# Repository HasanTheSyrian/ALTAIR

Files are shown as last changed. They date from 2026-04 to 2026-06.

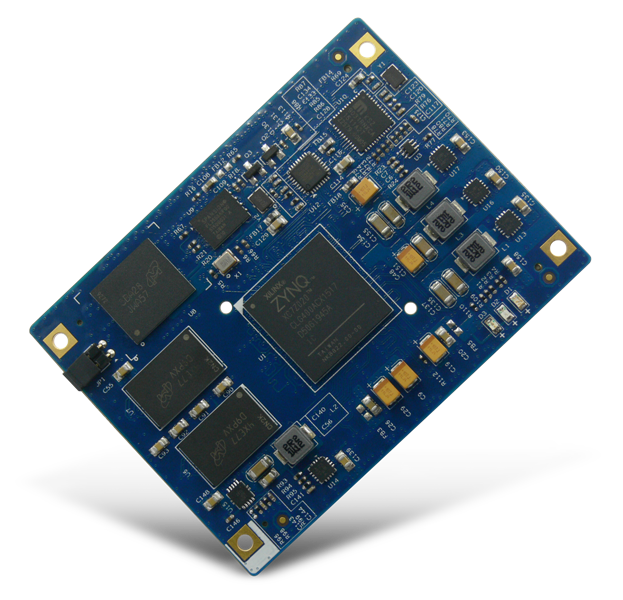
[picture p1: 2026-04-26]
Documentation/MYIR Hardware/Mechanical/images/MYC-C7Z010 20_7.png

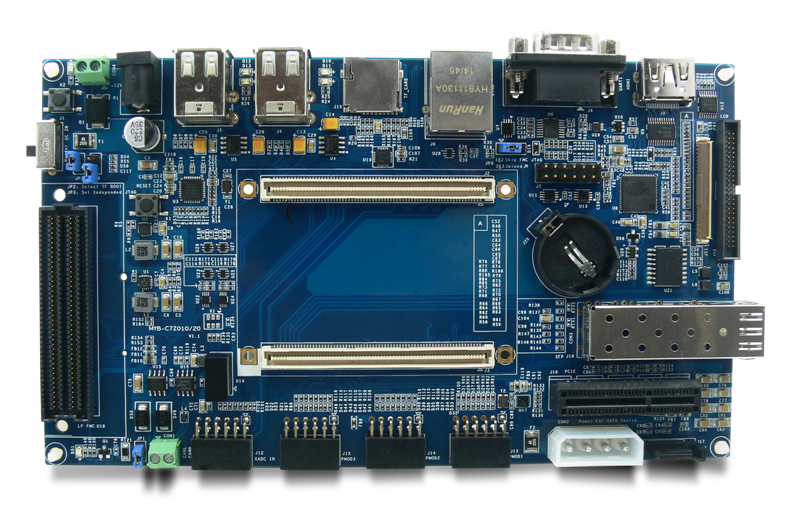
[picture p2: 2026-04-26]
Documentation/MYIR Hardware/Mechanical/images/MYD-C7Z010 20_6.png

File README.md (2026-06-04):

ALTAIR


17 light-years away lies Altair, a star in the Aquila constellation. Altair is the short-form transliteration of Al-Nisr Al-Ta'ir (النسر الطائر) or "The Flying Eagle"; a predator known for its excellent vision.

Altair is an FPGA development board focused on image processing, specifically, stereoscopic depth calculation enabled by two MIPI camera connectors and two HDMI outputs. The board implements XAPP894 since MIPI is not supported natively by Zynq 7000. The development board is built around the MYC-C7Z010_20 SOM. This board is also my graduation project/thesis for my Mechatronics Engineering degree.

---
NOTE: THIS BOARD IS NOT TESTED FULLY YET - SEE BRINGUP SECTION BELOW
### Docs
This board is built with the MYIR MYC-C7Z020-V2 SOM. MYIR documents can only be downloaded after providing the serial number of the MYC-C7Z020-V2 purchased, unfortunately, I can't share mine. Most MYIR hardware documents can be downlodaded from this repository. I haven't included software documents/code because the file size is too big however you can probably find them online elsewhere.

AltairNotes PDF contains my notes I have written over the ~2 years I have been working on this project. Some information is basic stuff about PCB routing and some information documents how I have configured and routed my board. I combined software and hardware PDFS into PDF files ending in "COMBINED" so you can easily search for what you want.

I have also created a YouTube series that talks about the design which can be seen [here](https://www.youtube.com/@hasanthesyrian_).

Not all references are included because I'm not sure if they can be shared directly, however, you should be able to just search for them and download them from their official source.

#### Most important/relevant
| Title | Notes |
| --- |---|
| HARDWARE DOCS COMBINED | MYIR Docs  |
| MYC-C7Z010-20-V2 Hardware Design Guide-V1.0 | MYIR Docs  |
| SOFTWARE DOCS COMBINED | MYIR Docs  |
| MYB-C7Z010_20-V2 Schematic | MYIR Docs  |
| MYD-C7Z01020-V2 PinOuts | MYIR Docs, SOM Pinout  |
| MYC-C7z010-V12-SOM-NET-LENGTH | MYIR Docs  |
| ADV7511_Hardware_Users_Guide | HDMI IC |
| [Zynq 7000 SoC Technical Reference Manual](https://docs.amd.com/r/en-US/ug585-zynq-7000-SoC-TRM) | UG585  |
| [Zynq-7000 SoC PCB Design Guide](https://docs.amd.com/v/u/en-US/ug933-Zynq-7000-PCB) | UG933  |
| [7 Series FPGAs SelectIO Resources User Guide](https://docs.amd.com/v/u/en-US/ug471_7Series_SelectIO) | UG471  |
| [Zynq-7000 SoC Packaging and Pinout Product Specification](https://docs.amd.com/v/u/en-US/ug865-Zynq-7000-Pkg-Pinout) | UG865  |
| xc7z020clg400pkg (.txt) | FPGA Package Pinout  |

#### Board schematics used as references in part
| Title | Notes |
| --- |---|
| MYB-C7Z010_20-V2 Schematic | MYIR Docs  |
| arty_z7_sch | |
| digilent-smt3-reversed-sch | Reverse engineered programmer published on IEEE  |
| eclypse_z7_sch | |
| minized_sch | |
| mizar_z7-sch | |
| pynq-z1_sch | |
| pynq-z2_sch | |
| rehsd_sch | rehsd on YouTube  |
| snickerdoodle_sch | |
| trenz_carrier_TE0701_sch | |
| zc702_sch | |
| zc706-sch | |
| trenz_carrier_TE0701_sch | |
| zc702_sch | |
| zedboard_sch | |
| zybo-z7_sch | |
| zynqberry2010_sch | |
| zynqberry-zero_sch | |
| camera-module-3-schematics | Raspberry Pi |
| cm4io-datasheet | Raspberry Pi |
| raspberry-pi-4-reduced-schematics | Raspberry Pi |

#### AMD Documentaion
| Title | Code |
| --- | --- |
| [Zynq 7000 SoC Technical Reference Manual](https://docs.amd.com/r/en-US/ug585-zynq-7000-SoC-TRM) | UG585  |
| [Zynq-7000 SoC PCB Design Guide](https://docs.amd.com/v/u/en-US/ug933-Zynq-7000-PCB) | UG933  |
| [Zynq-7000 SoC Data Sheet: Overview](https://docs.amd.com/v/u/en-US/ds190-Zynq-7000-Overview) | DS190  |
| [Zynq-7000 SoC Packaging and Pinout Product Specification](https://docs.amd.com/v/u/en-US/ug865-Zynq-7000-Pkg-Pinout) | UG865  |
| [Zynq 7000 SoC and 7 Series Devices Memory Interface Solutions User Guide](https://docs.amd.com/r/en-US/ug586_7Series_MIS/DDR3-and-DDR2-SDRAM-Memory-Interface-Solution) | UG586  |
| [DDR2/DDR3 Low-Cost PCB Design Guidelines for Artix-7/Spartan-7 FPGAs White Paper](https://docs.amd.com/v/u/en-US/wp484-a7-s7-ddr2-3-pcb) | WP484  |
| [7 Series FPGAs and Zynq-7000 SoC XADC Dual 12-Bit 1 MSPS Analog-to-Digital Converter User Guide](https://docs.amd.com/r/en-US/ug480_7Series_XADC) | UG480  |
| [Zynq-7000 SoC Product Selection Guide](https://docs.amd.com/v/u/en-US/zynq-7000-product-selection-guide) | XMP087 |
| [Artix 7 FPGAs Data Sheet: DC and AC Switching Characteristics](https://docs.amd.com/v/u/en-US/ds181_Artix_7_Data_Sheet) | DS181  |
| [Kintex-7 FPGAs Data Sheet: DC and AC Switching Characteristics](https://docs.amd.com/v/u/en-US/ds182_Kintex_7_Data_Sheet) | DS182  |
| [7 Series FPGAs GTP Transceivers User Guide](https://docs.amd.com/v/u/en-US/ug482_7Series_GTP_Transceivers) | UG482  |
| [7 Series FPGAs GTX/GTH Transceivers User Guide](https://docs.amd.com/v/u/en-US/ug476_7Series_Transceivers) | UG476  |
| [7 Series FPGAs PCB Design Guide](https://docs.amd.com/v/u/en-US/ug483_7Series_PCB) | UG483  |
| [Zynq 7000 SoC Software Developers Guide](https://docs.amd.com/r/en-US/ug821-zynq-7000-swdev) | UG821  |
| [Recommended Design Rules and Strategies for BGA Devices User Guide](https://docs.amd.com/r/en-US/ug1099-bga-device-design-rules) | UG1099 |
| [Zynq-7000 SoC DC and AC Switching Characteristics Data Sheet](https://docs.amd.com/v/u/en-US/ds187-XC7Z010-XC7Z020-Data-Sheet) | DS187  |
| [7 Series FPGAs Configuration](https://docs.amd.com/v/u/en-US/ug470_7Series_Config) | UG470  |
| [MIPI D-PHY LogiCORE IP Product Guide](https://docs.amd.com/r/en-US/pg202-mipi-dphy/Introduction) | PG202  |
| [MIPI CSI-2 Receiver Subsystem Product Guide](https://docs.amd.com/r/en-US/pg232-mipi-csi2-rx) | PG232  |
| [Xilinx FPGA Video Design Hub](https://docs.amd.com/v/u/en-US/dh0083-video-hub) | DH235  |
| [HDMI 1.4/2.0 Transmitter Subsystem Product Guide](https://docs.amd.com/r/en-US/pg235-v-hdmi-tx-ss/Introduction?tocId=XLSPfpAut4Tw1N_71V9XKQ) | PG235  |
| [Vivado Design Suite User Guide: I/O and Clock Planning](https://www.xilinx.com/support/documents/sw_manuals/xilinx2022_1/ug899-vivado-io-clock-planning.pdf) | UG899  |
| [7 Series FPGAs SelectIO Resources User Guide](https://docs.amd.com/v/u/en-US/ug471_7Series_SelectIO) | UG471  |

### Other helpful links

| Title | Notes | Code |
| --- | --- | --- |
| [Xilinx Power Estimator](https://www.xilinx.com/products/technology/power/xpe.html) | | |
| [Digilent Arty Z7 Schematics](https://digilent.com/reference/_media/reference/programmable-logic/arty-z7/arty_z7_sch.pdf) | | |
| [Digilent Zed Board Schematics](https://digilent.com/reference/_media/reference/programmable-logic/zedboard/zedboard-schematic-rev-e1-public.pdf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) | HDMI schematic on page 5 | |
| [Xilinx XTP185 – ZC702 Schematics](https://e2e.ti.com/cfs-file/__key/communityserver-discussions-components-files/196/zc702_5F00_Schematic_5F00_xtp185_5F00_rev1_5F00_0.pdf) | link instantly downloads pdf | |
| [TI Power Reference Design for Xilinx Zynq-7000](https://www.ti.com/lit/ug/slyu019a/slyu019a.pdf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) | | |
| [Terasic DE2-115 Schematic](https://wiki.bu.ost.ch/infoportal/_media/fpga/cyclone_iv/de2_115_schematic.pdf) | | |
| [Avnet Minized Board Schematics + General knowledge](http://www.ebvnews.ru/doc17/MiniZed-HW-UG-v1-0-V1_0.pdf) | check page 7 | |
| [How to understand Zynq Pins](https://www.avnet.com/wps/portal/us/products/avnet-boards/support/faq/zynq-pins-deep-dive/) | | |
| [Hardware and Layout Design Considerations for DDR3 SDRAM Memory Interfaces](https://hands.com/~lkcl/eoma/rockchip_rk3288/AN3940.pdf) | | |
| [Gigabit Ethernet 101: Basics to Implementation](https://resources.altium.com/p/gigabit-ethernet-101-basics-implementation) | | |
| [Gigabit Ethernet Design Guide](https://ww1.microchip.com/downloads/aemDocuments/documents/OTH/ApplicationNotes/ApplicationNotes/00002054A.pdf) | | |
| [Ethernet PHY PCB Design Layout Checklist](https://www.ti.com/lit/an/snla387/snla387.pdf?ts=1724186585377&ref_url=https%253A%252F%252Fwww.google.com%252F) | | |
| [TPD12S016 HDMI Companion Chip Datasheet](https://www.ti.com/lit/ds/symlink/tpd12s016.pdf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) | | |
| [MIPI D-PHY Standard](https://www.mipi.org/specifications/d-phy#related-resources-anchor) | | |
| [Zynp Pins - Deep Dive: How to understand Zynq Pins](https://www.avnet.com/wps/portal/us/products/avnet-boards/support/faq/zynq-pins-deep-dive/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)  | Useful | |
| [ADV7511 Hardware User's Guide](https://www.analog.com/media/en/technical-documentation/user-guides/ADV7511_Hardware_Users_Guide.pdf) | "actual" datasheet of ADV7511 | |
| [PCB Design Guidelines for QFN and DQFN Packages](https://ww1.microchip.com/downloads/aemDocuments/documents/UNG/ApplicationNotes/ApplicationNotes/AN18.15-PCB-Design-Guide-QFN-DQFN-Packages-00001843.pdf) | USB2415 USB HUB | AN18.15 |
| [USB Device Design Checklist](https://ww1.microchip.com/downloads/aemDocuments/documents/OTH/ApplicationNotes/ApplicationNotes/00001863B.pdf) | USB2415 USB HUB | AN26.21 |
| [PCB Layout Guide for USB Hubs](https://ww1.microchip.com/downloads/aemDocuments/documents/OTH/ApplicationNotes/ApplicationNotes/en562810.pdf) | USB2415 USB HUB | AN15.17 |
| [PMOD Standard](https://digilent.com/reference/_media/reference/pmod/pmod-interface-specification-1_3_1.pdf) | | |
| Texas Instruments HDMI Design Guide | HDMI | |
| [Texas Instruments The IBIS model, Part 3: Using IBIS models to investigate signal-integrity issues](https://www.ti.com/lit/an/slyt413/slyt413.pdf?ts=1754720541924) | | SLYT413 |

<details>
<summary>Processing System Pins Used</summary>
  *mostly accurate, one of the I2Cs highlighted was not used in the final design double check with the schematic
Pasted image 20250327221556
</details>

### Bringup
28/5/2026: I have soldered the power circuit and tested all rails without load and without an oscilloscope, the power circuit at least provides the correct voltages.



### Images







<details>

<summary>Archive</summary>




</details>

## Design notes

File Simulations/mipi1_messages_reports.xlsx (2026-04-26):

Name | Severity | Details
system
General Messages
IP_Flow 19-4965 | Critical Warning | [IP_Flow 19-4965] IP cdc_fifo was packaged with board value 'em.avnet.com:zed:part0:1.4'. Current project's board value is 'digilentinc.com:zybo-z7-20:part0:1.1'. Please update the project settings to match the packaged IP.
IP_Flow 19-4965 | Critical Warning | [IP_Flow 19-4965] IP ila_rxclk was packaged with board value 'em.avnet.com:zed:part0:1.4'. Current project's board value is 'digilentinc.com:zybo-z7-20:part0:1.1'. Please update the project settings to match the packaged IP.
IP_Flow 19-4965 | Critical Warning | [IP_Flow 19-4965] IP ila_rxclk_lane was packaged with board value 'em.avnet.com:zed:part0:1.4'. Current project's board value is 'digilentinc.com:zybo-z7-20:part0:1.1'. Please update the project settings to match the packaged IP.
IP_Flow 19-4965 | Critical Warning | [IP_Flow 19-4965] IP ila_vidclk was packaged with board value 'em.avnet.com:zed:part0:1.4'. Current project's board value is 'digilentinc.com:zybo-z7-20:part0:1.1'. Please update the project settings to match the packaged IP.
IP_Flow 19-4965 | Critical Warning | [IP_Flow 19-4965] IP line_buffer was packaged with board value 'em.avnet.com:zed:part0:1.4'. Current project's board value is 'digilentinc.com:zybo-z7-20:part0:1.1'. Please update the project settings to match the packaged IP.
Synthesis
Out-of-Context Module Runs
system
system_MIPI_CSI_2_RX_0_0_synth_1
Designutils 20-1280 | Critical Warning | [Designutils 20-1280] Could not find module 'ila_vidclk'. The XDC file c:/Users/hasan/Downloads/Zybo-Z7-20-Pcam-5C-hw.xpr/Zybo-Z7-HW/Zybo-Z7-HW.gen/sources_1/bd/system/ip/system_MIPI_CSI_2_RX_0_0/hdl/ila_vidclk/ila_v6_2/constraints/ila.xdc will not be read for any cell of this module.
Designutils 20-1280 | Critical Warning | [Designutils 20-1280] Could not find module 'ila_rxclk_lane'. The XDC file c:/Users/hasan/Downloads/Zybo-Z7-20-Pcam-5C-hw.xpr/Zybo-Z7-HW/Zybo-Z7-HW.gen/sources_1/bd/system/ip/system_MIPI_CSI_2_RX_0_0/hdl/ila_rxclk_lane/ila_v6_2/constraints/ila.xdc will not be read for any cell of this module.
Designutils 20-1280 | Critical Warning | [Designutils 20-1280] Could not find module 'ila_rxclk'. The XDC file c:/Users/hasan/Downloads/Zybo-Z7-20-Pcam-5C-hw.xpr/Zybo-Z7-HW/Zybo-Z7-HW.gen/sources_1/bd/system/ip/system_MIPI_CSI_2_RX_0_0/hdl/ila_rxclk/ila_v6_2/constraints/ila.xdc will not be read for any cell of this module.
Vivado 12-4739 | Critical Warning | [Vivado 12-4739] set_false_path:No valid object(s) found for '-from [get_pins -hierarchical -filter {NAME =~ *allx_typeA_match_detection.ltlib_v1_0_0_allx_typeA_inst/DUT/I_WHOLE_SLICE.G_SLICE_IDX[*].U_ALL_SRL_SLICE/u_srl*/S*/CLK}]'. ["c:/Users/hasan/Downloads/Zybo-Z7-20-Pcam-5C-hw.xpr/Zybo-Z7-HW/Zybo-Z7-HW.gen/sources_1/bd/system/ip/system_MIPI_CSI_2_RX_0_0/hdl/mipi_csi2_rx.xdc":45]
Vivado 12-4739 | Critical Warning | [Vivado 12-4739] set_false_path:No valid object(s) found for '-from [get_pins -hierarchical -filter { NAME =~ "*ila_core_inst/u_ila_cap_ctrl/u_cap_addrgen/u_cap_sample_counter/u_scnt_cmp/allx_typeA_match_detection.ltlib_v1_0_0_allx_typeA_inst/DUT/I_WHOLE_SLICE.G_SLICE_IDX[*].U_ALL_SRL_SLICE/u_srl*/S*/CLK*"}]'. ["c:/Users/hasan/Downloads/Zybo-Z7-20-Pcam-5C-hw.xpr/Zybo-Z7-HW/Zybo-Z7-HW.gen/sources_1/bd/system/ip/system_MIPI_CSI_2_RX_0_0/hdl/mipi_csi2_rx.xdc":50]
Vivado 12-4739 | Critical Warning | [Vivado 12-4739] set_false_path:No valid object(s) found for '-from [get_pins -hierarchical -filter { NAME =~ "*ila_core_inst/u_ila_cap_ctrl/u_cap_addrgen/u_cap_window_counter/u_wcnt_lcmp/allx_typeA_match_detection.ltlib_v1_0_0_allx_typeA_inst/DUT/I_WHOLE_SLICE.G_SLICE_IDX[*].U_ALL_SRL_SLICE/u_srl*/S*/CLK*"}]'. ["c:/Users/hasan/Downloads/Zybo-Z7-20-Pcam-5C-hw.xpr/Zybo-Z7-HW/Zybo-Z7-HW.gen/sources_1/bd/system/ip/system_MIPI_CSI_2_RX_0_0/hdl/mipi_csi2_rx.xdc":55]
Vivado 12-4739 | Critical Warning | [Vivado 12-4739] set_false_path:No valid object(s) found for '-from [get_pins -hierarchical -filter { NAME =~ "*ila_core_inst/u_ila_cap_ctrl/u_cap_addrgen/u_cap_window_counter/u_wcnt_hcmp/allx_typeA_match_detection.ltlib_v1_0_0_allx_typeA_inst/DUT/I_WHOLE_SLICE.G_SLICE_IDX[*].U_ALL_SRL_SLICE/u_srl*/S*/CLK*"}]'. ["c:/Users/hasan/Downloads/Zybo-Z7-20-Pcam-5C-hw.xpr/Zybo-Z7-HW/Zybo-Z7-HW.gen/sources_1/bd/system/ip/system_MIPI_CSI_2_RX_0_0/hdl/mipi_csi2_rx.xdc":56]
system_MIPI_D_PHY_RX_0_0_synth_1
Designutils 20-1280 | Critical Warning | [Designutils 20-1280] Could not find module 'ila_scnn_refclk'. The XDC file c:/Users/hasan/Downloads/Zybo-Z7-20-Pcam-5C-hw.xpr/Zybo-Z7-HW/Zybo-Z7-HW.gen/sources_1/bd/system/ip/system_MIPI_D_PHY_RX_0_0/hdl/ila_scnn_refclk/ila_v6_2/constraints/ila.xdc will not be read for any cell of this module.
Designutils 20-1280 | Critical Warning | [Designutils 20-1280] Could not find module 'ila_sfen_refclk'. The XDC file c:/Users/hasan/Downloads/Zybo-Z7-20-Pcam-5C-hw.xpr/Zybo-Z7-HW/Zybo-Z7-HW.gen/sources_1/bd/system/ip/system_MIPI_D_PHY_RX_0_0/hdl/ila_sfen_refclk/ila_v6_2/constraints/ila.xdc will not be read for any cell of this module.
Designutils 20-1280 | Critical Warning | [Designutils 20-1280] Could not find module 'ila_sfen_rxclk'. The XDC file c:/Users/hasan/Downloads/Zybo-Z7-20-Pcam-5C-hw.xpr/Zybo-Z7-HW/Zybo-Z7-HW.gen/sources_1/bd/system/ip/system_MIPI_D_PHY_RX_0_0/hdl/ila_sfen_rxclk/ila_v6_2/constraints/ila.xdc will not be read for any cell of this module.
Implementation
Design Initialization
Designutils 20-1280 | Critical Warning | [Designutils 20-1280] Could not find module 'ila_vidclk'. The XDC file c:/Users/hasan/Downloads/Zybo-Z7-20-Pcam-5C-hw.xpr/Zybo-Z7-HW/Zybo-Z7-HW.gen/sources_1/bd/system/ip/system_MIPI_CSI_2_RX_0_0/hdl/ila_vidclk/ila_v6_2/constraints/ila.xdc will not be read for any cell of this module.
Designutils 20-1280 | Critical Warning | [Designutils 20-1280] Could not find module 'ila_rxclk_lane'. The XDC file c:/Users/hasan/Downloads/Zybo-Z7-20-Pcam-5C-hw.xpr/Zybo-Z7-HW/Zybo-Z7-HW.gen/sources_1/bd/system/ip/system_MIPI_CSI_2_RX_0_0/hdl/ila_rxclk_lane/ila_v6_2/constraints/ila.xdc will not be read for any cell of this module.
Designutils 20-1280 | Critical Warning | [Designutils 20-1280] Could not find module 'ila_rxclk'. The XDC file c:/Users/hasan/Downloads/Zybo-Z7-20-Pcam-5C-hw.xpr/Zybo-Z7-HW/Zybo-Z7-HW.gen/sources_1/bd/system/ip/system_MIPI_CSI_2_RX_0_0/hdl/ila_rxclk/ila_v6_2/constraints/ila.xdc will not be read for any cell of this module.
Designutils 20-1280 | Critical Warning | [Designutils 20-1280] Could not find module 'ila_scnn_refclk'. The XDC file c:/Users/hasan/Downloads/Zybo-Z7-20-Pcam-5C-hw.xpr/Zybo-Z7-HW/Zybo-Z7-HW.gen/sources_1/bd/system/ip/system_MIPI_D_PHY_RX_0_0/hdl/ila_scnn_refclk/ila_v6_2/constraints/ila.xdc will not be read for any cell of this module.
Designutils 20-1280 | Critical Warning | [Designutils 20-1280] Could not find module 'ila_sfen_refclk'. The XDC file c:/Users/hasan/Downloads/Zybo-Z7-20-Pcam-5C-hw.xpr/Zybo-Z7-HW/Zybo-Z7-HW.gen/sources_1/bd/system/ip/system_MIPI_D_PHY_RX_0_0/hdl/ila_sfen_refclk/ila_v6_2/constraints/ila.xdc will not be read for any cell of this module.
Designutils 20-1280 | Critical Warning | [Designutils 20-1280] Could not find module 'ila_sfen_rxclk'. The XDC file c:/Users/hasan/Downloads/Zybo-Z7-20-Pcam-5C-hw.xpr/Zybo-Z7-HW/Zybo-Z7-HW.gen/sources_1/bd/system/ip/system_MIPI_D_PHY_RX_0_0/hdl/ila_sfen_rxclk/ila_v6_2/constraints/ila.xdc will not be read for any cell of this module.
Common 17-55 | Critical Warning | [Common 17-55] 'set_property' expects at least one object. ["C:/Users/hasan/Downloads/Zybo-Z7-20-Pcam-5C-hw.xpr/Zybo-Z7-HW/Zybo-Z7-HW.srcs/constrs_1/imports/constraints/auto.xdc":9]
Common 17-55 | Critical Warning | [Common 17-55] 'set_property' expects at least one object. ["C:/Users/hasan/Downloads/Zybo-Z7-20-Pcam-5C-hw.xpr/Zybo-Z7-HW/Zybo-Z7-HW.srcs/constrs_1/imports/constraints/auto.xdc":10]
Common 17-55 | Critical Warning | [Common 17-55] 'set_property' expects at least one object. ["C:/Users/hasan/Downloads/Zybo-Z7-20-Pcam-5C-hw.xpr/Zybo-Z7-HW/Zybo-Z7-HW.srcs/constrs_1/imports/constraints/auto.xdc":11]
Vivado 12-1419 | Critical Warning | [Vivado 12-1419] Debug core 'dbg_hub' was not found. ["C:/Users/hasan/Downloads/Zybo-Z7-20-Pcam-5C-hw.xpr/Zybo-Z7-HW/Zybo-Z7-HW.srcs/constrs_1/imports/constraints/auto.xdc":12]
Route Design
Timing 38-282 | Critical Warning | [Timing 38-282] The design failed to meet the timing requirements. Please see the timing summary report for details on the timing violations.
impl_1
General Messages
Timing 38-282 | Critical Warning | [Timing 38-282] The design failed to meet the timing requirements. Please see the timing summary report for details on the timing violations.

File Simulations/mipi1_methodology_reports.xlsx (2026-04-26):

Name | Severity | Details
All Violations (26)
Timing (21)
Bad Practice (21)
TIMING-1
TIMING #1 | Critical Warning | Invalid clock waveform for clock pixel_dynclk specified at a BUFR output system_i/DVIClocking_0/U0/PixelClkBuffer/O that does not match the CMB settings. The waveform of the clock is 6.734 {0 3.367}. The expected waveform is 8.335 {0 3.334}
TIMING #2 | Critical Warning | Invalid clock waveform for clock video_dynclk specified at a MMCME2_ADV output system_i/video_dynclk/inst/CLK_CORE_DRP_I/clk_inst/mmcm_adv_inst/CLKOUT0 that does not match the CMB settings. The waveform of the clock is 1.667 {0 0.8335}. The expected waveform is 1.347 {0 0.6734}
TIMING-3
TIMING #1 | Critical Warning | A primary clock pixel_dynclk is created on the output pin or net system_i/DVIClocking_0/U0/PixelClkBuffer/O of a Clock Modifying Block
TIMING #2 | Critical Warning | A primary clock video_dynclk is created on the output pin or net system_i/video_dynclk/inst/CLK_CORE_DRP_I/clk_inst/mmcm_adv_inst/CLKOUT0 of a Clock Modifying Block
TIMING-9
TIMING #1 | Warning | One or more asynchronous Clock Domain Crossing has been detected between 2 clock domains through a set_false_path or a set_clock_groups or set_max_delay -datapath_only constraint but no double-registers logic synchronizer has been found on the side of the capture clock. It is recommended to run report_cdc for a complete and detailed CDC coverage. Please consider using XPM_CDC to avoid Critical severities
TIMING-15
TIMING #1 | Warning | There is a large clock skew of 1.008 ns between dphy_data_hs_p[0] (clocked by dphy_hs_clock_p) and system_i/MIPI_D_PHY_RX_0/U0/DataLaneGen[0].DPHY_LaneSFEN_X/HSDeserializerX/Deserializer/DDLY (clocked by dphy_hs_clock_p) that results in large hold timing violation(s) of -1.008 ns. Fixing large hold violations during routing might impact setup slack and result in more difficult timing closure
TIMING #2 | Warning | There is a large clock skew of 1.008 ns between dphy_data_hs_p[1] (clocked by dphy_hs_clock_p) and system_i/MIPI_D_PHY_RX_0/U0/DataLaneGen[1].DPHY_LaneSFEN_X/HSDeserializerX/Deserializer/DDLY (clocked by dphy_hs_clock_p) that results in large hold timing violation(s) of -1.101 ns. Fixing large hold violations during routing might impact setup slack and result in more difficult timing closure
TIMING-16
TIMING #1 | Warning | There is a large setup violation of -2.346 ns between dphy_data_hs_n[1] (clocked by dphy_hs_clock_p) and system_i/MIPI_D_PHY_RX_0/U0/DataLaneGen[1].DPHY_LaneSFEN_X/HSDeserializerX/Deserializer/DDLY (clocked by dphy_hs_clock_p). Large setup violations at the end of those stages might be difficult to fix during the post-placement implementation flow and could be the result of non-optimal XDC constraints or non-optimal design architecture
TIMING #2 | Warning | There is a large setup violation of -2.439 ns between dphy_data_hs_n[0] (clocked by dphy_hs_clock_p) and system_i/MIPI_D_PHY_RX_0/U0/DataLaneGen[0].DPHY_LaneSFEN_X/HSDeserializerX/Deserializer/DDLY (clocked by dphy_hs_clock_p). Large setup violations at the end of those stages might be difficult to fix during the post-placement implementation flow and could be the result of non-optimal XDC constraints or non-optimal design architecture
TIMING-18
TIMING #1 | Warning | An input delay is missing on dphy_data_lp_n[0] relative to the rising and/or falling clock edge(s) of dphy_hs_clock_p.
TIMING #2 | Warning | An input delay is missing on dphy_data_lp_n[1] relative to the rising and/or falling clock edge(s) of dphy_hs_clock_p.
TIMING #3 | Warning | An input delay is missing on dphy_data_lp_p[0] relative to the rising and/or falling clock edge(s) of dphy_hs_clock_p.
TIMING #4 | Warning | An input delay is missing on dphy_data_lp_p[1] relative to the rising and/or falling clock edge(s) of dphy_hs_clock_p.
TIMING #5 | Warning | An output delay is missing on hdmi_tx_clk_n relative to the rising and/or falling clock edge(s) of video_dynclk.
TIMING #6 | Warning | An output delay is missing on hdmi_tx_clk_p relative to the rising and/or falling clock edge(s) of video_dynclk.
TIMING #7 | Warning | An output delay is missing on hdmi_tx_data_n[0] relative to the rising and/or falling clock edge(s) of video_dynclk.
TIMING #8 | Warning | An output delay is missing on hdmi_tx_data_n[1] relative to the rising and/or falling clock edge(s) of video_dynclk.
TIMING #9 | Warning | An output delay is missing on hdmi_tx_data_n[2] relative to the rising and/or falling clock edge(s) of video_dynclk.
TIMING #10 | Warning | An output delay is missing on hdmi_tx_data_p[0] relative to the rising and/or falling clock edge(s) of video_dynclk.
TIMING #11 | Warning | An output delay is missing on hdmi_tx_data_p[1] relative to the rising and/or falling clock edge(s) of video_dynclk.
TIMING #12 | Warning | An output delay is missing on hdmi_tx_data_p[2] relative to the rising and/or falling clock edge(s) of video_dynclk.
Netlist (4)
Design Level (4)
LUT loads (4)
LUTAR-1
LUTAR #1 | Warning | LUT cell system_i/MIPI_D_PHY_RX_0/U0/ClockLane/SyncAsyncEnable/GenNoMMCM.cBUFR_Rst_i_1, with 2 or more inputs, drives asynchronous preset/clear pin(s) system_i/MIPI_D_PHY_RX_0/U0/ClockLane/SyncAsyncLocked/oSyncStages_reg[0]/CLR system_i/MIPI_D_PHY_RX_0/U0/ClockLane/SyncAsyncLocked/oSyncStages_reg[1]/CLR. The LUT may glitch and trigger an unexpected reset, even if it is a properly timed path.
LUTAR #2 | Warning | LUT cell system_i/axi_mem_intercon/s00_couplers/auto_pc/inst/gen_axi4_axi3.axi3_conv_inst/USE_READ.USE_SPLIT_R.read_addr_inst/USE_R_CHANNEL.cmd_queue/inst/fifo_gen_inst/inst_fifo_gen/gconvfifo.rf/grf.rf/rstblk/gpregsm1.curr_fwft_state[1]_i_2, with 2 or more inputs, drives asynchronous preset/clear pin(s) system_i/axi_mem_intercon/s00_couplers/auto_pc/inst/gen_axi4_axi3.axi3_conv_inst/USE_READ.USE_SPLIT_R.read_addr_inst/USE_R_CHANNEL.cmd_queue/inst/fifo_gen_inst/inst_fifo_gen/gconvfifo.rf/grf.rf/gntv_or_sync_fifo.gl0.rd/rpntr/gc0.count_reg[2]/CLR, system_i/axi_mem_intercon/s00_couplers/auto_pc/inst/gen_axi4_axi3.axi3_conv_inst/USE_READ.USE_SPLIT_R.read_addr_inst/USE_R_CHANNEL.cmd_queue/inst/fifo_gen_inst/inst_fifo_gen/gconvfifo.rf/grf.rf/gntv_or_sync_fifo.gl0.rd/rpntr/gc0.count_reg[3]/CLR, system_i/axi_mem_intercon/s00_couplers/auto_pc/inst/gen_axi4_axi3.axi3_conv_inst/USE_READ.USE_SPLIT_R.read_addr_inst/USE_R_CHANNEL.cmd_queue/inst/fifo_gen_inst/inst_fifo_gen/gconvfifo.rf/grf.rf/gntv_or_sync_fifo.gl0.rd/rpntr/gc0.count_reg[4]/CLR, system_i/axi_mem_intercon/s00_couplers/auto_pc/inst/gen_axi4_axi3.axi3_conv_inst/USE_READ.USE_SPLIT_R.read_addr_inst/USE_R_CHANNEL.cmd_queue/inst/fifo_gen_inst/inst_fifo_gen/gconvfifo.rf/grf.rf/gntv_or_sync_fifo.gl0.wr/gwss.wsts/ram_full_fb_i_reg/CLR, system_i/axi_mem_intercon/s00_couplers/auto_pc/inst/gen_axi4_axi3.axi3_conv_inst/USE_READ.USE_SPLIT_R.read_addr_inst/USE_R_CHANNEL.cmd_queue/inst/fifo_gen_inst/inst_fifo_gen/gconvfifo.rf/grf.rf/gntv_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
LUTAR #3 | Warning | LUT cell system_i/axi_mem_intercon_1/s00_couplers/auto_pc/inst/gen_axi4_axi3.axi3_conv_inst/USE_WRITE.write_addr_inst/USE_BURSTS.cmd_queue/inst/fifo_gen_inst/inst_fifo_gen/gconvfifo.rf/grf.rf/rstblk/gpregsm1.curr_fwft_state[1]_i_2, with 2 or more inputs, drives asynchronous preset/clear pin(s) system_i/axi_mem_intercon_1/s00_couplers/auto_pc/inst/gen_axi4_axi3.axi3_conv_inst/USE_WRITE.write_addr_inst/USE_BURSTS.cmd_queue/inst/fifo_gen_inst/inst_fifo_gen/gconvfifo.rf/grf.rf/gntv_or_sync_fifo.gl0.rd/rpntr/gc0.count_reg[2]/CLR, system_i/axi_mem_intercon_1/s00_couplers/auto_pc/inst/gen_axi4_axi3.axi3_conv_inst/USE_WRITE.write_addr_inst/USE_BURSTS.cmd_queue/inst/fifo_gen_inst/inst_fifo_gen/gconvfifo.rf/grf.rf/gntv_or_sync_fifo.gl0.rd/rpntr/gc0.count_reg[3]/CLR, system_i/axi_mem_intercon_1/s00_couplers/auto_pc/inst/gen_axi4_axi3.axi3_conv_inst/USE_WRITE.write_addr_inst/USE_BURSTS.cmd_queue/inst/fifo_gen_inst/inst_fifo_gen/gconvfifo.rf/grf.rf/gntv_or_sync_fifo.gl0.rd/rpntr/gc0.count_reg[4]/CLR, system_i/axi_mem_intercon_1/s00_couplers/auto_pc/inst/gen_axi4_axi3.axi3_conv_inst/USE_WRITE.write_addr_inst/USE_BURSTS.cmd_queue/inst/fifo_gen_inst/inst_fifo_gen/gconvfifo.rf/grf.rf/gntv_or_sync_fifo.gl0.wr/gwss.wsts/ram_full_fb_i_reg/CLR, system_i/axi_mem_intercon_1/s00_couplers/auto_pc/inst/gen_axi4_axi3.axi3_conv_inst/USE_WRITE.write_addr_inst/USE_BURSTS.cmd_queue/inst/fifo_gen_inst/inst_fifo_gen/gconvfifo.rf/grf.rf/gntv_or_sync_fifo.gl0.wr/gwss.wsts/ram_full_i_reg/CLR, system_i/axi_mem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
LUTAR #4 | Warning | LUT cell system_i/axi_mem_intercon_1/s00_couplers/auto_pc/inst/gen_axi4_axi3.axi3_conv_inst/USE_WRITE.write_addr_inst/USE_B_CHANNEL.cmd_b_queue/inst/fifo_gen_inst/inst_fifo_gen/gconvfifo.rf/grf.rf/rstblk/gpregsm1.curr_fwft_state[1]_i_2, with 2 or more inputs, drives asynchronous preset/clear pin(s) system_i/axi_mem_intercon_1/s00_couplers/auto_pc/inst/gen_axi4_axi3.axi3_conv_inst/USE_WRITE.write_addr_inst/USE_B_CHANNEL.cmd_b_queue/inst/fifo_gen_inst/inst_fifo_gen/gconvfifo.rf/grf.rf/gntv_or_sync_fifo.gl0.rd/rpntr/gc0.count_reg[2]/CLR, system_i/axi_mem_intercon_1/s00_couplers/auto_pc/inst/gen_axi4_axi3.axi3_conv_inst/USE_WRITE.write_addr_inst/USE_B_CHANNEL.cmd_b_queue/inst/fifo_gen_inst/inst_fifo_gen/gconvfifo.rf/grf.rf/gntv_or_sync_fifo.gl0.rd/rpntr/gc0.count_reg[3]/CLR, system_i/axi_mem_intercon_1/s00_couplers/auto_pc/inst/gen_axi4_axi3.axi3_conv_inst/USE_WRITE.write_addr_inst/USE_B_CHANNEL.cmd_b_queue/inst/fifo_gen_inst/inst_fifo_gen/gconvfifo.rf/grf.rf/gntv_or_sync_fifo.gl0.rd/rpntr/gc0.count_reg[4]/CLR, system_i/axi_mem_intercon_1/s00_couplers/auto_pc/inst/gen_axi4_axi3.axi3_conv_inst/USE_WRITE.write_addr_inst/USE_B_CHANNEL.cmd_b_queue/inst/fifo_gen_inst/inst_fifo_gen/gconvfifo.rf/grf.rf/gntv_or_sync_fifo.gl0.wr/gwss.wsts/ram_full_fb_i_reg/CLR, system_i/axi_mem_intercon_1/s00_couplers/auto_pc/inst/gen_axi4_axi3.axi3_conv_inst/USE_WRITE.write_addr_inst/USE_B_CHANNEL.cmd_b_queue/inst/fifo_gen_inst/inst_fifo_gen/gconvfifo.rf/grf.rf/gntv_or_sync_fifo.gl0.wr/gwss.wsts/ram_fu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
XDC (1)
Bad Practice (1)
XDCB-5
XDCB #1 | Warning | The option '-through : [get_pins -filter {NAME =~ *SyncAsync*/oSyncStages_reg[0]/D} -hier]' of constraint 'set_false_path' uses inefficient query to find pin objects (see constraint position '7' in the Timing Constraint window in Vivado IDE). To reduce runtime, it is recommended to get the pins through the cell objects. Please refer to Using Constraints Guide (Constraints Efficiency). An example of optimal query is: get_pins -filter {REF_PIN_NAME=~yy*} -of_objects [get_cells -hierarchical xx*]. Current XDC: c:/Users/hasan/Downloads/Zybo-Z7-20-Pcam-5C-hw.xpr/Zybo-Z7-HW/Zybo-Z7-HW.gen/sources_1/bd/system/ip/system_rgb2dvi_0_0/src/rgb2dvi.xdc (Line: 5)

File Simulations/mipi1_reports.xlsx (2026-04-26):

Name | Severity | Details
All Violations (25)
Physical Configuration (8)
Chip Level (4)
PDCN-1569
PDCN #1 | Warning | Used physical LUT pin 'A1' of cell system_i/axi_mem_intercon_1/s00_couplers/auto_pc/inst/gen_axi4_axi3.axi3_conv_inst/USE_WRITE.write_addr_inst/USE_BURSTS.cmd_queue/inst/fifo_gen_inst/inst_fifo_gen/gconvfifo.rf/grf.rf/gntv_or_sync_fifo.gl0.rd/gr1.gr1_int.rfwft/gpregsm1.user_valid_i_1 (pin system_i/axi_mem_intercon_1/s00_couplers/auto_pc/inst/gen_axi4_axi3.axi3_conv_inst/USE_WRITE.write_addr_inst/USE_BURSTS.cmd_queue/inst/fifo_gen_inst/inst_fifo_gen/gconvfifo.rf/grf.rf/gntv_or_sync_fifo.gl0.rd/gr1.gr1_int.rfwft/gpregsm1.user_valid_i_1/I1) is not included in the LUT equation: 'O6=(A2)+((~A2)*(~A6)*A3)'. If this cell is a user instantiated LUT in the design, please remove connectivity to the pin or change the equation and/or INIT string of the LUT to prevent this issue. If the cell is inferred or IP created LUT, please regenerate the IP and/or resynthesize the design to attempt to correct the issue.
PDCN #2 | Warning | Used physical LUT pin 'A2' of cell system_i/axi_mem_intercon/s00_couplers/auto_pc/inst/gen_axi4_axi3.axi3_conv_inst/USE_READ.USE_SPLIT_R.read_addr_inst/USE_R_CHANNEL.cmd_queue/inst/fifo_gen_inst/inst_fifo_gen/gconvfifo.rf/grf.rf/gntv_or_sync_fifo.gl0.rd/gr1.gr1_int.rfwft/gpregsm1.user_valid_i_1 (pin system_i/axi_mem_intercon/s00_couplers/auto_pc/inst/gen_axi4_axi3.axi3_conv_inst/USE_READ.USE_SPLIT_R.read_addr_inst/USE_R_CHANNEL.cmd_queue/inst/fifo_gen_inst/inst_fifo_gen/gconvfifo.rf/grf.rf/gntv_or_sync_fifo.gl0.rd/gr1.gr1_int.rfwft/gpregsm1.user_valid_i_1/I1) is not included in the LUT equation: 'O6=(A3)+((~A3)*(~A6)*A1)'. If this cell is a user instantiated LUT in the design, please remove connectivity to the pin or change the equation and/or INIT string of the LUT to prevent this issue. If the cell is inferred or IP created LUT, please regenerate the IP and/or resynthesize the design to attempt to correct the issue.
PDCN #3 | Warning | Used physical LUT pin 'A3' of cell system_i/axi_mem_intercon_1/s00_couplers/auto_pc/inst/gen_axi4_axi3.axi3_conv_inst/USE_WRITE.write_addr_inst/USE_B_CHANNEL.cmd_b_queue/inst/fifo_gen_inst/inst_fifo_gen/gconvfifo.rf/grf.rf/gntv_or_sync_fifo.gl0.rd/gr1.gr1_int.rfwft/gpregsm1.user_valid_i_1 (pin system_i/axi_mem_intercon_1/s00_couplers/auto_pc/inst/gen_axi4_axi3.axi3_conv_inst/USE_WRITE.write_addr_inst/USE_B_CHANNEL.cmd_b_queue/inst/fifo_gen_inst/inst_fifo_gen/gconvfifo.rf/grf.rf/gntv_or_sync_fifo.gl0.rd/gr1.gr1_int.rfwft/gpregsm1.user_valid_i_1/I1) is not included in the LUT equation: 'O6=(A2)+((~A2)*(~A6)*A5)'. If this cell is a user instantiated LUT in the design, please remove connectivity to the pin or change the equation and/or INIT string of the LUT to prevent this issue. If the cell is inferred or IP created LUT, please regenerate the IP and/or resynthesize the design to attempt to correct the issue.
PDCN #4 | Warning | Used physical LUT pin 'A4' of cell system_i/MIPI_CSI_2_RX_0/U0/MIPI_CSI2_Rx_inst/LLP_inst/DataFIFO/U0/inst_fifo_gen/gaxis_fifo.gaxisf.axisf/grf.rf/gntv_or_sync_fifo.gl0.rd/gr1.gr1_int.rfwft/gpregsm1.user_valid_i_1 (pin system_i/MIPI_CSI_2_RX_0/U0/MIPI_CSI2_Rx_inst/LLP_inst/DataFIFO/U0/inst_fifo_gen/gaxis_fifo.gaxisf.axisf/grf.rf/gntv_or_sync_fifo.gl0.rd/gr1.gr1_int.rfwft/gpregsm1.user_valid_i_1/I1) is not included in the LUT equation: 'O6=(A2)+((~A2)*(~A6)*A3)'. If this cell is a user instantiated LUT in the design, please remove connectivity to the pin or change the equation and/or INIT string of the LUT to prevent this issue. If the cell is inferred or IP created LUT, please regenerate the IP and/or resynthesize the design to attempt to correct the issue.
Physical design rule (4)
SLICEL (2)
PDRC-136
PDRC #1 | Warning | Luts C6LUT and C5LUT in use in site SLICE_X48Y101 with different equations without A6 pin connected to Global Logic High.
PDRC-138
PDRC #1 | Warning | Luts D6LUT and D5LUT in use in site SLICE_X48Y101 with different equations without A6 pin connected to Global Logic High.
SLICEM (2)
PDRC-144
PDRC #1 | Warning | Luts C6LUT and C5LUT in use in site SLICE_X50Y94 with different equations without A6 pin connected to Global Logic High.
PDRC-146
PDRC #1 | Warning | Luts D6LUT and D5LUT in use in site SLICE_X50Y94 with different equations without A6 pin connected to Global Logic High.
Netlist (16)
Instance (16)
Required Pin (16)
RAMB36E1 (10)
REQP-1839
REQP #1 | Warning | The RAMB36E1 system_i/axi_vdma_0/U0/I_PRMRY_DATAMOVER/GEN_MM2S_FULL.I_MM2S_FULL_WRAPPER/GEN_INCLUDE_MM2S_SF.I_RD_SF/I_DATA_FIFO/BLK_MEM.I_SYNC_FIFOGEN_FIFO/xpm_fifo_instance.xpm_fifo_sync_inst/xpm_fifo_base_inst/gen_sdpram.xpm_memory_base_inst/gen_wr_a.gen_word_narrow.mem_reg_0 has an input control pin system_i/axi_vdma_0/U0/I_PRMRY_DATAMOVER/GEN_MM2S_FULL.I_MM2S_FULL_WRAPPER/GEN_INCLUDE_MM2S_SF.I_RD_SF/I_DATA_FIFO/BLK_MEM.I_SYNC_FIFOGEN_FIFO/xpm_fifo_instance.xpm_fifo_sync_inst/xpm_fifo_base_inst/gen_sdpram.xpm_memory_base_inst/gen_wr_a.gen_word_narrow.mem_reg_0/WEBWE[0] (net: system_i/axi_vdma_0/U0/I_PRMRY_DATAMOVER/GEN_MM2S_FULL.I_MM2S_FULL_WRAPPER/GEN_INCLUDE_MM2S_SF.I_RD_SF/I_DATA_FIFO/BLK_MEM.I_SYNC_FIFOGEN_FIFO/xpm_fifo_instance.xpm_fifo_sync_inst/xpm_fifo_base_inst/gen_sdpram.xpm_memory_base_inst/wea[0]) which is driven by a register (system_i/axi_mem_intercon/s00_couplers/auto_pc/inst/gen_axi4_axi3.axi3_conv_inst/USE_READ.USE_SPLIT_R.read_addr_inst/USE_R_CHANNEL.cmd_queue/inst/fifo_gen_inst/inst_fifo_gen/gconvfifo.rf/grf.rf/gntv_or_sync_fifo.gl0.rd/gr1.gr1_int.rfwft/empty_fwft_i_reg) that has an active asychronous set or reset. This may cause corruption of the memory contents and/or read values when the set/reset is asserted and is not analyzed by the default static timing analysis. It is suggested to eliminate the use of a set/reset to registers driving this RAMB pin or else use a synchronous reset in which the assertion of the reset is timed by default.
REQP #2 | Warning | The RAMB36E1 system_i/axi_vdma_0/U0/I_PRMRY_DATAMOVER/GEN_MM2S_FULL.I_MM2S_FULL_WRAPPER/GEN_INCLUDE_MM2S_SF.I_RD_SF/I_DATA_FIFO/BLK_MEM.I_SYNC_FIFOGEN_FIFO/xpm_fifo_instance.xpm_fifo_sync_inst/xpm_fifo_base_inst/gen_sdpram.xpm_memory_base_inst/gen_wr_a.gen_word_narrow.mem_reg_0 has an input control pin system_i/axi_vdma_0/U0/I_PRMRY_DATAMOVER/GEN_MM2S_FULL.I_MM2S_FULL_WRAPPER/GEN_INCLUDE_MM2S_SF.I_RD_SF/I_DATA_FIFO/BLK_MEM.I_SYNC_FIFOGEN_FIFO/xpm_fifo_instance.xpm_fifo_sync_inst/xpm_fifo_base_inst/gen_sdpram.xpm_memory_base_inst/gen_wr_a.gen_word_narrow.mem_reg_0/WEBWE[1] (net: system_i/axi_vdma_0/U0/I_PRMRY_DATAMOVER/GEN_MM2S_FULL.I_MM2S_FULL_WRAPPER/GEN_INCLUDE_MM2S_SF.I_RD_SF/I_DATA_FIFO/BLK_MEM.I_SYNC_FIFOGEN_FIFO/xpm_fifo_instance.xpm_fifo_sync_inst/xpm_fifo_base_inst/gen_sdpram.xpm_memory_base_inst/wea[0]) which is driven by a register (system_i/axi_mem_intercon/s00_couplers/auto_pc/inst/gen_axi4_axi3.axi3_conv_inst/USE_READ.USE_SPLIT_R.read_addr_inst/USE_R_CHANNEL.cmd_queue/inst/fifo_gen_inst/inst_fifo_gen/gconvfifo.rf/grf.rf/gntv_or_sync_fifo.gl0.rd/gr1.gr1_int.rfwft/empty_fwft_i_reg) that has an active asychronous set or reset. This may cause corruption of the memory contents and/or read values when the set/reset is asserted and is not analyzed by the default static timing analysis. It is suggested to eliminate the use of a set/reset to registers driving this RAMB pin or else use a synchronous reset in which the assertion of the reset is timed by default.
REQP #3 | Warning | The RAMB36E1 system_i/axi_vdma_0/U0/I_PRMRY_DATAMOVER/GEN_MM2S_FULL.I_MM2S_FULL_WRAPPER/GEN_INCLUDE_MM2S_SF.I_RD_SF/I_DATA_FIFO/BLK_MEM.I_SYNC_FIFOGEN_FIFO/xpm_fifo_instance.xpm_fifo_sync_inst/xpm_fifo_base_inst/gen_sdpram.xpm_memory_base_inst/gen_wr_a.gen_word_narrow.mem_reg_0 has an input control pin system_i/axi_vdma_0/U0/I_PRMRY_DATAMOVER/GEN_MM2S_FULL.I_MM2S_FULL_WRAPPER/GEN_INCLUDE_MM2S_SF.I_RD_SF/I_DATA_FIFO/BLK_MEM.I_SYNC_FIFOGEN_FIFO/xpm_fifo_instance.xpm_fifo_sync_inst/xpm_fifo_base_inst/gen_sdpram.xpm_memory_base_inst/gen_wr_a.gen_word_narrow.mem_reg_0/WEBWE[2] (net: system_i/axi_vdma_0/U0/I_PRMRY_DATAMOVER/GEN_MM2S_FULL.I_MM2S_FULL_WRAPPER/GEN_INCLUDE_MM2S_SF.I_RD_SF/I_DATA_FIFO/BLK_MEM.I_SYNC_FIFOGEN_FIFO/xpm_fifo_instance.xpm_fifo_sync_inst/xpm_fifo_base_inst/gen_sdpram.xpm_memory_base_inst/wea[0]) which is driven by a register (system_i/axi_mem_intercon/s00_couplers/auto_pc/inst/gen_axi4_axi3.axi3_conv_inst/USE_READ.USE_SPLIT_R.read_addr_inst/USE_R_CHANNEL.cmd_queue/inst/fifo_gen_inst/inst_fifo_gen/gconvfifo.rf/grf.rf/gntv_or_sync_fifo.gl0.rd/gr1.gr1_int.rfwft/empty_fwft_i_reg) that has an active asychronous set or reset. This may cause corruption of the memory contents and/or read values when the set/reset is asserted and is not analyzed by the default static timing analysis. It is suggested to eliminate the use of a set/reset to registers driving this RAMB pin or else use a synchronous reset in which the assertion of the reset is timed by default.
REQP #4 | Warning | The RAMB36E1 system_i/axi_vdma_0/U0/I_PRMRY_DATAMOVER/GEN_MM2S_FULL.I_MM2S_FULL_WRAPPER/GEN_INCLUDE_MM2S_SF.I_RD_SF/I_DATA_FIFO/BLK_MEM.I_SYNC_FIFOGEN_FIFO/xpm_fifo_instance.xpm_fifo_sync_inst/xpm_fifo_base_inst/gen_sdpram.xpm_memory_base_inst/gen_wr_a.gen_word_narrow.mem_reg_0 has an input control pin system_i/axi_vdma_0/U0/I_PRMRY_DATAMOVER/GEN_MM2S_FULL.I_MM2S_FULL_WRAPPER/GEN_INCLUDE_MM2S_SF.I_RD_SF/I_DATA_FIFO/BLK_MEM.I_SYNC_FIFOGEN_FIFO/xpm_fifo_instance.xpm_fifo_sync_inst/xpm_fifo_base_inst/gen_sdpram.xpm_memory_base_inst/gen_wr_a.gen_word_narrow.mem_reg_0/WEBWE[3] (net: system_i/axi_vdma_0/U0/I_PRMRY_DATAMOVER/GEN_MM2S_FULL.I_MM2S_FULL_WRAPPER/GEN_INCLUDE_MM2S_SF.I_RD_SF/I_DATA_FIFO/BLK_MEM.I_SYNC_FIFOGEN_FIFO/xpm_fifo_instance.xpm_fifo_sync_inst/xpm_fifo_base_inst/gen_sdpram.xpm_memory_base_inst/wea[0]) which is driven by a register (system_i/axi_mem_intercon/s00_couplers/auto_pc/inst/gen_axi4_axi3.axi3_conv_inst/USE_READ.USE_SPLIT_R.read_addr_inst/USE_R_CHANNEL.cmd_queue/inst/fifo_gen_inst/inst_fifo_gen/gconvfifo.rf/grf.rf/gntv_or_sync_fifo.gl0.rd/gr1.gr1_int.rfwft/empty_fwft_i_reg) that has an active asychronous set or reset. This may cause corruption of the memory contents and/or read values when the set/reset is asserted and is not analyzed by the default static timing analysis. It is suggested to eliminate the use of a set/reset to registers driving this RAMB pin or else use a synchronous reset in which the assertion of the reset is timed by default.
REQP #5 | Warning | The RAMB36E1 system_i/axi_vdma_0/U0/I_PRMRY_DATAMOVER/GEN_MM2S_FULL.I_MM2S_FULL_WRAPPER/GEN_INCLUDE_MM2S_SF.I_RD_SF/I_DATA_FIFO/BLK_MEM.I_SYNC_FIFOGEN_FIFO/xpm_fifo_instance.xpm_fifo_sync_inst/xpm_fifo_base_inst/gen_sdpram.xpm_memory_base_inst/gen_wr_a.gen_word_narrow.mem_reg_0 has an input control pin system_i/axi_vdma_0/U0/I_PRMRY_DATAMOVER/GEN_MM2S_FULL.I_MM2S_FULL_WRAPPER/GEN_INCLUDE_MM2S_SF.I_RD_SF/I_DATA_FIFO/BLK_MEM.I_SYNC_FIFOGEN_FIFO/xpm_fifo_instance.xpm_fifo_sync_inst/xpm_fifo_base_inst/gen_sdpram.xpm_memory_base_inst/gen_wr_a.gen_word_narrow.mem_reg_0/WEBWE[4] (net: system_i/axi_vdma_0/U0/I_PRMRY_DATAMOVER/GEN_MM2S_FULL.I_MM2S_FULL_WRAPPER/GEN_INCLUDE_MM2S_SF.I_RD_SF/I_DATA_FIFO/BLK_MEM.I_SYNC_FIFOGEN_FIFO/xpm_fifo_instance.xpm_fifo_sync_inst/xpm_fifo_base_inst/gen_sdpram.xpm_memory_base_inst/wea[0]) which is driven by a register (system_i/axi_mem_intercon/s00_couplers/auto_pc/inst/gen_axi4_axi3.axi3_conv_inst/USE_READ.USE_SPLIT_R.read_addr_inst/USE_R_CHANNEL.cmd_queue/inst/fifo_gen_inst/inst_fifo_gen/gconvfifo.rf/grf.rf/gntv_or_sync_fifo.gl0.rd/gr1.gr1_int.rfwft/empty_fwft_i_reg) that has an active asychronous set or reset. This may cause corruption of the memory contents and/or read values when the set/reset is asserted and is not analyzed by the default static timing analysis. It is suggested to eliminate the use of a set/reset to registers driving this RAMB pin or else use a synchronous reset in which the assertion of the reset is timed by default.
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

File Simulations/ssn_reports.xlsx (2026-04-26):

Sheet: ssn_2hdmitx_3v3
Column1 | Column2 | Column3 | Column4 | Column5 | Column6 | Column7 | Column8 | Column9 | Column10 | Column11
# Simultaneously Switching Noise (SSN) Report
# Version: 1.0
# Created on: Wed Aug 20 13:09:49 2025
# Result Name: ssn_2hdmitx_3v3
# Project Name: ALTAIR_PINPLANNING
# Project Family: Zynq-7000
# Part: xc7z020clg400
# Temperature Grade: commercial
# SSN Data Version: Production
# Package Version: FINAL 2012-06-26
# Package Pin Delay Version: VERS. 2.0 2012-06-26
IO Bank | VCCO | Signal Name | Pin Number | IO Standard | Drive (mA) | Slew Rate | OFFCHIP_TERM | Remaining Margin (%) | Result | Notes
35 | 3.3 | hdmi_clk | M18 | LVCMOS33 | 12 | SLOW | FP_VTT_50 | 14.2 | PASS
35 | 3.3 | hdmi_clk1 | H16 | LVCMOS33 | 12 | SLOW | FP_VTT_50 | 60.1 | PASS
35 | 3.3 | hdmi_data1[0] | E17 | LVCMOS33 | 12 | SLOW | FP_VTT_50 | 59.7 | PASS
35 | 3.3 | hdmi_data1[1] | E19 | LVCMOS33 | 12 | SLOW | FP_VTT_50 | 46.1 | PASS
35 | 3.3 | hdmi_data1[2] | E18 | LVCMOS33 | 12 | SLOW | FP_VTT_50 | 28.1 | PASS
35 | 3.3 | hdmi_data1[3] | K18 | LVCMOS33 | 12 | SLOW | FP_VTT_50 | 10.3 | PASS
35 | 3.3 | hdmi_data1[4] | K17 | LVCMOS33 | 12 | SLOW | FP_VTT_50 | 23.2 | PASS
35 | 3.3 | hdmi_data1[5] | F20 | LVCMOS33 | 12 | SLOW | FP_VTT_50 | 12.6 | PASS
35 | 3.3 | hdmi_data1[6] | F19 | LVCMOS33 | 12 | SLOW | FP_VTT_50 | 15.2 | PASS
35 | 3.3 | hdmi_data1[7] | B20 | LVCMOS33 | 12 | SLOW | FP_VTT_50 | 62.8 | PASS
35 | 3.3 | hdmi_data1[8] | C20 | LVCMOS33 | 12 | SLOW | FP_VTT_50 | 63.4 | PASS
35 | 3.3 | hdmi_data1[9] | H20 | LVCMOS33 | 12 | SLOW | FP_VTT_50 | 0.4 | PASS
35 | 3.3 | hdmi_data1[10] | J20 | LVCMOS33 | 12 | SLOW | FP_VTT_50 | 22.5 | PASS
35 | 3.3 | hdmi_data1[11] | N16 | LVCMOS33 | 12 | SLOW | FP_VTT_50 | 46.5 | PASS
35 | 3.3 | hdmi_data1[12] | N15 | LVCMOS33 | 12 | SLOW | FP_VTT_50 | 29.1 | PASS
35 | 3.3 | hdmi_data1[13] | M20 | LVCMOS33 | 12 | SLOW | FP_VTT_50 | 32.9 | PASS
35 | 3.3 | hdmi_data1[14] | M19 | LVCMOS33 | 12 | SLOW | FP_VTT_50 | 35.3 | PASS
35 | 3.3 | hdmi_data1[15] | G14 | LVCMOS33 | 12 | SLOW | FP_VTT_50 | 78.7 | PASS
35 | 3.3 | hdmi_data[0] | G19 | LVCMOS33 | 12 | SLOW | FP_VTT_50 | 20.5 | PASS
35 | 3.3 | hdmi_data[1] | G20 | LVCMOS33 | 12 | SLOW | FP_VTT_50 | -1.9 | FAIL
35 | 3.3 | hdmi_data[2] | L19 | LVCMOS33 | 12 | SLOW | FP_VTT_50 | 14.1 | PASS
35 | 3.3 | hdmi_data[3] | L20 | LVCMOS33 | 12 | SLOW | FP_VTT_50 | 15.3 | PASS
35 | 3.3 | hdmi_data[4] | L16 | LVCMOS33 | 12 | SLOW | FP_VTT_50 | 23.3 | PASS
35 | 3.3 | hdmi_data[5] | L17 | LVCMOS33 | 12 | SLOW | FP_VTT_50 | 34.3 | PASS
35 | 3.3 | hdmi_data[6] | G17 | LVCMOS33 | 12 | SLOW | FP_VTT_50 | 23.7 | PASS
35 | 3.3 | hdmi_data[7] | D20 | LVCMOS33 | 12 | SLOW | FP_VTT_50 | 37.4 | PASS
35 | 3.3 | hdmi_data[8] | M17 | LVCMOS33 | 12 | SLOW | FP_VTT_50 | 30.1 | PASS
35 | 3.3 | hdmi_data[9] | D19 | LVCMOS33 | 12 | SLOW | FP_VTT_50 | 41.7 | PASS
35 | 3.3 | hdmi_data[10] | K19 | LVCMOS33 | 12 | SLOW | FP_VTT_50 | 12.6 | PASS
35 | 3.3 | hdmi_data[11] | J19 | LVCMOS33 | 12 | SLOW | FP_VTT_50 | 17 | PASS
35 | 3.3 | hdmi_data[12] | J18 | LVCMOS33 | 12 | SLOW | FP_VTT_50 | 8.2 | PASS
35 | 3.3 | hdmi_data[13] | H18 | LVCMOS33 | 12 | SLOW | FP_VTT_50 | -2.3 | FAIL
35 | 3.3 | hdmi_data[14] | F16 | LVCMOS33 | 12 | SLOW | FP_VTT_50 | 43.7 | PASS
35 | 3.3 | hdmi_data[15] | F17 | LVCMOS33 | 12 | SLOW | FP_VTT_50 | 59.9 | PASS
35 | 3.3 | hdmi_de | G18 | LVCMOS33 | 12 | SLOW | FP_VTT_50 | -8.2 | FAIL
35 | 3.3 | hdmi_de1 | H17 | LVCMOS33 | 12 | SLOW | FP_VTT_50 | 17.8 | PASS
35 | 3.3 | hdmi_hsync | J14 | LVCMOS33 | 12 | SLOW | FP_VTT_50 | 26.1 | PASS
35 | 3.3 | hdmi_hsync1 | M15 | LVCMOS33 | 12 | SLOW | FP_VTT_50 | 29.6 | PASS
35 | 3.3 | hdmi_iic1_scl_io | B19 | LVCMOS33 | 12 | SLOW | FP_VTT_50 | 67.9 | PASS
35 | 3.3 | hdmi_iic1_sda_io | D18 | LVCMOS33 | 12 | SLOW | FP_VTT_50 | 51.3 | PASS
35 | 3.3 | hdmi_iic_scl_io | L15 | LVCMOS33 | 12 | SLOW | FP_VTT_50 | 32.3 | PASS
35 | 3.3 | hdmi_iic_sda_io | L14 | LVCMOS33 | 12 | SLOW | FP_VTT_50 | 34.2 | PASS
35 | 3.3 | hdmi_vsync | K14 | LVCMOS33 | 12 | SLOW | FP_VTT_50 | 19.5 | PASS
35 | 3.3 | hdmi_vsync1 | M14 | LVCMOS33 | 12 | SLOW | FP_VTT_50 | 48.9 | PASS
# Reference Links
# Safe to Ignore SSN Failure on MIG Designs - https://support.xilinx.com/s/article/36141
# SSN Mitigation Strategy - http://www.xilinx.com/support/documentation/user_guides/ug471_7Series_SelectIO.pdf
# Off-chip Terminations - http://www.xilinx.com/support/documentation/user_guides/ug471_7Series_SelectIO.pdf

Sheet: ssn_2hdmitx_1v8
Column1 | Column2 | Column3 | Column4 | Column5 | Column6 | Column7 | Column8 | Column9 | Column10 | Column11
# Simultaneously Switching Noise (SSN) Report
# Version: 1.0
# Created on: Wed Aug 20 13:20:31 2025
# Result Name: ssn_2hdmitx_1v8
# Project Name: ALTAIR_PINPLANNING
# Project Family: Zynq-7000
# Part: xc7z020clg400
# Temperature Grade: commercial
# SSN Data Version: Production
# Package Version: FINAL 2012-06-26
# Package Pin Delay Version: VERS. 2.0 2012-06-26
IO Bank | VCCO | Signal Name | Pin Number | IO Standard | Drive (mA) | Slew Rate | OFFCHIP_TERM | Remaining Margin (%) | Result | Notes
35 | 1.8 | hdmi_clk | M18 | LVCMOS18 | 12 | SLOW | FP_VTT_50 | -57.9 | FAIL
35 | 1.8 | hdmi_clk1 | H16 | LVCMOS18 | 12 | SLOW | FP_VTT_50 | 24 | PASS
35 | 1.8 | hdmi_data1[0] | E17 | LVCMOS18 | 12 | SLOW | FP_VTT_50 | 23.2 | PASS
35 | 1.8 | hdmi_data1[1] | E19 | LVCMOS18 | 12 | SLOW | FP_VTT_50 | -1 | FAIL
35 | 1.8 | hdmi_data1[2] | E18 | LVCMOS18 | 12 | SLOW | FP_VTT_50 | -33.1 | FAIL
35 | 1.8 | hdmi_data1[3] | K18 | LVCMOS18 | 12 | SLOW | FP_VTT_50 | -64.8 | FAIL
35 | 1.8 | hdmi_data1[4] | K17 | LVCMOS18 | 12 | SLOW | FP_VTT_50 | -41.9 | FAIL
35 | 1.8 | hdmi_data1[5] | F20 | LVCMOS18 | 12 | SLOW | FP_VTT_50 | -60.7 | FAIL
35 | 1.8 | hdmi_data1[6] | F19 | LVCMOS18 | 12 | SLOW | FP_VTT_50 | -56 | FAIL
35 | 1.8 | hdmi_data1[7] | B20 | LVCMOS18 | 12 | SLOW | FP_VTT_50 | 28.8 | PASS
35 | 1.8 | hdmi_data1[8] | C20 | LVCMOS18 | 12 | SLOW | FP_VTT_50 | 29.9 | PASS
35 | 1.8 | hdmi_data1[9] | H20 | LVCMOS18 | 12 | SLOW | FP_VTT_50 | -82.5 | FAIL
35 | 1.8 | hdmi_data1[10] | J20 | LVCMOS18 | 12 | SLOW | FP_VTT_50 | -43.1 | FAIL
35 | 1.8 | hdmi_data1[11] | N16 | LVCMOS18 | 12 | SLOW | FP_VTT_50 | -0.3 | FAIL
35 | 1.8 | hdmi_data1[12] | N15 | LVCMOS18 | 12 | SLOW | FP_VTT_50 | -31.3 | FAIL
35 | 1.8 | hdmi_data1[13] | M20 | LVCMOS18 | 12 | SLOW | FP_VTT_50 | -24.5 | FAIL
35 | 1.8 | hdmi_data1[14] | M19 | LVCMOS18 | 12 | SLOW | FP_VTT_50 | -20.3 | FAIL
35 | 1.8 | hdmi_data1[15] | G14 | LVCMOS18 | 12 | SLOW | FP_VTT_50 | 57.1 | PASS
35 | 1.8 | hdmi_data[0] | G19 | LVCMOS18 | 12 | SLOW | FP_VTT_50 | -46.7 | FAIL
35 | 1.8 | hdmi_data[1] | G20 | LVCMOS18 | 12 | SLOW | FP_VTT_50 | -86.6 | FAIL
35 | 1.8 | hdmi_data[2] | L19 | LVCMOS18 | 12 | SLOW | FP_VTT_50 | -58.1 | FAIL
35 | 1.8 | hdmi_data[3] | L20 | LVCMOS18 | 12 | SLOW | FP_VTT_50 | -55.9 | FAIL
35 | 1.8 | hdmi_data[4] | L16 | LVCMOS18 | 12 | SLOW | FP_VTT_50 | -41.7 | FAIL
35 | 1.8 | hdmi_data[5] | L17 | LVCMOS18 | 12 | SLOW | FP_VTT_50 | -22.1 | FAIL
35 | 1.8 | hdmi_data[6] | G17 | LVCMOS18 | 12 | SLOW | FP_VTT_50 | -40.9 | FAIL
35 | 1.8 | hdmi_data[7] | D20 | LVCMOS18 | 12 | SLOW | FP_VTT_50 | -16.5 | FAIL
35 | 1.8 | hdmi_data[8] | M17 | LVCMOS18 | 12 | SLOW | FP_VTT_50 | -29.5 | FAIL
35 | 1.8 | hdmi_data[9] | D19 | LVCMOS18 | 12 | SLOW | FP_VTT_50 | -8.8 | FAIL
35 | 1.8 | hdmi_data[10] | K19 | LVCMOS18 | 12 | SLOW | FP_VTT_50 | -60.8 | FAIL
35 | 1.8 | hdmi_data[11] | J19 | LVCMOS18 | 12 | SLOW | FP_VTT_50 | -53 | FAIL
35 | 1.8 | hdmi_data[12] | J18 | LVCMOS18 | 12 | SLOW | FP_VTT_50 | -68.6 | FAIL
35 | 1.8 | hdmi_data[13] | H18 | LVCMOS18 | 12 | SLOW | FP_VTT_50 | -87.4 | FAIL
35 | 1.8 | hdmi_data[14] | F16 | LVCMOS18 | 12 | SLOW | FP_VTT_50 | -5.3 | FAIL
35 | 1.8 | hdmi_data[15] | F17 | LVCMOS18 | 12 | SLOW | FP_VTT_50 | 23.5 | PASS
35 | 1.8 | hdmi_de | G18 | LVCMOS18 | 12 | SLOW | FP_VTT_50 | -97.8 | FAIL
35 | 1.8 | hdmi_de1 | H17 | LVCMOS18 | 12 | SLOW | FP_VTT_50 | -51.4 | FAIL
35 | 1.8 | hdmi_hsync | J14 | LVCMOS18 | 12 | SLOW | FP_VTT_50 | -36.7 | FAIL
35 | 1.8 | hdmi_hsync1 | M15 | LVCMOS18 | 12 | SLOW | FP_VTT_50 | -30.4 | FAIL
35 | 1.8 | hdmi_iic1_scl_io | B19 | LVCMOS18 | 12 | SLOW | FP_VTT_50 | 38 | PASS
35 | 1.8 | hdmi_iic1_sda_io | D18 | LVCMOS18 | 12 | SLOW | FP_VTT_50 | 8.2 | PASS
35 | 1.8 | hdmi_iic_scl_io | L15 | LVCMOS18 | 12 | SLOW | FP_VTT_50 | -25.6 | FAIL
35 | 1.8 | hdmi_iic_sda_io | L14 | LVCMOS18 | 12 | SLOW | FP_VTT_50 | -22.2 | FAIL
35 | 1.8 | hdmi_vsync | K14 | LVCMOS18 | 12 | SLOW | FP_VTT_50 | -48.5 | FAIL
35 | 1.8 | hdmi_vsync1 | M14 | LVCMOS18 | 12 | SLOW | FP_VTT_50 | 3.9 | PASS
# Reference Links
# Safe to Ignore SSN Failure on MIG Designs - https://support.xilinx.com/s/article/36141
# SSN Mitigation Strategy - http://www.xilinx.com/support/documentation/user_guides/ug471_7Series_SelectIO.pdf
# Off-chip Terminations - http://www.xilinx.com/support/documentation/user_guides/ug471_7Series_SelectIO.pdf

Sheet: ssn_2hdmitx_3v3_8ma
Column1 | Column2 | Column3 | Column4 | Column5 | Column6 | Column7 | Column8 | Column9 | Column10 | Column11 | Column12
# Simultaneously Switching Noise (SSN) Report
# Version: 1.0
# Created on: Fri Aug 29 15:52:31 2025
# Result Name: ssn_2hdmitx_3v3_8ma
# Project Name: ALTAIR_PINPLANNING
# Project Family: Zynq-7000
# Part: xc7z020clg400
# Temperature Grade: commercial
# SSN Data Version: Production
# Package Version: FINAL 2012-06-26
# Package Pin Delay Version: VERS. 2.0 2012-06-26
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

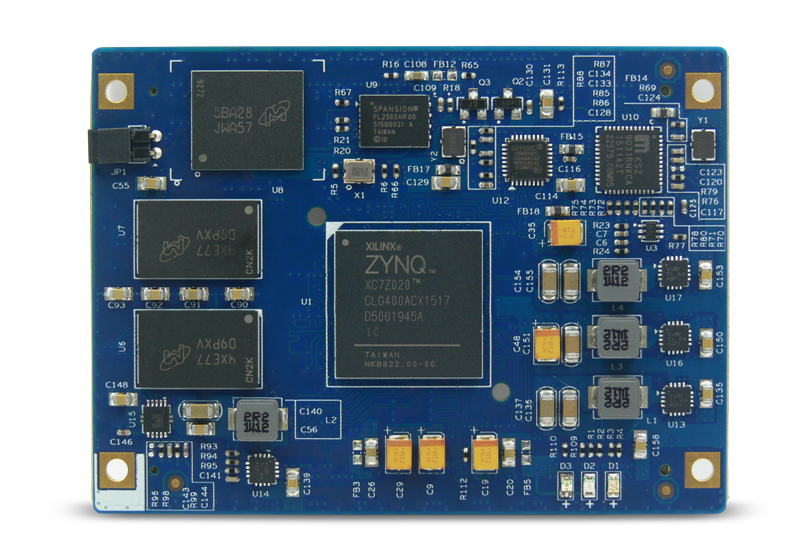
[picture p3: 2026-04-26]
Documentation/MYIR Hardware/Mechanical/images/MYC-C7Z010 20_1.png

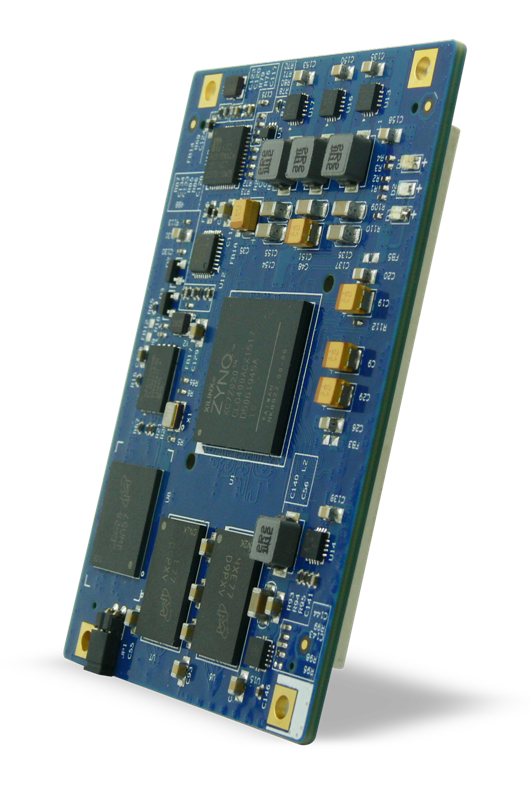
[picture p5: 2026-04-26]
Documentation/MYIR Hardware/Mechanical/images/MYC-C7Z010 20_6.png

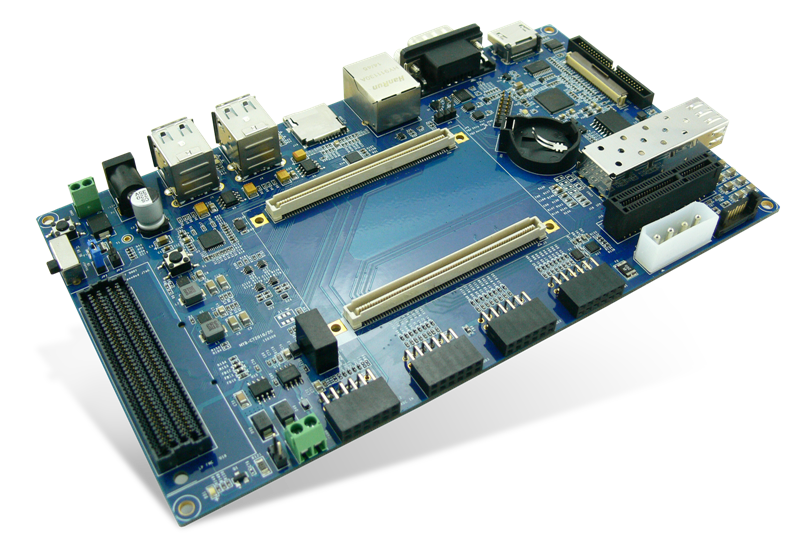
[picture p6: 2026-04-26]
Documentation/MYIR Hardware/Mechanical/images/MYD-C7Z010 20_4.png

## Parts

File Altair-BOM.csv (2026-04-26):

Comment | Designator | Description | Quantity | Note/Misc | JLCPCB Part # | Footprint JLCPCB | Part No
0.1u | C1 | Capacitor SMD 0402 | 1 | 16V, 0402 | C338112 | 0402 | CL05B104KO5NNNC
10u | C2 | Capacitor SMD 1206 | 1 | 25V, 1206 | C9807 | 1206 | CL31A106KAHNNNE
22u | C3 | Capacitor SMD 1206 | 1 | 25V, 1206 | C12891 | 1206 | CL31A226KAHNNNE
10u | C4 | Capacitor SMD 1206 | 1 | 25V, 1206 | C9807 | 1206 | CL31A106KAHNNNE
22u | C5 | Capacitor SMD 1206 | 1 | 25V, 1206 | C12891 | 1206 | CL31A226KAHNNNE
1u | C6 | Capacitor SMD 0402 | 1 | 10V | C14445 | 0402 | CL05A105KP5NNNC
3.3n | C7 | Capacitor SMD 0402 | 1 |  | C527004 | 0402 | CC0402JRX7R8BB332
10u | C8 | Capacitor SMD 1206 | 1 | 25V, 1206 | C9807 | 1206 | CL31A106KAHNNNE
22u | C9 | Capacitor SMD 1206 | 1 | 25V, 1206 | C12891 | 1206 | CL31A226KAHNNNE
3.3n | C10 | Capacitor SMD 0402 | 1 |  | C527004 | 0402 | CC0402JRX7R8BB332
1u | C11 | Capacitor SMD 0402 | 1 | 10V | C14445 | 0402 | CL05A105KP5NNNC
1u | C12 | Capacitor SMD 0402 | 1 | 10V | C14445 | 0402 | CL05A105KP5NNNC
0.1u | C13 | Capacitor SMD 0402 | 1 | 16V, 0402 | C338112 | 0402 | CL05B104KO5NNNC
0.1u | C14 | Capacitor SMD 0402 | 1 | 16V, 0402 | C338112 | 0402 | CL05B104KO5NNNC
0.1u | C15 | Capacitor SMD 0402 | 1 | 16V, 0402 | C338112 | 0402 | CL05B104KO5NNNC
0.1u | C16 | Capacitor SMD 0402 | 1 | 16V, 0402 | C338112 | 0402 | CL05B104KO5NNNC
0.1u | C17 | Capacitor SMD 0402 | 1 | 16V, 0402 | C338112 | 0402 | CL05B104KO5NNNC
0.1u | C18 | Capacitor SMD 0402 | 1 | 16V, 0402 | C338112 | 0402 | CL05B104KO5NNNC
0.1u | C19 | Capacitor SMD 0402 | 1 | 16V, 0402 | C338112 | 0402 | CL05B104KO5NNNC
0.1u | C20 | Capacitor SMD 0402 | 1 | 16V, 0402 | C338112 | 0402 | CL05B104KO5NNNC
0.1u | C21 | Capacitor SMD 0402 | 1 | 16V, 0402 | C338112 | 0402 | CL05B104KO5NNNC
0.1u | C22 | Capacitor SMD 0402 | 1 | 16V, 0402 | C338112 | 0402 | CL05B104KO5NNNC
0.1u | C23 | Capacitor SMD 0402 | 1 | 16V, 0402 | C338112 | 0402 | CL05B104KO5NNNC
4.7u | C24 | Capacitor SMD 0402 | 1 |  | C22367824 | 0402 | HGC0402R5475M250NTEJ
0.1u | C25 | Capacitor SMD 0402 | 1 | 16V, 0402 | C338112 | 0402 | CL05B104KO5NNNC
0.1u | C26 | Capacitor SMD 0402 | 1 | 16V, 0402 | C338112 | 0402 | CL05B104KO5NNNC
0.1u | C27 | Capacitor SMD 0402 | 1 | 16V, 0402 | C338112 | 0402 | CL05B104KO5NNNC
0.1u | C28 | Capacitor SMD 0402 | 1 | 16V, 0402 | C338112 | 0402 | CL05B104KO5NNNC
4.7u | C29 | Capacitor SMD 0402 | 1 |  | C22367824 | 0402 | HGC0402R5475M250NTEJ
0.1u | C30 | Capacitor SMD 0402 | 1 | 16V, 0402 | C338112 | 0402 | CL05B104KO5NNNC
0.1u | C31 | Capacitor SMD 0402 | 1 | 16V, 0402 | C338112 | 0402 | CL05B104KO5NNNC
0.1u | C32 | Capacitor SMD 0402 | 1 | 16V, 0402 | C338112 | 0402 | CL05B104KO5NNNC
0.1u | C33 | Capacitor SMD 0402 | 1 | 16V, 0402 | C338112 | 0402 | CL05B104KO5NNNC
0.1u | C34 | Capacitor SMD 0402 | 1 | 16V, 0402 | C338112 | 0402 | CL05B104KO5NNNC
0.1u | C35 | Capacitor SMD 0402 | 1 | 16V, 0402 | C338112 | 0402 | CL05B104KO5NNNC
0.1u | C36 | Capacitor SMD 0402 | 1 | 16V, 0402 | C338112 | 0402 | CL05B104KO5NNNC
4.7u | C37 | Capacitor SMD 0402 | 1 |  | C22367824 | 0402 | HGC0402R5475M250NTEJ
1u | C38 | Capacitor SMD 0402 | 1 | 10V | C14445 | 0402 | CL05A105KP5NNNC
0.1u | C39 | Capacitor SMD 0402 | 1 | 16V, 0402 | C338112 | 0402 | CL05B104KO5NNNC
0.1u | C40 | Capacitor SMD 0402 | 1 | 16V, 0402 | C338112 | 0402 | CL05B104KO5NNNC
0.1u | C41 | Capacitor SMD 0402 | 1 | 16V, 0402 | C338112 | 0402 | CL05B104KO5NNNC
0.1u | C42 | Capacitor SMD 0402 | 1 | 16V, 0402 | C338112 | 0402 | CL05B104KO5NNNC
1u | C43 | Capacitor SMD 0402 | 1 | 10V | C14445 | 0402 | CL05A105KP5NNNC
1u | C44 | Capacitor SMD 0402 | 1 | 10V | C14445 | 0402 | CL05A105KP5NNNC
0.1u | C45 | Capacitor SMD 0402 | 1 | 16V, 0402 | C338112 | 0402 | CL05B104KO5NNNC
1u | C46 | Capacitor SMD 0402 | 1 | 10V | C14445 | 0402 | CL05A105KP5NNNC
0.1u | C47 | Capacitor SMD 0402 | 1 | 16V, 0402 | C338112 | 0402 | CL05B104KO5NNNC
10u | C48 | Capacitor SMD 0402 | 1 |  | C315248 | 0402 | CL05A106MP5NUNC
0.1u | C49 | Capacitor SMD 0402 | 1 | 16V, 0402 | C338112 | 0402 | CL05B104KO5NNNC
10u | C50 | Capacitor SMD 0402 | 1 |  | C315248 | 0402 | CL05A106MP5NUNC
0.1u | C51 | Capacitor SMD 0402 | 1 | 16V, 0402 | C338112 | 0402 | CL05B104KO5NNNC
10u | C52 | Capacitor SMD 0402 | 1 |  | C315248 | 0402 | CL05A106MP5NUNC
0.1u | C53 | Capacitor SMD 0402 | 1 | 16V, 0402 | C338112 | 0402 | CL05B104KO5NNNC
10u | C54 | Capacitor SMD 0402 | 1 |  | C315248 | 0402 | CL05A106MP5NUNC
0.1u | C55 | Capacitor SMD 0402 | 1 | 16V, 0402 | C338112 | 0402 | CL05B104KO5NNNC
10u | C56 | Capacitor SMD 0402 | 1 |  | C315248 | 0402 | CL05A106MP5NUNC
0.1u | C57 | Capacitor SMD 0402 | 1 | 16V, 0402 | C338112 | 0402 | CL05B104KO5NNNC
10u | C58 | Capacitor SMD 0402 | 1 |  | C315248 | 0402 | CL05A106MP5NUNC
0.1u | C59 | Capacitor SMD 0402 | 1 | 16V, 0402 | C338112 | 0402 | CL05B104KO5NNNC
10u | C60 | Capacitor SMD 0402 | 1 |  | C315248 | 0402 | CL05A106MP5NUNC
0.1u | C61 | Capacitor SMD 0402 | 1 | 16V, 0402 | C338112 | 0402 | CL05B104KO5NNNC
10u | C62 | Capacitor SMD 0402 | 1 |  | C315248 | 0402 | CL05A106MP5NUNC
0.1u | C63 | Capacitor SMD 0402 | 1 | 16V, 0402 | C338112 | 0402 | CL05B104KO5NNNC
10u | C64 | Capacitor SMD 0402 | 1 |  | C315248 | 0402 | CL05A106MP5NUNC
0.1u | C65 | Capacitor SMD 0402 | 1 | 16V, 0402 | C338112 | 0402 | CL05B104KO5NNNC
10u | C66 | Capacitor SMD 0402 | 1 |  | C315248 | 0402 | CL05A106MP5NUNC
0.1u | C67 | Capacitor SMD 0402 | 1 | 16V, 0402 | C338112 | 0402 | CL05B104KO5NNNC
10u | C68 | Capacitor SMD 0402 | 1 |  | C315248 | 0402 | CL05A106MP5NUNC
0.1u | C69 | Capacitor SMD 0402 | 1 | 16V, 0402 | C338112 | 0402 | CL05B104KO5NNNC
10u | C70 | Capacitor SMD 0402 | 1 |  | C315248 | 0402 | CL05A106MP5NUNC
0.1u | C71 | Capacitor SMD 0402 | 1 | 16V, 0402 | C338112 | 0402 | CL05B104KO5NNNC
10u | C72 | Capacitor SMD 0402 | 1 |  | C315248 | 0402 | CL05A106MP5NUNC
1u | C73 | Capacitor SMD 0402 | 1 | 10V | C14445 | 0402 | CL05A105KP5NNNC
1u | C74 | Capacitor SMD 0402 | 1 | 10V | C14445 | 0402 | CL05A105KP5NNNC
1u | C75 | Capacitor SMD 0402 | 1 | 10V | C14445 | 0402 | CL05A105KP5NNNC
1u | C76 | Capacitor SMD 0402 | 1 | 10V | C14445 | 0402 | CL05A105KP5NNNC
0.1u | C77 | Capacitor SMD 0402 | 1 | 16V, 0402 | C338112 | 0402 | CL05B104KO5NNNC
1u | C78 | Capacitor SMD 0402 | 1 | 10V | C14445 | 0402 | CL05A105KP5NNNC
0.1u | C79 | Capacitor SMD 0402 | 1 | 16V, 0402 | C338112 | 0402 | CL05B104KO5NNNC
10u | C80 | Capacitor SMD 0402 | 1 |  | C315248 | 0402 | CL05A106MP5NUNC
0.1u | C81 | Capacitor SMD 0402 | 1 | 16V, 0402 | C338112 | 0402 | CL05B104KO5NNNC
10u | C82 | Capacitor SMD 0402 | 1 |  | C315248 | 0402 | CL05A106MP5NUNC
0.1u | C83 | Capacitor SMD 0402 | 1 | 16V, 0402 | C338112 | 0402 | CL05B104KO5NNNC
10u | C84 | Capacitor SMD 0402 | 1 |  | C315248 | 0402 | CL05A106MP5NUNC
0.1u | C85 | Capacitor SMD 0402 | 1 | 16V, 0402 | C338112 | 0402 | CL05B104KO5NNNC
10u | C86 | Capacitor SMD 0402 | 1 |  | C315248 | 0402 | CL05A106MP5NUNC
0.1u | C87 | Capacitor SMD 0402 | 1 | 16V, 0402 | C338112 | 0402 | CL05B104KO5NNNC
10u | C88 | Capacitor SMD 0402 | 1 |  | C315248 | 0402 | CL05A106MP5NUNC
0.1u | C89 | Capacitor SMD 0402 | 1 | 16V, 0402 | C338112 | 0402 | CL05B104KO5NNNC
10u | C90 | Capacitor SMD 0402 | 1 |  | C315248 | 0402 | CL05A106MP5NUNC
0.1u | C91 | Capacitor SMD 0402 | 1 | 16V, 0402 | C338112 | 0402 | CL05B104KO5NNNC
10u | C92 | Capacitor SMD 0402 | 1 |  | C315248 | 0402 | CL05A106MP5NUNC
0.1u | C93 | Capacitor SMD 0402 | 1 | 16V, 0402 | C338112 | 0402 | CL05B104KO5NNNC
10u | C94 | Capacitor SMD 0402 | 1 |  | C315248 | 0402 | CL05A106MP5NUNC
0.1u | C95 | Capacitor SMD 0402 | 1 | 16V, 0402 | C338112 | 0402 | CL05B104KO5NNNC
10u | C96 | Capacitor SMD 0402 | 1 |  | C315248 | 0402 | CL05A106MP5NUNC
0.1u | C97 | Capacitor SMD 0402 | 1 | 16V, 0402 | C338112 | 0402 | CL05B104KO5NNNC
10u | C98 | Capacitor SMD 0402 | 1 |  | C315248 | 0402 | CL05A106MP5NUNC
0.1u | C99 | Capacitor SMD 0402 | 1 | 16V, 0402 | C338112 | 0402 | CL05B104KO5NNNC
10u | C100 | Capacitor SMD 0402 | 1 |  | C315248 | 0402 | CL05A106MP5NUNC
0.1u | C101 | Capacitor SMD 0402 | 1 | 16V, 0402 | C338112 | 0402 | CL05B104KO5NNNC
10u | C102 | Capacitor SMD 0402 | 1 |  | C315248 | 0402 | CL05A106MP5NUNC
0.1u | C103 | Capacitor SMD 0402 | 1 | 16V, 0402 | C338112 | 0402 | CL05B104KO5NNNC
10u | C104 | Capacitor SMD 0402 | 1 |  | C315248 | 0402 | CL05A106MP5NUNC
4.7u | C105 | Capacitor SMD 0402 | 1 |  | C22367824 | 0402 | HGC0402R5475M250NTEJ
1u | C106 | Capacitor SMD 0402 | 1 | 10V | C14445 | 0402 | CL05A105KP5NNNC
0.1u | C107 | Capacitor SMD 0402 | 1 | 16V, 0402 | C338112 | 0402 | CL05B104KO5NNNC
0.1u | C108 | Capacitor SMD 0402 | 1 | 16V, 0402 | C338112 | 0402 | CL05B104KO5NNNC
0.1u | C109 | Capacitor SMD 0402 | 1 | 16V, 0402 | C338112 | 0402 | CL05B104KO5NNNC
0.1u | C110 | Capacitor SMD 0402 | 1 | 16V, 0402 | C338112 | 0402 | CL05B104KO5NNNC
0.1u | C111 | Capacitor SMD 0402 | 1 | 16V, 0402 | C338112 | 0402 | CL05B104KO5NNNC
0.1u | C112 | Capacitor SMD 0402 | 1 | 16V, 0402 | C338112 | 0402 | CL05B104KO5NNNC
0.1u | C113 | Capacitor SMD 0402 | 1 | 16V, 0402 | C338112 | 0402 | CL05B104KO5NNNC
0.1u | C114 | Capacitor SMD 0402 | 1 | 16V, 0402 | C338112 | 0402 | CL05B104KO5NNNC
22p | C115 | Capacitor SMD 0402 | 1 |  | C541361 | 0402 | CC0402JRNPO8BN220
22p | C116 | Capacitor SMD 0402 | 1 |  | C541361 | 0402 | CC0402JRNPO8BN220
0.1u | C117 | Capacitor SMD 0402 | 1 | 16V, 0402 | C338112 | 0402 | CL05B104KO5NNNC
0.1u | C118 | Capacitor SMD 0402 | 1 | 16V, 0402 | C338112 | 0402 | CL05B104KO5NNNC
0.1u | C119 | Capacitor SMD 0402 | 1 | 16V, 0402 | C338112 | 0402 | CL05B104KO5NNNC
0.1u | C120 | Capacitor SMD 0402 | 1 | 16V, 0402 | C338112 | 0402 | CL05B104KO5NNNC
0.1u | C121 | Capacitor SMD 0402 | 1 | 16V, 0402 | C338112 | 0402 | CL05B104KO5NNNC
0.1u | C122 | Capacitor SMD 0201 | 1 |  | C49062 | 0201 | CL03A104KP3NNNC
0.1u | C123 | Capacitor SMD 0201 | 1 |  | C49062 | 0201 | CL03A104KP3NNNC
0.1u | C124 | Capacitor SMD 0201 | 1 |  | C49062 | 0201 | CL03A104KP3NNNC
0.1u | C125 | Capacitor SMD 0201 | 1 |  | C49062 | 0201 | CL03A104KP3NNNC
0.1u | C126 | Capacitor SMD 0201 | 1 |  | C49062 | 0201 | CL03A104KP3NNNC
0.1u | C127 | Capacitor SMD 0201 | 1 |  | C49062 | 0201 | CL03A104KP3NNNC
0.1u | C128 | Capacitor SMD 0201 | 1 |  | C49062 | 0201 | CL03A104KP3NNNC
0.1u | C129 | Capacitor SMD 0201 | 1 |  | C49062 | 0201 | CL03A104KP3NNNC
0.1u | C130 | Capacitor SMD 0201 | 1 |  | C49062 | 0201 | CL03A104KP3NNNC
0.1u | C131 | Capacitor SMD 0201 | 1 |  | C49062 | 0201 | CL03A104KP3NNNC
0.1u | C132 | Capacitor SMD 0201 | 1 |  | C49062 | 0201 | CL03A104KP3NNNC
0.1u | C133 | Capacitor SMD 0201 | 1 |  | C49062 | 0201 | CL03A104KP3NNNC
0.1u | C134 | Capacitor SMD 0201 | 1 |  | C49062 | 0201 | CL03A104KP3NNNC
0.1u | C135 | Capacitor SMD 0201 | 1 |  | C49062 | 0201 | CL03A104KP3NNNC
0.1u | C136 | Capacitor SMD 0201 | 1 |  | C49062 | 0201 | CL03A104KP3NNNC
0.1u | C137 | Capacitor SMD 0201 | 1 |  | C49062 | 0201 | CL03A104KP3NNNC
0.1u | C138 | Capacitor SMD 0201 | 1 |  | C49062 | 0201 | CL03A104KP3NNNC
0.1u | C139 | Capacitor SMD 0201 | 1 |  | C49062 | 0201 | CL03A104KP3NNNC
0.1u | C140 | Capacitor SMD 0201 | 1 |  | C49062 | 0201 | CL03A104KP3NNNC
0.1u | C141 | Capacitor SMD 0201 | 1 |  | C49062 | 0201 | CL03A104KP3NNNC
0.1u | C142 | Capacitor SMD 0201 | 1 |  | C49062 | 0201 | CL03A104KP3NNNC
0.1u | C143 | Capacitor SMD 0201 | 1 |  | C49062 | 0201 | CL03A104KP3NNNC
0.1u | C144 | Capacitor SMD 0201 | 1 |  | C49062 | 0201 | CL03A104KP3NNNC
0.1u | C145 | Capacitor SMD 0201 | 1 |  | C49062 | 0201 | CL03A104KP3NNNC
0.1u | C146 | Capacitor SMD 0201 | 1 |  | C49062 | 0201 | CL03A104KP3NNNC
0.1u | C147 | Capacitor SMD 0201 | 1 |  | C49062 | 0201 | CL03A104KP3NNNC
0.1u | C148 | Capacitor SMD 0201 | 1 |  | C49062 | 0201 | CL03A104KP3NNNC
0.1u | C149 | Capacitor SMD 0201 | 1 |  | C49062 | 0201 | CL03A104KP3NNNC
0.1u | C150 | Capacitor SMD 0201 | 1 |  | C49062 | 0201 | CL03A104KP3NNNC
0.1u | C151 | Capacitor SMD 0201 | 1 |  | C49062 | 0201 | CL03A104KP3NNNC
0.1u | C152 | Capacitor SMD 0201 | 1 |  | C49062 | 0201 | CL03A104KP3NNNC
0.1u | C153 | Capacitor SMD 0201 | 1 |  | C49062 | 0201 | CL03A104KP3NNNC
0.1u | C154 | Capacitor SMD 0201 | 1 |  | C49062 | 0201 | CL03A104KP3NNNC
0.1u | C155 | Capacitor SMD 0201 | 1 |  | C49062 | 0201 | CL03A104KP3NNNC
0.1u | C156 | Capacitor SMD 0201 | 1 |  | C49062 | 0201 | CL03A104KP3NNNC
0.1u | C157 | Capacitor SMD 0201 | 1 |  | C49062 | 0201 | CL03A104KP3NNNC
0.1u | C158 | Capacitor SMD 0201 | 1 |  | C49062 | 0201 | CL03A104KP3NNNC
0.1u | C159 | Capacitor SMD 0201 | 1 |  | C49062 | 0201 | CL03A104KP3NNNC
0.1u | C160 | Capacitor SMD 0201 | 1 |  | C49062 | 0201 | CL03A104KP3NNNC
0.1u | C161 | Capacitor SMD 0201 | 1 |  | C49062 | 0201 | CL03A104KP3NNNC
SMCJ12A | D1 | Transient Voltage Suppression Diode, 12 V, -65 to 150 degC, 2-Pin DO-214AB (SMCJ), RoHS, Tape and Reel | 1 |  | C224038 | DO-214AB(SMCJ) | SMCJ12A
RED | D2 | LED 0805 RED SMD | 1 | 2.4V, RED | C497952 | 0805 | HL-PSC-2012S9AC
SP3031-01ETG | D3 | TVS Diode (Uni-directional) | 1 |  | C207283 | SOD-882 | SP3031-01ETG
SP3031-01ETG | D4 | TVS Diode (Uni-directional) | 1 |  | C207283 | SOD-882 | SP3031-01ETG
SP3031-01ETG | D5 | TVS Diode (Uni-directional) | 1 |  | C207283 | SOD-882 | SP3031-01ETG
SP3031-01ETG | D6 | TVS Diode (Uni-directional) | 1 |  | C207283 | SOD-882 | SP3031-01ETG
SP3031-01ETG | D7 | TVS Diode (Uni-directional) | 1 |  | C207283 | SOD-882 | SP3031-01ETG
SP3031-01ETG | D8 | TVS Diode (Uni-directional) | 1 |  | C207283 | SOD-882 | SP3031-01ETG
SP3031-01ETG | D9 | TVS Diode (Uni-directional) | 1 |  | C207283 | SOD-882 | SP3031-01ETG
SP3031-01ETG | D10 | TVS Diode (Uni-directional) | 1 |  | C207283 | SOD-882 | SP3031-01ETG
SP3031-01ETG | D11 | TVS Diode (Uni-directional) | 1 |  | C207283 | SOD-882 | SP3031-01ETG
SP3031-01ETG | D12 | TVS Diode (Uni-directional) | 1 |  | C207283 | SOD-882 | SP3031-01ETG
SP3031-01ETG | D13 | TVS Diode (Uni-directional) | 1 |  | C207283 | SOD-882 | SP3031-01ETG
RB751V40,115 | D14 | Schottky Diode | 1 |  | C553814 | SOD-323 | RB751V40,115
SP3031-01ETG | D15 | TVS Diode (Uni-directional) | 1 |  | C207283 | SOD-882 | SP3031-01ETG
SP3031-01ETG | D16 | TVS Diode (Uni-directional) | 1 |  | C207283 | SOD-882 | SP3031-01ETG
SP3031-01ETG | D17 | TVS Diode (Uni-directional) | 1 |  | C207283 | SOD-882 | SP3031-01ETG
SP3031-01ETG | D18 | TVS Diode (Uni-directional) | 1 |  | C207283 | SOD-882 | SP3031-01ETG
SP3031-01ETG | D19 | TVS Diode (Uni-directional) | 1 |  | C207283 | SOD-882 | SP3031-01ETG
SP3031-01ETG | D20 | TVS Diode (Uni-directional) | 1 |  | C207283 | SOD-882 | SP3031-01ETG
SP3031-01ETG | D21 | TVS Diode (Uni-directional) | 1 |  | C207283 | SOD-882 | SP3031-01ETG
SP3031-01ETG | D22 | TVS Diode (Uni-directional) | 1 |  | C207283 | SOD-882 | SP3031-01ETG
SP3031-01ETG | D23 | TVS Diode (Uni-directional) | 1 |  | C207283 | SOD-882 | SP3031-01ETG
GREEN | D24 | LED 0805 GREEN SMD | 1 | 2.4V, GREEN | C2986046 | 0805 | 17-21SYGC/S530-E2/TR8
GREEN | D25 | LED 0805 GREEN SMD | 1 | 2.4V, GREEN | C2986046 | 0805 | 17-21SYGC/S530-E2/TR8
RCLAMP0524PATCT | D26 | TVS Diode (Uni-directional) | 1 |  | C40960 | DFN-10(1x2.5) | RCLAMP0524PATCT
BAS16XV2T1G | D27 | Diode (Switching) | 1 |  | C152479 | SOD-523 | BAS16XV2T1G
RCLAMP0524PATCT | D28 | TVS Diode (Uni-directional) | 1 |  | C40960 | DFN-10(1x2.5) | RCLAMP0524PATCT
RCLAMP0524PATCT | D29 | TVS Diode (Uni-directional) | 1 |  | C40960 | DFN-10(1x2.5) | RCLAMP0524PATCT
SP3031-01ETG | D30 | TVS Diode (Uni-directional) | 1 |  | C207283 | SOD-882 | SP3031-01ETG
RCLAMP0524PATCT | D31 | TVS Diode (Uni-directional) | 1 |  | C40960 | DFN-10(1x2.5) | RCLAMP0524PATCT
BAS16XV2T1G | D32 | Diode (Switching) | 1 |  | C152479 | SOD-523 | BAS16XV2T1G
RCLAMP0524PATCT | D33 | TVS Diode (Uni-directional) | 1 |  | C40960 | DFN-10(1x2.5) | RCLAMP0524PATCT
RCLAMP0524PATCT | D34 | TVS Diode (Uni-directional) | 1 |  | C40960 | DFN-10(1x2.5) | RCLAMP0524PATCT
SP3031-01ETG | D35 | TVS Diode (Uni-directional) | 1 |  | C207283 | SOD-882 | SP3031-01ETG
SP3031-01ETG | D36 | TVS Diode (Uni-directional) | 1 |  | C207283 | SOD-882 | SP3031-01ETG
SP3031-01ETG | D37 | TVS Diode (Uni-directional) | 1 |  | C207283 | SOD-882 | SP3031-01ETG
SP3031-01ETG | D38 | TVS Diode (Uni-directional) | 1 |  | C207283 | SOD-882 | SP3031-01ETG
SP3031-01ETG | D39 | TVS Diode (Uni-directional) | 1 |  | C207283 | SOD-882 | SP3031-01ETG
SP3031-01ETG | D40 | TVS Diode (Uni-directional) | 1 |  | C207283 | SOD-882 | SP3031-01ETG
SP3031-01ETG | D41 | TVS Diode (Uni-directional) | 1 |  | C207283 | SOD-882 | SP3031-01ETG
RED | D42 | LED 0805 RED SMD | 1 | 2.4V, RED | C497952 | 0805 | HL-PSC-2012S9AC
RED | D43 | LED 0805 RED SMD | 1 | 2.4V, RED | C497952 | 0805 | HL-PSC-2012S9AC
RED | D44 | LED 0805 RED SMD | 1 | 2.4V, RED | C497952 | 0805 | HL-PSC-2012S9AC
RED | D45 | LED 0805 RED SMD | 1 | 2.4V, RED | C497952 | 0805 | HL-PSC-2012S9AC
SP3022-01ETG | D46 | TVS Diode (Bi-directional) | 1 |  | C126840 | SOD-882 | SP3022-01ETG
SP3022-01ETG | D47 | TVS Diode (Bi-directional) | 1 |  | C126840 | SOD-882 | SP3022-01ETG
SP3022-01ETG | D48 | TVS Diode (Bi-directional) | 1 |  | C126840 | SOD-882 | SP3022-01ETG
SP3022-01ETG | D49 | TVS Diode (Bi-directional) | 1 |  | C126840 | SOD-882 | SP3022-01ETG
SP3022-01ETG | D50 | TVS Diode (Bi-directional) | 1 |  | C126840 | SOD-882 | SP3022-01ETG
SP3022-01ETG | D51 | TVS Diode (Bi-directional) | 1 |  | C126840 | SOD-882 | SP3022-01ETG
SP3022-01ETG | D52 | TVS Diode (Bi-directional) | 1 |  | C126840 | SOD-882 | SP3022-01ETG
SP3022-01ETG | D53 | TVS Diode (Bi-directional) | 1 |  | C126840 | SOD-882 | SP3022-01ETG
SP3022-01ETG | D54 | TVS Diode (Bi-directional) | 1 |  | C126840 | SOD-882 | SP3022-01ETG
SP3022-01ETG | D55 | TVS Diode (Bi-directional) | 1 |  | C126840 | SOD-882 | SP3022-01ETG
SP3022-01ETG | D56 | TVS Diode (Bi-directional) | 1 |  | C126840 | SOD-882 | SP3022-01ETG
SP3022-01ETG | D57 | TVS Diode (Bi-directional) | 1 |  | C126840 | SOD-882 | SP3022-01ETG
SP3022-01ETG | D58 | TVS Diode (Bi-directional) | 1 |  | C126840 | SOD-882 | SP3022-01ETG
SP3022-01ETG | D59 | TVS Diode (Bi-directional) | 1 |  | C126840 | SOD-882 | SP3022-01ETG
SP3022-01ETG | D60 | TVS Diode (Bi-directional) | 1 |  | C126840 | SOD-882 | SP3022-01ETG
SP3022-01ETG | D61 | TVS Diode (Bi-directional) | 1 |  | C126840 | SOD-882 | SP3022-01ETG
SP3022-01ETG | D62 | TVS Diode (Bi-directional) | 1 |  | C126840 | SOD-882 | SP3022-01ETG
SP3022-01ETG | D63 | TVS Diode (Bi-directional) | 1 |  | C126840 | SOD-882 | SP3022-01ETG
SP3022-01ETG | D64 | TVS Diode (Bi-directional) | 1 |  | C126840 | SOD-882 | SP3022-01ETG
SP3022-01ETG | D65 | TVS Diode (Bi-directional) | 1 |  | C126840 | SOD-882 | SP3022-01ETG
SP3022-01ETG | D66 | TVS Diode (Bi-directional) | 1 |  | C126840 | SOD-882 | SP3022-01ETG
SP3022-01ETG | D67 | TVS Diode (Bi-directional) | 1 |  | C126840 | SOD-882 | SP3022-01ETG
SP3022-01ETG | D68 | TVS Diode (Bi-directional) | 1 |  | C126840 | SOD-882 | SP3022-01ETG
SP3022-01ETG | D69 | TVS Diode (Bi-directional) | 1 |  | C126840 | SOD-882 | SP3022-01ETG
SP3022-01ETG | D70 | TVS Diode (Bi-directional) | 1 |  | C126840 | SOD-882 | SP3022-01ETG
SP3022-01ETG | D71 | TVS Diode (Bi-directional) | 1 |  | C126840 | SOD-882 | SP3022-01ETG
SP3022-01ETG | D72 | TVS Diode (Bi-directional) | 1 |  | C126840 | SOD-882 | SP3022-01ETG
SP3022-01ETG | D73 | TVS Diode (Bi-directional) | 1 |  | C126840 | SOD-882 | SP3022-01ETG
SP3031-01ETG | D74 | TVS Diode (Uni-directional) | 1 |  | C207283 | SOD-882 | SP3031-01ETG
SP3031-01ETG | D75 | TVS Diode (Uni-directional) | 1 |  | C207283 | SOD-882 | SP3031-01ETG
SP3022-01ETG | D76 | TVS Diode (Bi-directional) | 1 |  | C126840 | SOD-882 | SP3022-01ETG
SP3022-01ETG | D77 | TVS Diode (Bi-directional) | 1 |  | C126840 | SOD-882 | SP3022-01ETG
SP3022-01ETG | D78 | TVS Diode (Bi-directional) | 1 |  | C126840 | SOD-882 | SP3022-01ETG
SP3022-01ETG | D79 | TVS Diode (Bi-directional) | 1 |  | C126840 | SOD-882 | SP3022-01ETG
SP3022-01ETG | D80 | TVS Diode (Bi-directional) | 1 |  | C126840 | SOD-882 | SP3022-01ETG
SP3022-01ETG | D81 | TVS Diode (Bi-directional) | 1 |  | C126840 | SOD-882 | SP3022-01ETG
SP3022-01ETG | D82 | TVS Diode (Bi-directional) | 1 |  | C126840 | SOD-882 | SP3022-01ETG
SP3022-01ETG | D83 | TVS Diode (Bi-directional) | 1 |  | C126840 | SOD-882 | SP3022-01ETG
0466003.NR | F1 | FUSE MNT 3A 32VAC/VDC 1206 | 1 | 32V, 3A | C14165 | 1206 | 0466003.NR
220 | FB1 | Ferrite Bead | 1 |  | C76815 | 0603 | MPZ1608S221ATA00
220 | FB2 | Ferrite Bead | 1 |  | C76815 | 0603 | MPZ1608S221ATA00
220 | FB3 | Ferrite Bead | 1 |  | C76815 | 0603 | MPZ1608S221ATA00
120m | FB4 | Ferrite Bead SMD 0201 | 1 |  | C695597 | 0201 | MPZ0603S121HT000
120m | FB5 | Ferrite Bead SMD 0201 | 1 |  | C695597 | 0201 | MPZ0603S121HT000
220 | FB6 | Ferrite Bead | 1 |  | C76815 | 0603 | MPZ1608S221ATA00
220 | FB7 | Ferrite Bead | 1 |  | C76815 | 0603 | MPZ1608S221ATA00
220 | FB8 | Ferrite Bead | 1 |  | C76815 | 0603 | MPZ1608S221ATA00
220 | FB9 | Ferrite Bead | 1 |  | C76815 | 0603 | MPZ1608S221ATA00
220 | FB10 | Ferrite Bead | 1 |  | C76815 | 0603 | MPZ1608S221ATA00
220 | FB11 | Ferrite Bead | 1 |  | C76815 | 0603 | MPZ1608S221ATA00
220 | FB12 | Ferrite Bead | 1 |  | C76815 | 0603 | MPZ1608S221ATA00
220 | FB13 | Ferrite Bead | 1 |  | C76815 | 0603 | MPZ1608S221ATA00
220 | FB14 | Ferrite Bead | 1 |  | C76815 | 0603 | MPZ1608S221ATA00
220 | FB15 | Ferrite Bead | 1 |  | C76815 | 0603 | MPZ1608S221ATA00
DC-005 | J1 | DC Jack | 1 |  | C720557 | Plugin | DC-005
61083-141402LF | J2 | Connector | 1 |  | C5338666 | SMD,P=0.8mm | 61083-141402LF
61083-141402LF | J3 | Connector | 1 |  | C5338666 | SMD,P=0.8mm | 61083-141402LF
TF-01A | J4 | SD CARD Connector Slot | 1 |  | C91145 | SMD | TF-01A
4xHeader | J5 | Standard 4 pin 2.54mm pitch connector | 1 |  | C706876 | Plugin,P=2.54mm | X6511WV-04H-C60D30
2x7Header | J6 | Standard 2x7 pin 2.54mm pitch connector | 1 |  | C706897 | Plugin,P=2.54mm | X6521WV-2x07H-C60D30
4xHeader | J7 | Standard 4 pin 2.54mm pitch connector | 1 |  | C706876 | Plugin,P=2.54mm | X6511WV-04H-C60D30
TYPE-C-31-M-12 | J8 | USB2.0, Type C, Top mount, CH 1.68mm, Dual Row SMT | 1 |  | C165948 | SMD | TYPE-C-31-M-12
1-1734248-5 | J9 | FPC CONNECTOR VERT 15 PINS 1.00MM SMD | 1 |  | C2922285 | SMD,P=1mm | 1-1734248-5
1-1734248-5 | J10 | FPC CONNECTOR VERT 15 PINS 1.00MM SMD | 1 |  | C2922285 | SMD,P=1mm | 1-1734248-5
10029449-111RLF | J11 | HDMI Connector | 1 |  | C427307 | SMD | 10029449-111RLF
10029449-111RLF | J12 | HDMI Connector | 1 |  | C427307 | SMD | 10029449-111RLF
TYPE-C-31-M-12 | J13 | USB2.0, Type C, Top mount, CH 1.68mm, Dual Row SMT | 1 |  | C165948 | SMD | TYPE-C-31-M-12
GT-USB-2042-CBG1 | J14 | 2x USB Type-A Female Connector | 1 |  | C2911522 | Plugin | GT-USB-2042-CBG1
PMOD_HEADER | J15 | NON-Standard 2x6 pin 2.54mm pitch connector. Right Angle | 1 |  | C22373932 | Push-Pull,P=2.54mm | HC-PM254-8.5H-2x6PW
PMOD_HEADER | J16 | NON-Standard 2x6 pin 2.54mm pitch connector. Right Angle | 1 |  | C22373932 | Push-Pull,P=2.54mm | HC-PM254-8.5H-2x6PW
PMOD_HEADER | J17 | NON-Standard 2x6 pin 2.54mm pitch connector. Right Angle | 1 |  | C22373932 | Push-Pull,P=2.54mm | HC-PM254-8.5H-2x6PW
PMOD_HEADER | J18 | NON-Standard 2x6 pin 2.54mm pitch connector. Right Angle | 1
PMOD_HEADER | J19 | NON-Standard 2x6 pin 2.54mm pitch connector. Right Angle | 1 |  | C22373932 | Push-Pull,P=2.54mm | HC-PM254-8.5H-2x6PW
HY911130A | J20 | Ethernet Connector | 1 |  | C55679 | Plugin | HY911130A
4xHeader | J21 | Standard 4 pin 2.54mm pitch connector | 1 |  | C706876 | Plugin,P=2.54mm | X6511WV-04H-C60D30
2.2u | L1 | Inductor SMD 2.2 uH | 1 | XGL4020-222MEC | C6012410 | 1616 | XGL4020-222MEC
2.2u | L2 | Inductor SMD 2.2 uH | 1 | XGL4020-222MEC | C6012410 | 1616 | XGL4020-222MEC
4.7u | L3 | Inductor | 1 | LQM21FN4R7M80L | C464406 | 0805 | LQM21FN4R7M80L
100k | R1 | Resistor SMD 0402 | 1 |  | C106234 | 0402 | RC0402JR-07100KL
10k | R2 | Resistor SMD 0402 | 1 |  | C60489 | 0402 | RC0402JR-0710KL
100k | R3 | Resistor SMD 0402 | 1 |  | C106234 | 0402 | RC0402JR-07100KL
680k | R4 | Resistor SMD 0402 | 1 | 1% | C163456 | 0402 | RC0402FR-07680KL
130k | R5 | Resistor SMD 0402 | 1 | 1% | C93946 | 0402 | RC0402FR-07130KL
0R | R6 | Resistor SMD 0402 | 1 |  | C60485 | 0402 | RC0402JR-070RL
100k | R7 | Resistor SMD 0402 | 1 |  | C106234 | 0402 | RC0402JR-07100KL
750k | R8 | Resistor SMD 0402 | 1 | 1% | C137937 | 0402 | RC0402FR-07750KL
240k | R9 | Resistor SMD 0402 | 1 | 1% | C138029 | 0402 | RC0402FR-07240KL
2.2k | R10 | Resistor SMD 0402 | 1 |  | C163447 | 0402 | RC0402JR-072K2L
10k | R11 | Resistor SMD 0402 | 1 |  | C60489 | 0402 | RC0402JR-0710KL
10k | R12 | Resistor SMD 0402 | 1 |  | C60489 | 0402 | RC0402JR-0710KL
10k | R13 | Resistor SMD 0402 | 1 |  | C60489 | 0402 | RC0402JR-0710KL
10k | R14 | Resistor SMD 0402 | 1 |  | C60489 | 0402 | RC0402JR-0710KL
10k | R15 | Resistor SMD 0402 | 1 |  | C60489 | 0402 | RC0402JR-0710KL
10k | R16 | Resistor SMD 0402 | 1 |  | C60489 | 0402 | RC0402JR-0710KL
20k | R17 | Resistor SMD 0402 | 1 |  | C93942 | 0402 | RC0402FR-0720KL
0R | R18 | Resistor SMD 0402 | 1 |  | C60485 | 0402 | RC0402JR-070RL
10k | R19 | Resistor SMD 0402 | 1 |  | C60489 | 0402 | RC0402JR-0710KL
1k | R20 | Resistor SMD 0402 | 1 |  | C105637 | 0402 | RC0402JR-071KL
20k | R21 | Resistor SMD 0402 | 1 |  | C93942 | 0402 | RC0402FR-0720KL
20k | R22 | Resistor SMD 0402 | 1 |  | C93942 | 0402 | RC0402FR-0720KL
1k | R23 | Resistor SMD 0402 | 1 |  | C105637 | 0402 | RC0402JR-071KL
0R | R24 | Resistor SMD 0402 | 1 |  | C60485 | 0402 | RC0402JR-070RL
0R, DNP | R25 | Resistor SMD 0402 | 1 | DNP | C60485 | 0402 | RC0402JR-070RL
10k | R26 | Resistor SMD 0402 | 1 |  | C60489 | 0402 | RC0402JR-0710KL
10k | R27 | Resistor SMD 0402 | 1 |  | C60489 | 0402 | RC0402JR-0710KL
10k | R28 | Resistor SMD 0402 | 1 |  | C60489 | 0402 | RC0402JR-0710KL
10k | R29 | Resistor SMD 0402 | 1 |  | C60489 | 0402 | RC0402JR-0710KL
10k | R30 | Resistor SMD 0402 | 1 |  | C60489 | 0402 | RC0402JR-0710KL
10k | R31 | Resistor SMD 0402 | 1 |  | C60489 | 0402 | RC0402JR-0710KL
10k | R32 | Resistor SMD 0402 | 1 |  | C60489 | 0402 | RC0402JR-0710KL
0R | R33 | Resistor SMD 0402 | 1 |  | C60485 | 0402 | RC0402JR-070RL
0R | R34 | Resistor SMD 0402 | 1 |  | C60485 | 0402 | RC0402JR-070RL
2.2k | R35 | Resistor SMD 0402 | 1 |  | C163447 | 0402 | RC0402JR-072K2L
0R | R36 | Resistor SMD 0402 | 1 |  | C60485 | 0402 | RC0402JR-070RL
0R | R37 | Resistor SMD 0402 | 1 |  | C60485 | 0402 | RC0402JR-070RL
0R | R38 | Resistor SMD 0402 | 1 |  | C60485 | 0402 | RC0402JR-070RL
0R | R39 | Resistor SMD 0402 | 1 |  | C60485 | 0402 | RC0402JR-070RL
0R | R40 | Resistor SMD 0402 | 1 |  | C60485 | 0402 | RC0402JR-070RL
0R | R41 | Resistor SMD 0402 | 1 |  | C60485 | 0402 | RC0402JR-070RL
0R, DNP | R42 | Resistor SMD 0402 | 1 | DNP | C60485 | 0402 | RC0402JR-070RL
0R | R43 | Resistor SMD 0402 | 1 |  | C60485 | 0402 | RC0402JR-070RL
5.1k | R44 | Resistor SMD 0402 | 1 |  | C105873 | 0402 | RC0402JR-075K1L
5.1k | R45 | Resistor SMD 0402 | 1 |  | C105873 | 0402 | RC0402JR-075K1L
20k | R46 | Resistor SMD 0402 | 1 |  | C93942 | 0402 | RC0402FR-0720KL
0R | R47 | Resistor SMD 0402 | 1 |  | C60485 | 0402 | RC0402JR-070RL
1k | R48 | Resistor SMD 0402 | 1 |  | C105637 | 0402 | RC0402JR-071KL
0R | R49 | Resistor SMD 0402 | 1 |  | C60485 | 0402 | RC0402JR-070RL
10k | R50 | Resistor SMD 0402 | 1 |  | C60489 | 0402 | RC0402JR-0710KL
10k | R51 | Resistor SMD 0402 | 1 |  | C60489 | 0402 | RC0402JR-0710KL
10k | R52 | Resistor SMD 0402 | 1 |  | C60489 | 0402 | RC0402JR-0710KL
12k | R53 | Resistor SMD 0402 | 1 | 1% | C114760 | 0402 | RC0402FR-0712KL
150R | R54 | Resistor SMD 0402 | 1 | 1% | C138054 | 0402 | RC0402FR-07150RL
2.2k | R55 | Resistor SMD 0402 | 1 |  | C163447 | 0402 | RC0402JR-072K2L
4.7k | R56 | Resistor SMD 0402 | 1 |  | C105870 | 0402 | RC0402JR-074K7L
150R | R57 | Resistor SMD 0402 | 1 | 1% | C138054 | 0402 | RC0402FR-07150RL
10k | R58 | Resistor SMD 0402 | 1 |  | C60489 | 0402 | RC0402JR-0710KL
100R | R59 | Resistor SMD 0402 | 1 | 1% | C106232 | 0402 | RC0402FR-07100RL
150R | R60 | Resistor SMD 0402 | 1 | 1% | C138054 | 0402 | RC0402FR-07150RL
100R | R61 | Resistor SMD 0402 | 1 | 1% | C106232 | 0402 | RC0402FR-07100RL
100R | R62 | Resistor SMD 0402 | 1 | 1% | C106232 | 0402 | RC0402FR-07100RL
150R | R63 | Resistor SMD 0402 | 1 | 1% | C138054 | 0402 | RC0402FR-07150RL
100R | R64 | Resistor SMD 0402 | 1 | 1% | C106232 | 0402 | RC0402FR-07100RL
0R | R65 | Resistor SMD 0402 | 1 |  | C60485 | 0402 | RC0402JR-070RL
100R | R66 | Resistor SMD 0402 | 1 | 1% | C106232 | 0402 | RC0402FR-07100RL
0R, DNP | R67 | Resistor SMD 0402 | 1 | DNP | C60485 | 0402 | RC0402JR-070RL
0R | R68 | Resistor SMD 0402 | 1 |  | C60485 | 0402 | RC0402JR-070RL
150R | R69 | Resistor SMD 0402 | 1 | 1% | C138054 | 0402 | RC0402FR-07150RL
0R, DNP | R70 | Resistor SMD 0402 | 1 | DNP | C60485 | 0402 | RC0402JR-070RL
10k | R71 | Resistor SMD 0402 | 1 |  | C60489 | 0402 | RC0402JR-0710KL
10k | R72 | Resistor SMD 0402 | 1 |  | C60489 | 0402 | RC0402JR-0710KL
10k | R73 | Resistor SMD 0402 | 1 |  | C60489 | 0402 | RC0402JR-0710KL
10k | R74 | Resistor SMD 0402 | 1 |  | C60489 | 0402 | RC0402JR-0710KL
10k | R75 | Resistor SMD 0402 | 1 |  | C60489 | 0402 | RC0402JR-0710KL
10k | R76 | Resistor SMD 0402 | 1 |  | C60489 | 0402 | RC0402JR-0710KL
100R | R77 | Resistor SMD 0402 | 1 | 1% | C106232 | 0402 | RC0402FR-07100RL
100R | R78 | Resistor SMD 0402 | 1 | 1% | C106232 | 0402 | RC0402FR-07100RL
150R | R79 | Resistor SMD 0402 | 1 | 1% | C138054 | 0402 | RC0402FR-07150RL
100R | R80 | Resistor SMD 0402 | 1 | 1% | C106232 | 0402 | RC0402FR-07100RL
100R | R81 | Resistor SMD 0402 | 1 | 1% | C106232 | 0402 | RC0402FR-07100RL
150R | R82 | Resistor SMD 0402 | 1 | 1% | C138054 | 0402 | RC0402FR-07150RL
100R | R83 | Resistor SMD 0402 | 1 | 1% | C106232 | 0402 | RC0402FR-07100RL
100R | R84 | Resistor SMD 0402 | 1 | 1% | C106232 | 0402 | RC0402FR-07100RL
150R | R85 | Resistor SMD 0402 | 1 | 1% | C138054 | 0402 | RC0402FR-07150RL
100R | R86 | Resistor SMD 0402 | 1 | 1% | C106232 | 0402 | RC0402FR-07100RL
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

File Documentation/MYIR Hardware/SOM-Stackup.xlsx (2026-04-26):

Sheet: 阻抗层叠控制信息
层标识 | PCB厂家设计调整(oz/mm) |  |  |  | 残铜率 | 介质DK
 | 层叠图示 |  |  | 厚度
TOP.art | base copper 0.01200mm + Plating
 | PP(3313 RC57) |  |  | 0.09226 |  | 3.95
GND2.art |  |  |  | 1oz | 74.607
 | CORE (S1000-2M) |  |  | 0.10000 |  | 3.85
INT3.art |  |  |  | 1oz | 44.483
 | PP(2116 RC55+2116 RC55) |  |  | 0.22534 |  | 3.95
GND4.art |  |  |  | 1oz | 74.608
 | CORE (S1000-2M) |  |  | 0.10000 |  | 3.85
INT5.art |  |  |  | 1oz | 46.833
 | PP(2116 RC55+2116 RC55) |  |  | 0.22605 |  | 3.95
GND6.art |  |  |  | 1oz | 74.603
 | CORE (S1000-2M) |  |  | 0.10000 |  | 3.85
VCC7.art |  |  |  | 1oz | 72.785
 | PP(2116 RC55+2116 RC55) |  |  | 0.22820 |  | 3.95
INT8.art |  |  |  | 1oz | 55.679
 | CORE (S1000-2M) |  |  | 0.10000 |  | 3.85
GND9.art |  |  |  | 1oz | 74.629
 | PP(3313 RC57) |  |  | 0.09227 |  | 3.95
BOTTOM.art | base copper 0.01200mm + Plating
 | 层压理论厚度: 1.52mm
 | 板材：S1000-2M，完成板厚：1.60mm(+/-0.16) (包含电镀+油墨厚度)
单线线宽、阻抗、参考层控制信息
线宽 的计量单位为mm，阻抗的计量单位为ohm
层标识 | 单线1
 | 客户设计线宽 | 客户设计阻抗 | JX调整线宽 | JX阻抗计算值 | 参考层
L1 | 0.12700 | 50+/-5 | 0.14478 | 50.2 | L2
L1 | 0.20320 | 40+/-5 | 0.22098 | 40.1 | L2
L3 | 0.19050 | 40+/-5 | 0.17272 | 40 | L2&L4
L3 | 0.12700 | 50+/-5 | 0.10922 | 50 | L2&L4
L5 | 0.19050 | 40+/-5 | 0.17272 | 39.9 | L4&L6
L5 | 0.12700 | 50+/-5 | 0.10922 | 49.9 | L4&L6
L8 | 0.12700 | 50+/-5 | 0.10922 | 50 | L7&L9
L8 | 0.19050 | 40+/-5 | 0.17272 | 40 | L7&L9
L10 | 0.12700 | 50+/-5 | 0.14478 | 50.2 | L9
差分线宽/线距、阻抗、参考层控制信息
线宽、线距 的计量单位为mm，阻抗的计量单位为ohm
层标识 | 差分1
 | 客户设计线宽/线距 | 客户设计阻抗 | JX调整线宽/线距 | JX阻抗计算值 | 参考层
L1 | 0.17780/0.17780 | 80+/-8 | 0.17780/0.17780 | 81.5 | L2
L1 | 0.12700/0.20320 | 100+/-10 | 0.11938/0.21082 | 100.4 | L2
L3 | 0.13970/0.17780 | 80+/-8 | 0.14732/0.17018 | 80.1 | L2&L4
L3 | 0.10414/0.20320 | 100+/-10 | 0.09398/0.21336 | 100.3 | L2&L4
L5 | 0.13970/0.17780 | 80+/-8 | 0.14732/0.17018 | 80.1 | L4&L6
L5 | 0.10414/0.20320 | 100+/-10 | 0.09398/0.21336 | 100.2 | L4&L6

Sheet: Stack up&Impedance
Layer mark | PCB supplier builds stackup with adjusting value (oz/mm) |  |  |  | Residual copper ratio | Dielectric (DK)
 | stackup structure detail |  |  | Thickness
TOP.art | base copper 0.01200mm + Plating
 | PP(3313 RC57) |  |  | 0.09226 |  | 3.95
GND2.art |  |  |  | 1oz | 74.607
 | CORE (S1000-2M) |  |  | 0.10000 |  | 3.85
INT3.art |  |  |  | 1oz | 44.483
 | PP(2116 RC55+2116 RC55) |  |  | 0.22534 |  | 3.95
GND4.art |  |  |  | 1oz | 74.608
 | CORE (S1000-2M) |  |  | 0.10000 |  | 3.85
INT5.art |  |  |  | 1oz | 46.833
 | PP(2116 RC55+2116 RC55) |  |  | 0.22605 |  | 3.95
GND6.art |  |  |  | 1oz | 74.603
 | CORE (S1000-2M) |  |  | 0.10000 |  | 3.85
VCC7.art |  |  |  | 1oz | 72.785
 | PP(2116 RC55+2116 RC55) |  |  | 0.22820 |  | 3.95
INT8.art |  |  |  | 1oz | 55.679
 | CORE (S1000-2M) |  |  | 0.10000 |  | 3.85
GND9.art |  |  |  | 1oz | 74.629
 | PP(3313 RC57) |  |  | 0.09227 |  | 3.95
BOTTOM.art | base copper 0.01200mm + Plating
 | pure stackup construction thickness: 1.52mm
 | Base material:S1000-2M,Finished board thickness:1.60mm(+/-0.16) (including plated thickness+SM ink thickness)
Single-ended impedance trace width 、impedance value、refer layers
The unit of trace width is mm. The unit of impedance is ohm.
Layer mark | single-ended impedance
 | Customer designed TW | Customer required impedance value | JX adjusted trace width | JX calculated value | Refer layer
L1 | 0.12700 | 50+/-5 | 0.14478 | 50.2 | L2
L1 | 0.20320 | 40+/-5 | 0.22098 | 40.1 | L2
L3 | 0.19050 | 40+/-5 | 0.17272 | 40 | L2&L4
L3 | 0.12700 | 50+/-5 | 0.10922 | 50 | L2&L4
L5 | 0.19050 | 40+/-5 | 0.17272 | 39.9 | L4&L6
L5 | 0.12700 | 50+/-5 | 0.10922 | 49.9 | L4&L6
L8 | 0.12700 | 50+/-5 | 0.10922 | 50 | L7&L9
L8 | 0.19050 | 40+/-5 | 0.17272 | 40 | L7&L9
L10 | 0.12700 | 50+/-5 | 0.14478 | 50.2 | L9
Differential impedance trace width/spacing、impedance value、refer layers
The unit of trace width/spacing is mm. The unit of impedance is ohm.
Layer mark | Differential impedance
 | Customer designed TW/TS | Customer required impedance value | JX adjusted trace width/spacing | JX calculated value | Refer layer
L1 | 0.17780/0.17780 | 80+/-8 | 0.17780/0.17780 | 81.5 | L2
L1 | 0.12700/0.20320 | 100+/-10 | 0.11938/0.21082 | 100.4 | L2
L3 | 0.13970/0.17780 | 80+/-8 | 0.14732/0.17018 | 80.1 | L2&L4
L3 | 0.10414/0.20320 | 100+/-10 | 0.09398/0.21336 | 100.3 | L2&L4
L5 | 0.13970/0.17780 | 80+/-8 | 0.14732/0.17018 | 80.1 | L4&L6
L5 | 0.10414/0.20320 | 100+/-10 | 0.09398/0.21336 | 100.2 | L4&L6

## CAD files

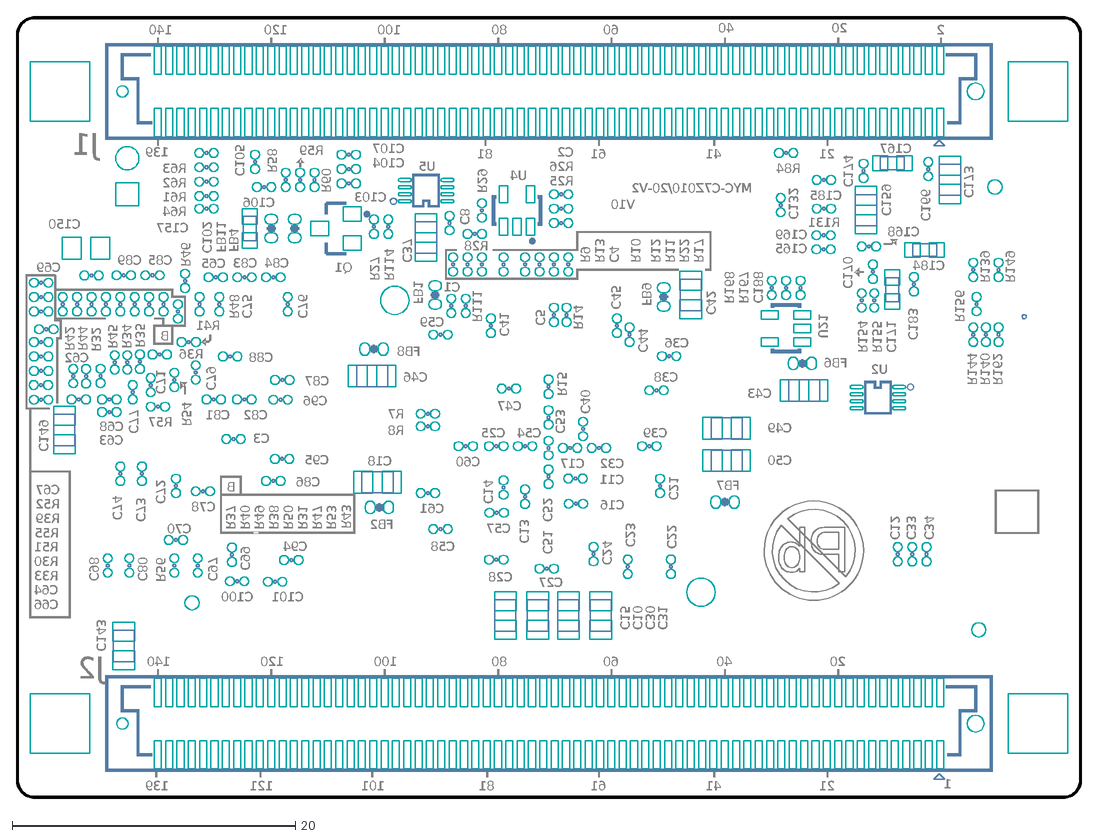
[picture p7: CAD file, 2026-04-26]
Documentation/MYIR Hardware/Mechanical/2D-DXF/BOTTOM.dxf
U2
U5
FB1
FB11
FB2
FB4
FB8
FB9
FB6
FB7
Q1
J1
J2
R139
R168
R167
R156
R155
R154
R144
R140
R131
R162
R149
R114
R111
R57
R56
R8
R7
R41
R54
R53
R52
R51
R50
R49
R48
R47
R46
R45
R44
R43
R42
R40
R39
R38
R37
R36
R35
R34
R33
R32
R31
R30
R29
R26
R84
R15
R14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

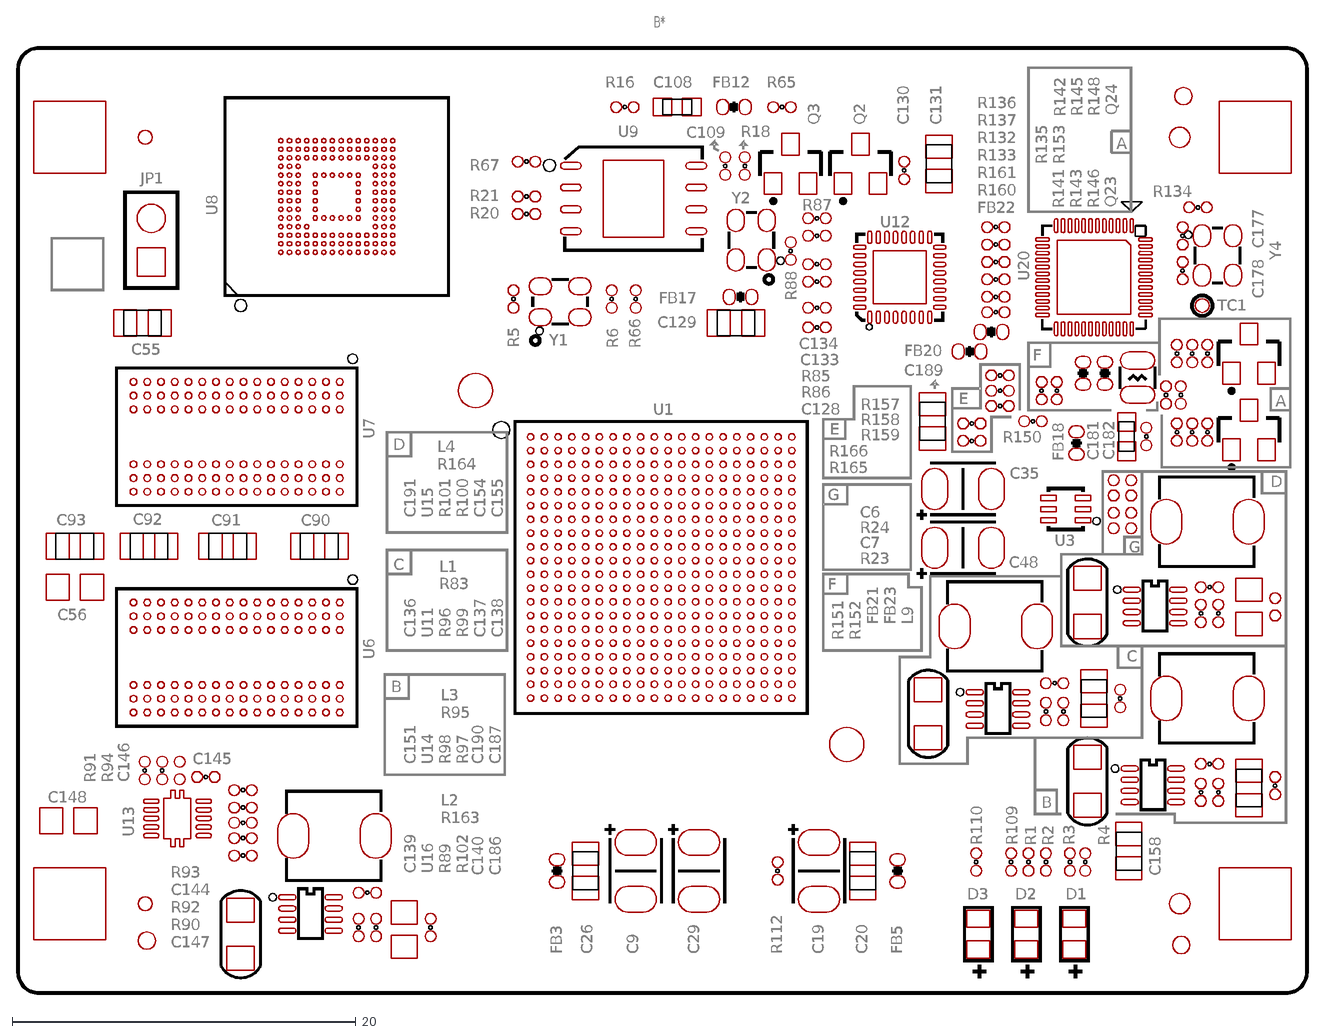
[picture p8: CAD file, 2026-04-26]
Documentation/MYIR Hardware/Mechanical/2D-DXF/TOP.dxf
B*
C19
C29
C35
C48
C9
U1
U12
U6
U7
U8
U9
U3
L4
L3
L2
L1
TC1
L9
FB12
FB17
FB18
FB3
FB5
FB22
FB21
FB20
FB23
Y1
Y2
Y4
U20
JP1
U16
U15
U11
U14
U13
Q23
Q24
Q2
Q3
D1
D2
D3
R151
R150
R166
R165
R161
R160
R159
R158
R157
R141
R135
R134
R148
R146
R145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

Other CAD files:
Documentation/MYIR Hardware/Misc/MYB-C7Z010_20_Allegro_Package_LIB/12pin2_54_90degrees.psm
Documentation/MYIR Hardware/Misc/MYB-C7Z010_20_Allegro_Package_LIB/4pin5.psm
Documentation/MYIR Hardware/Misc/MYB-C7Z010_20_Allegro_Package_LIB/5177984-6.psm
Documentation/MYIR Hardware/Misc/MYB-C7Z010_20_Allegro_Package_LIB/74737-0009.psm
Documentation/MYIR Hardware/Misc/MYB-C7Z010_20_Allegro_Package_LIB/7pin-sasa.psm
Documentation/MYIR Hardware/Misc/MYB-C7Z010_20_Allegro_Package_LIB/asp-134603-01.psm
Documentation/MYIR Hardware/Misc/MYB-C7Z010_20_Allegro_Package_LIB/b0505s.psm
Documentation/MYIR Hardware/Misc/MYB-C7Z010_20_Allegro_Package_LIB/bar2pts02.psm
Documentation/MYIR Hardware/Misc/MYB-C7Z010_20_Allegro_Package_LIB/bar3pts02.psm
Documentation/MYIR Hardware/Misc/MYB-C7Z010_20_Allegro_Package_LIB/c0402.psm
Documentation/MYIR Hardware/Misc/MYB-C7Z010_20_Allegro_Package_LIB/c0603.psm
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

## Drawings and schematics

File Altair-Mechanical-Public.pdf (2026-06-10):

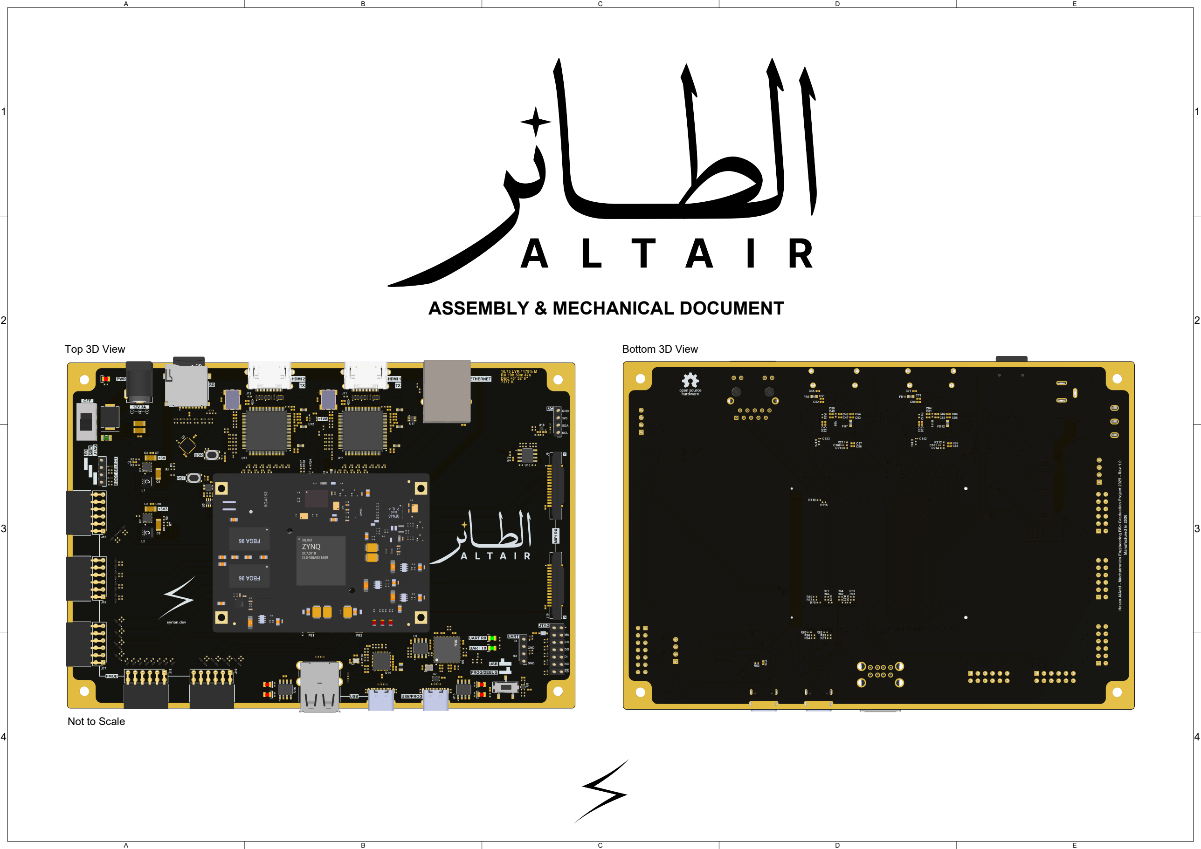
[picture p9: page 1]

A

B

C

D

E

1 | 1
2 | 2
3 | 3
4 | 4

# ASSEMBLY & MECHANICAL DOCUMENT

Top 3D View | Bottom 3D View

Not to Scale

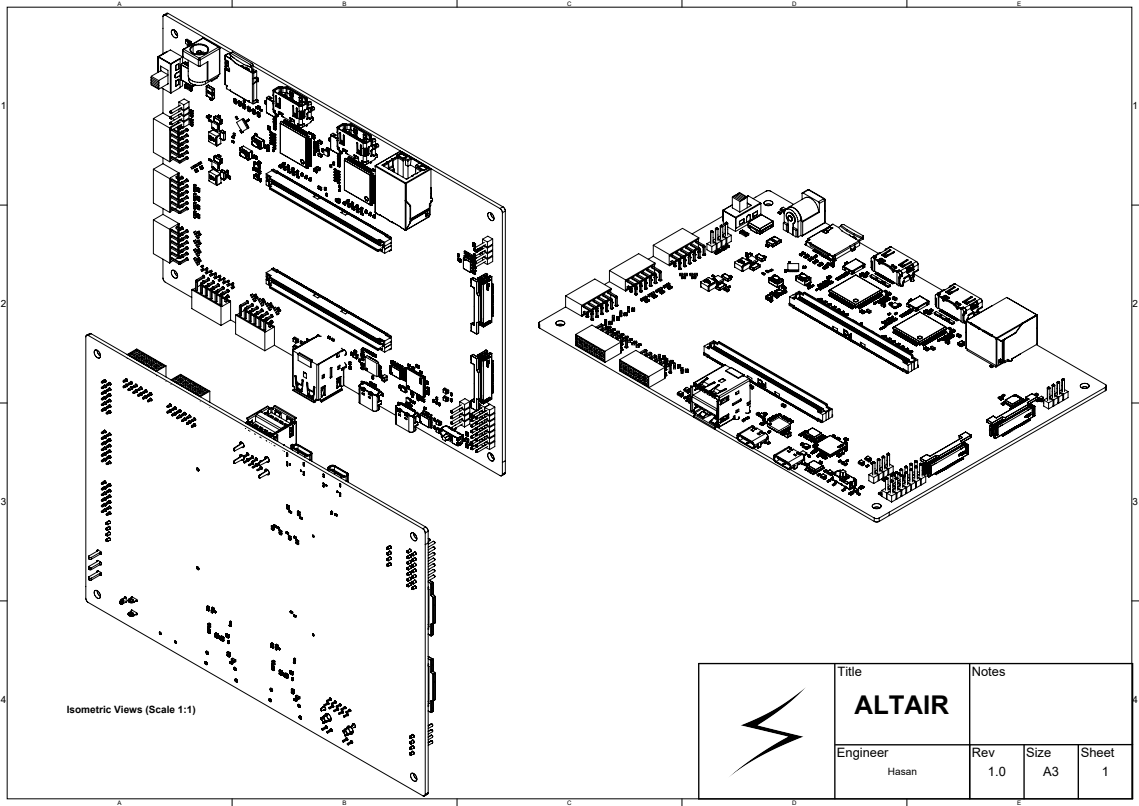
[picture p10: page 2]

Title ALTAIR | Notes

Isometric Views (Scale 1:1)

Engineer Hasan | Rev 1.0 | Size A3 | Sheet 1

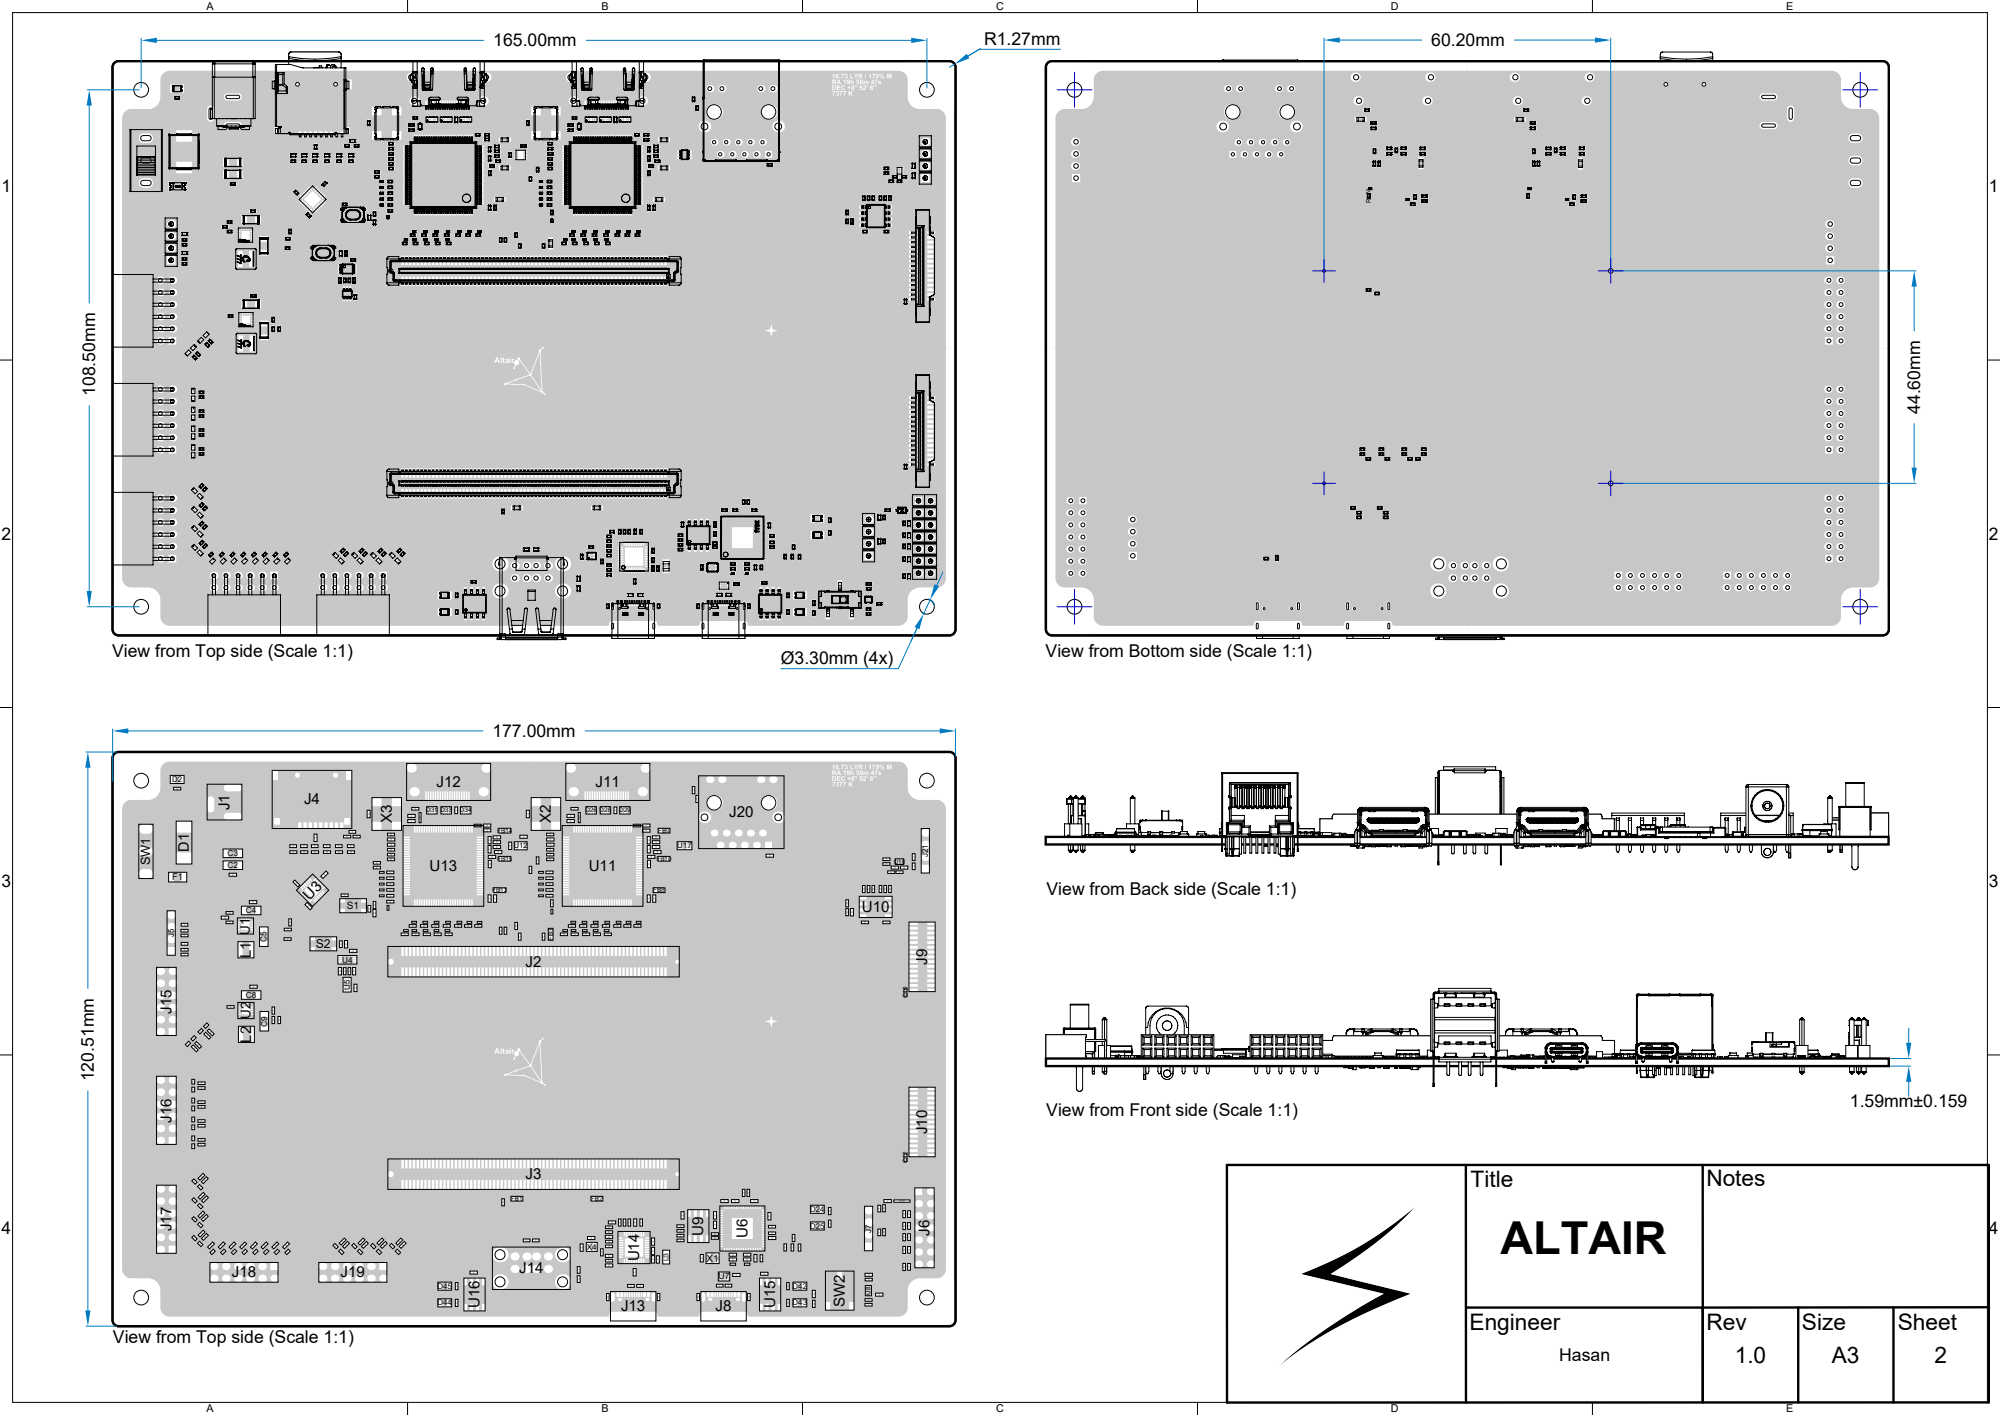
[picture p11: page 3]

View from Top side (Scale 1:1)

View from Bottom side (Scale 1:1)

View from Back side (Scale 1:1)

View from Front side (Scale 1:1)

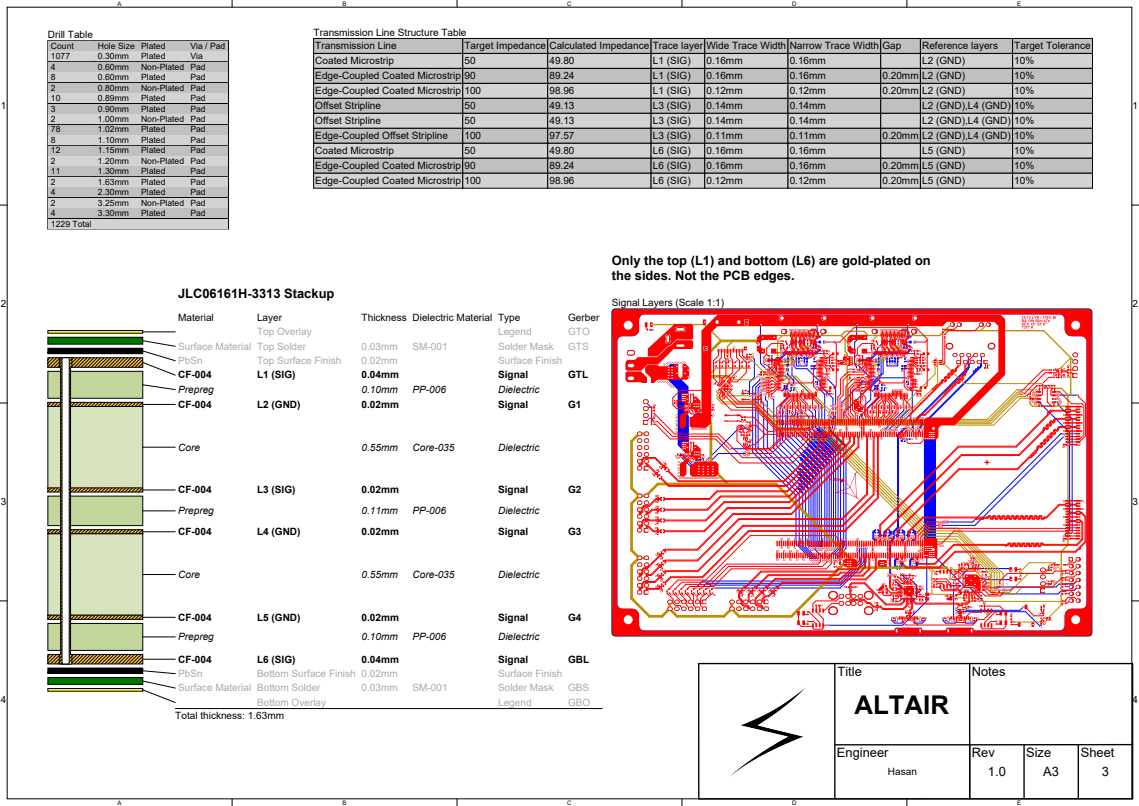
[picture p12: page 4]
Material; Layer; Thickness Dielectric Material Type; Gerber; Top Overlay; Legend; GTO; Surface Material Top Solder; Solder Mask; GTS; PbSn; Top Surface Finish; Surface Finish; L1 (SIG); Signal; GTL; Prepreg; Dielectric; L2 (GND); Core; Core-035; L3 (SIG); L4 (GND); L5 (GND); L6 (SIG); GBL; Bottom Surface Finish 0.02mm; Surface Material Bottom Solder; GBS; Bottom Overlay; GBO; Total thickness: 1.63mm; Title ALTAIR; Notes; Count 1077 4 8 2 10 3 2 78 8 12 2 11 2 4 2 4 1229 Total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

Transmission Line Structure Table
Transmission Line
Coated Microstrip
Edge-Coupled Coated Microstrip
Offset Stripline
Edge-Coupled Offset Stripline

Only the top (L1) and bottom (L6) are gold-plated on
the sides. Not the PCB edges.

Signal Layers (Scale 1:1)

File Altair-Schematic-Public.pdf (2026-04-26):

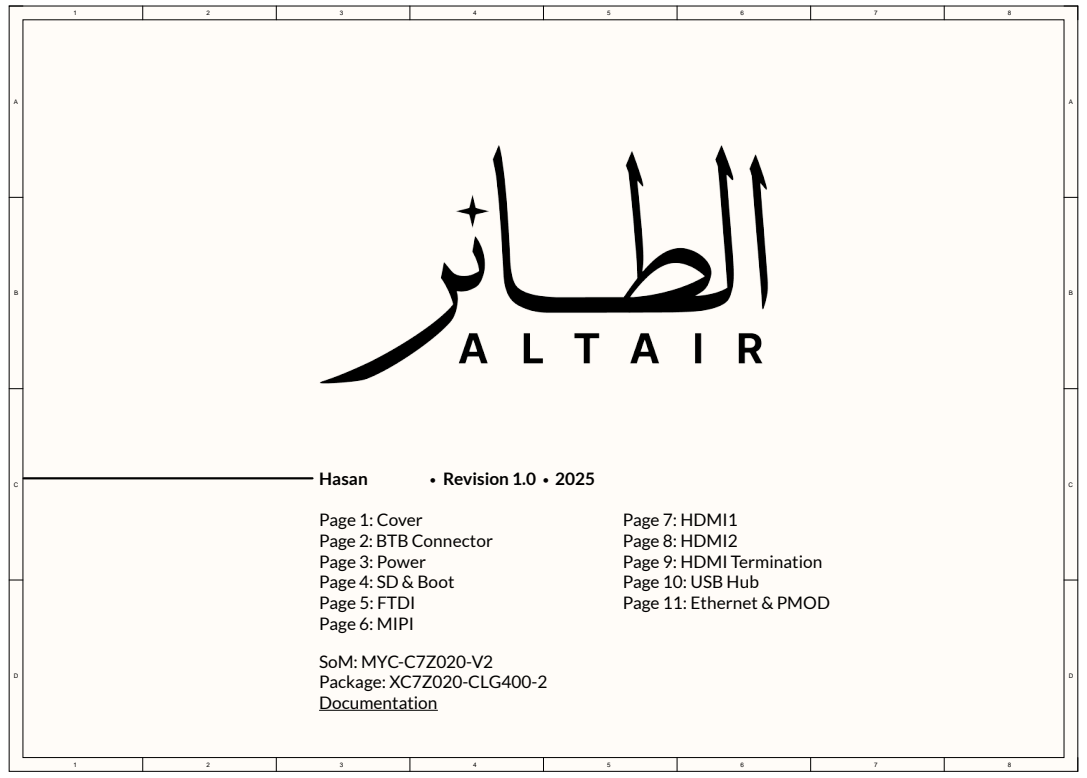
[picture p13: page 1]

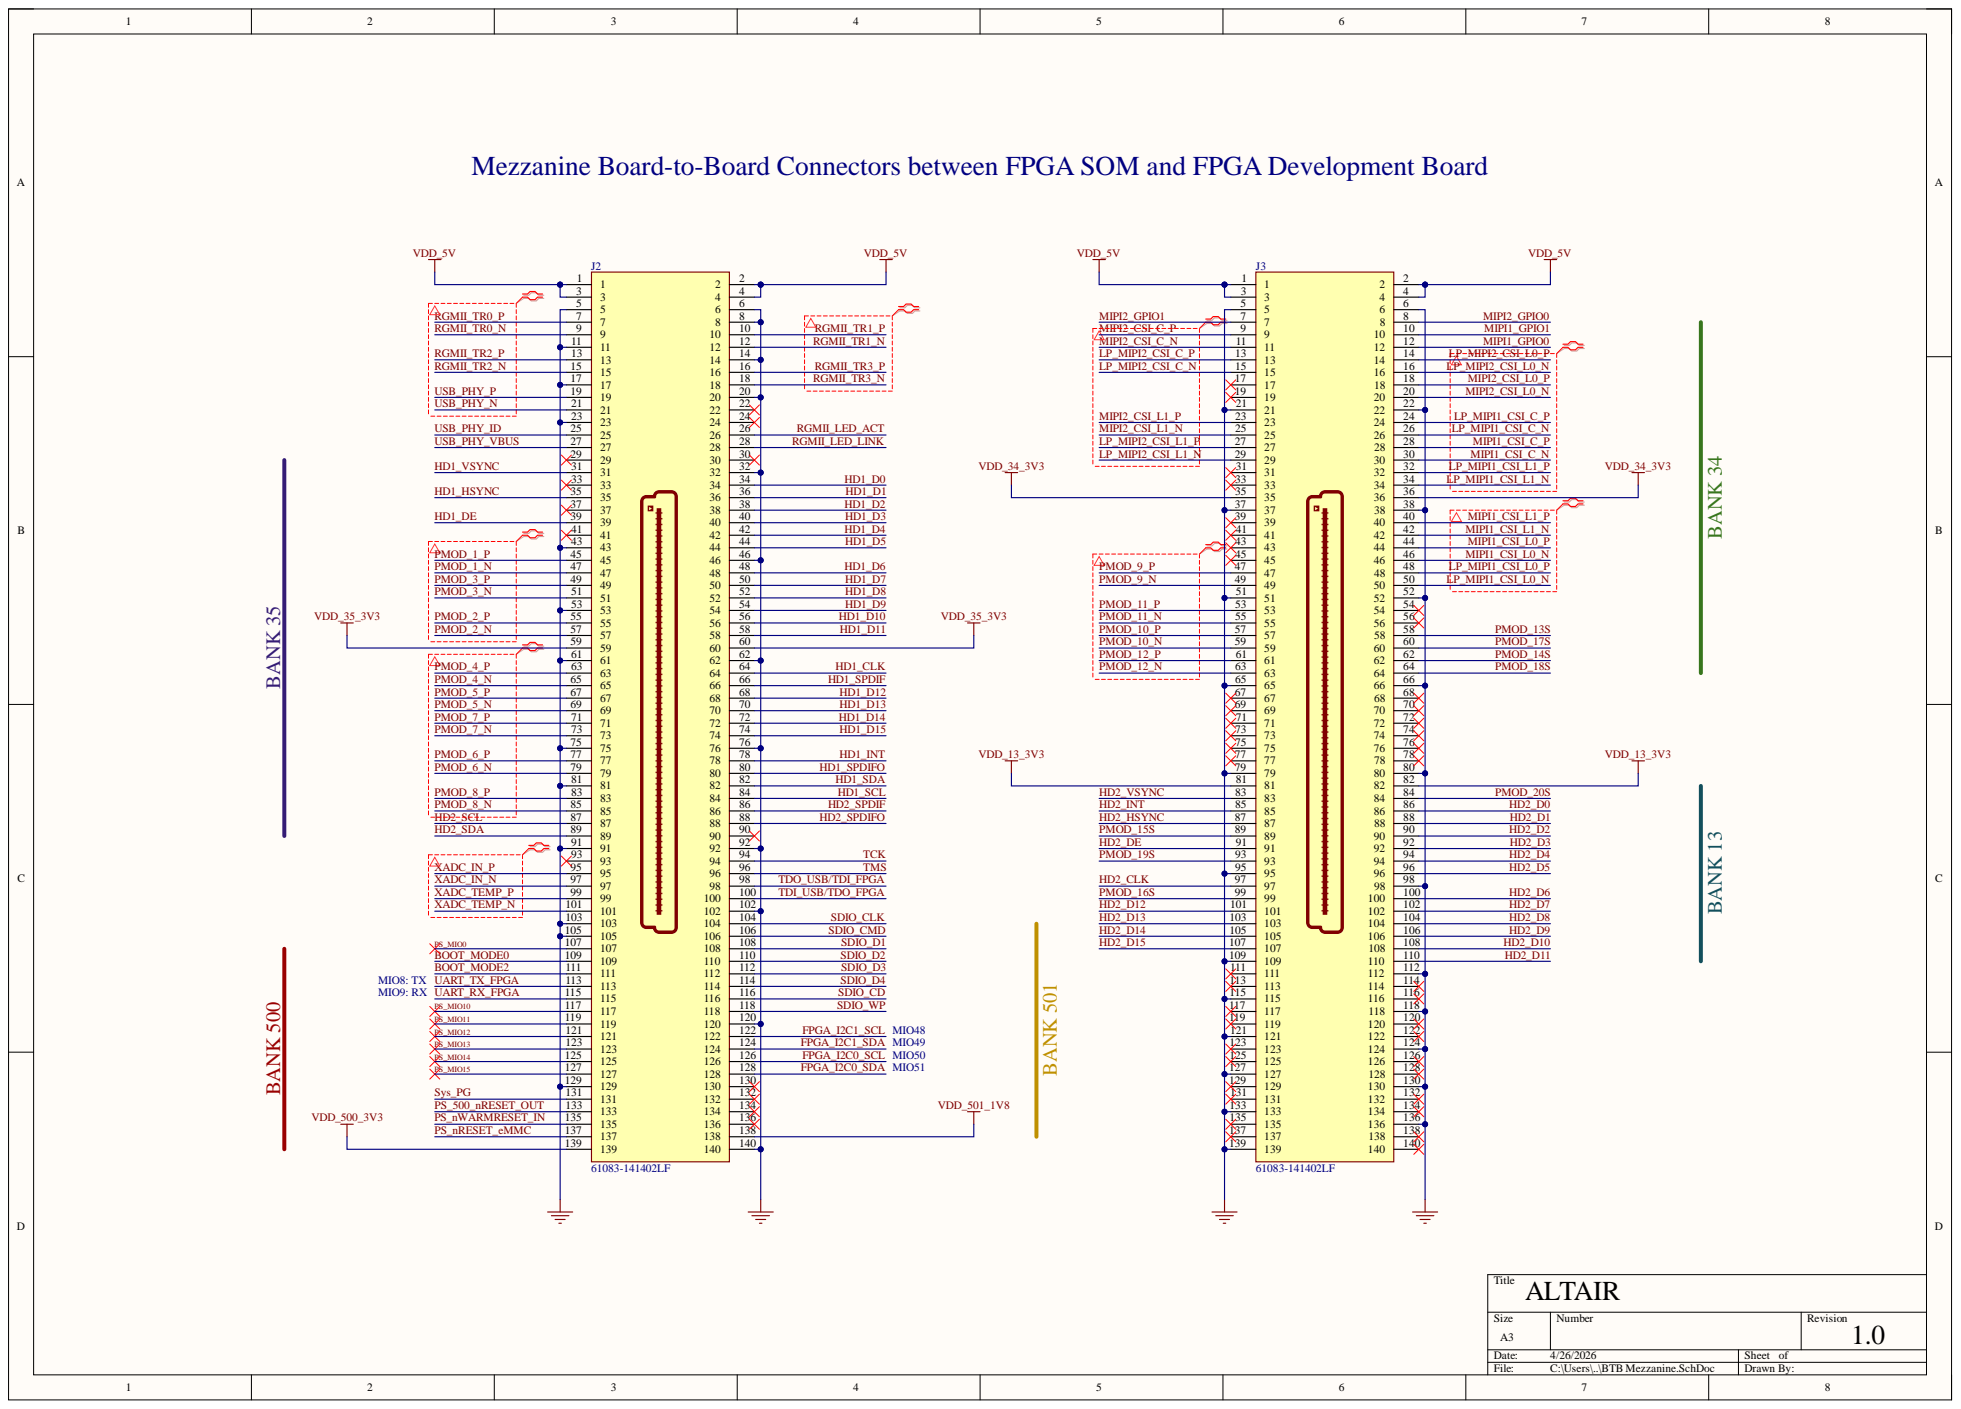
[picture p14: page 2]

Mezzanine Board-to-Board Connectors between FPG

LP_M IPI2_CSI_L1_N | M

LP_M IPI1_CSI_L1_P

IPI1_CSI_L0_N MIPI1_CSI_L0_P

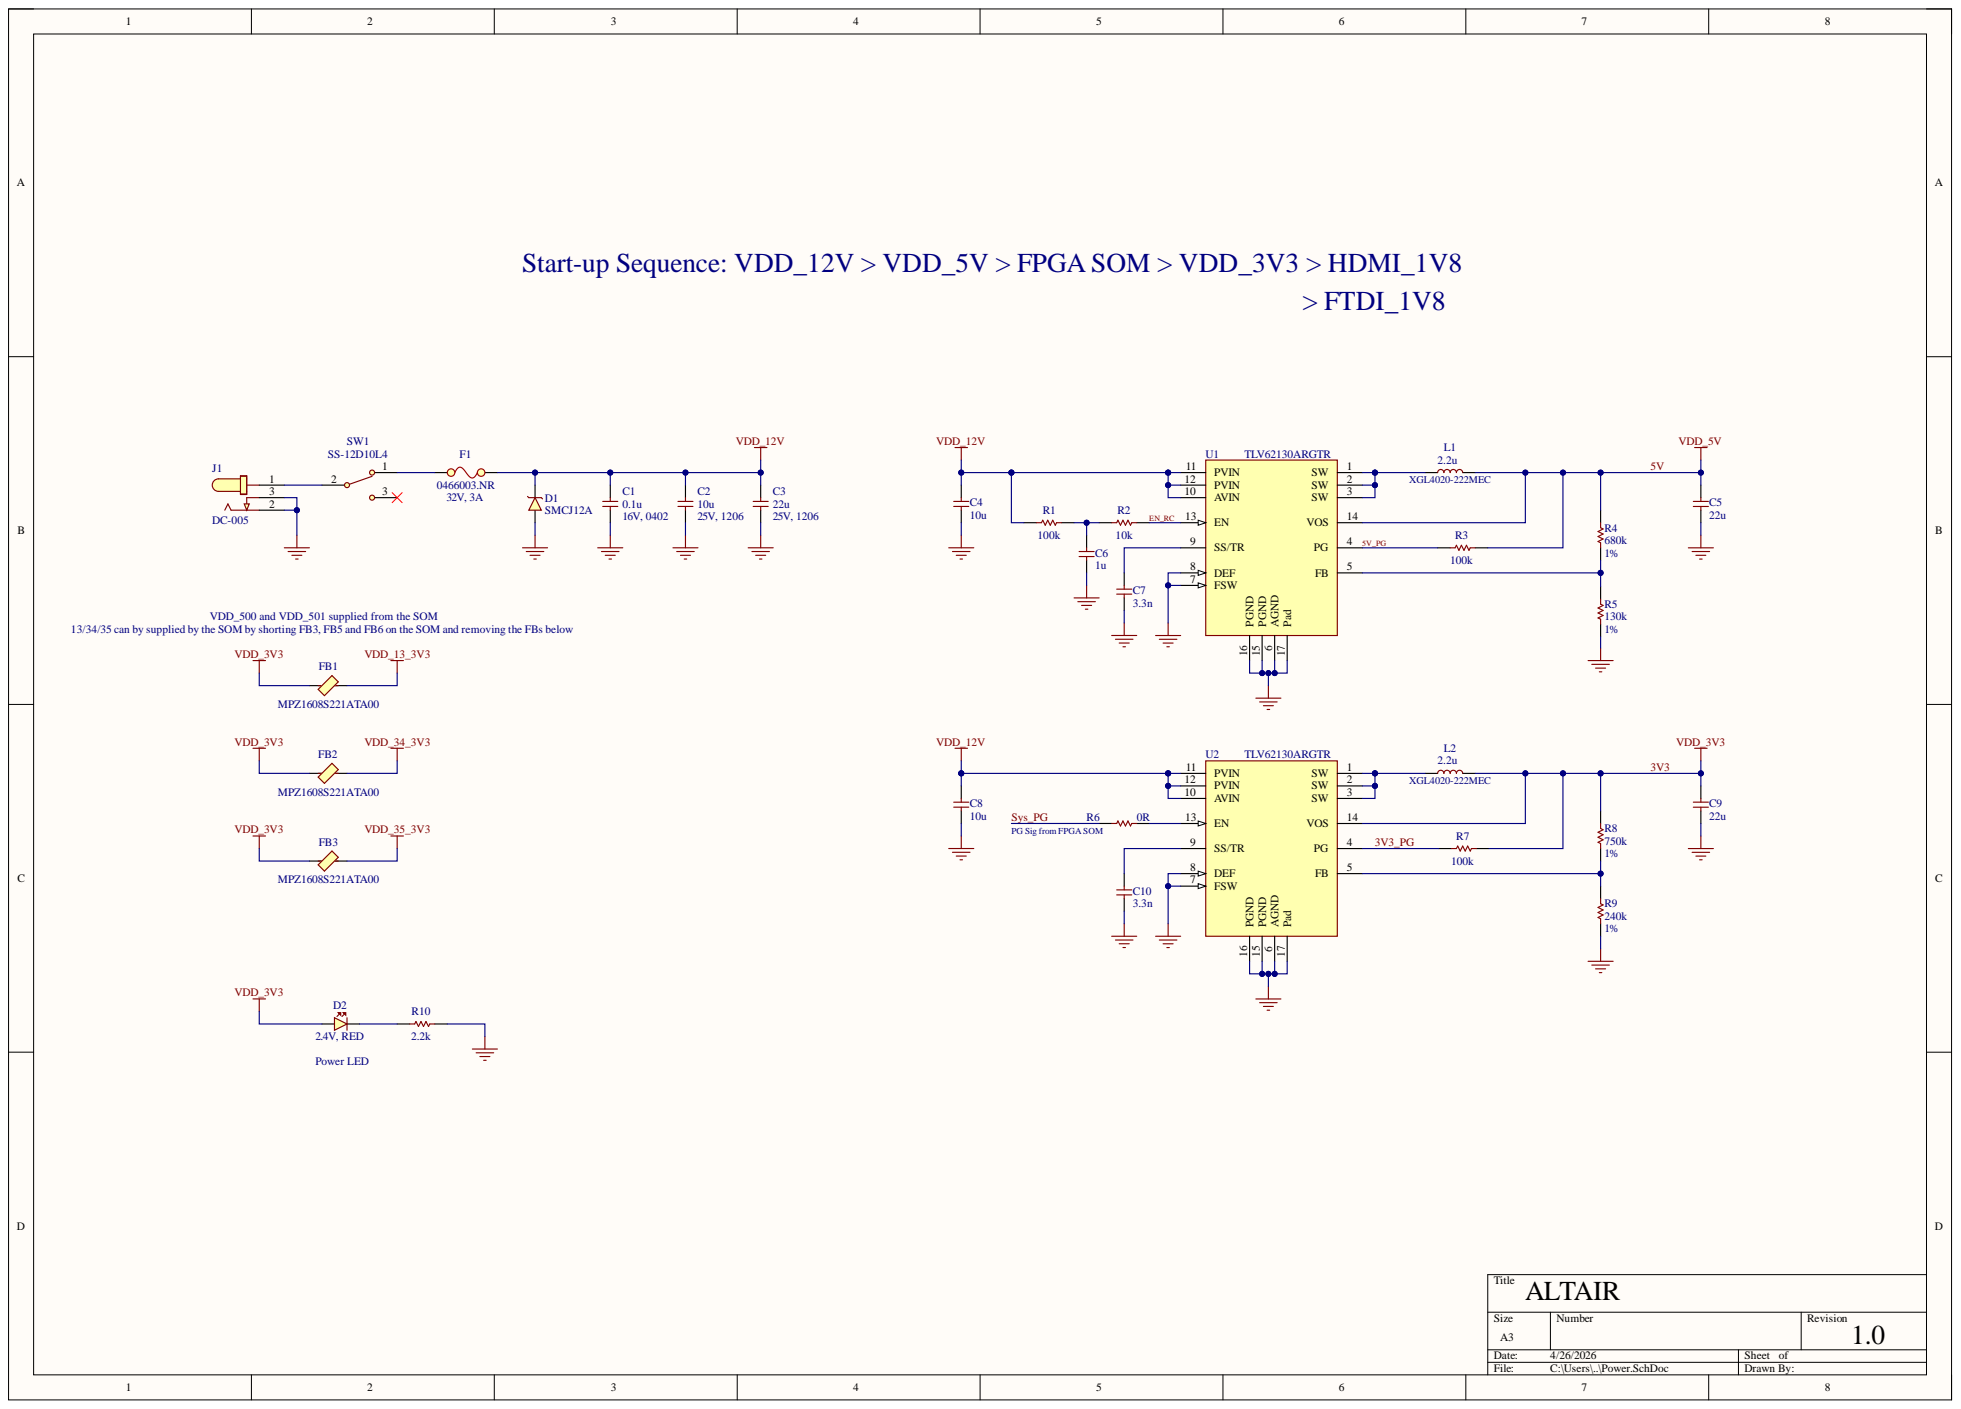
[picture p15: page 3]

ied from the SO

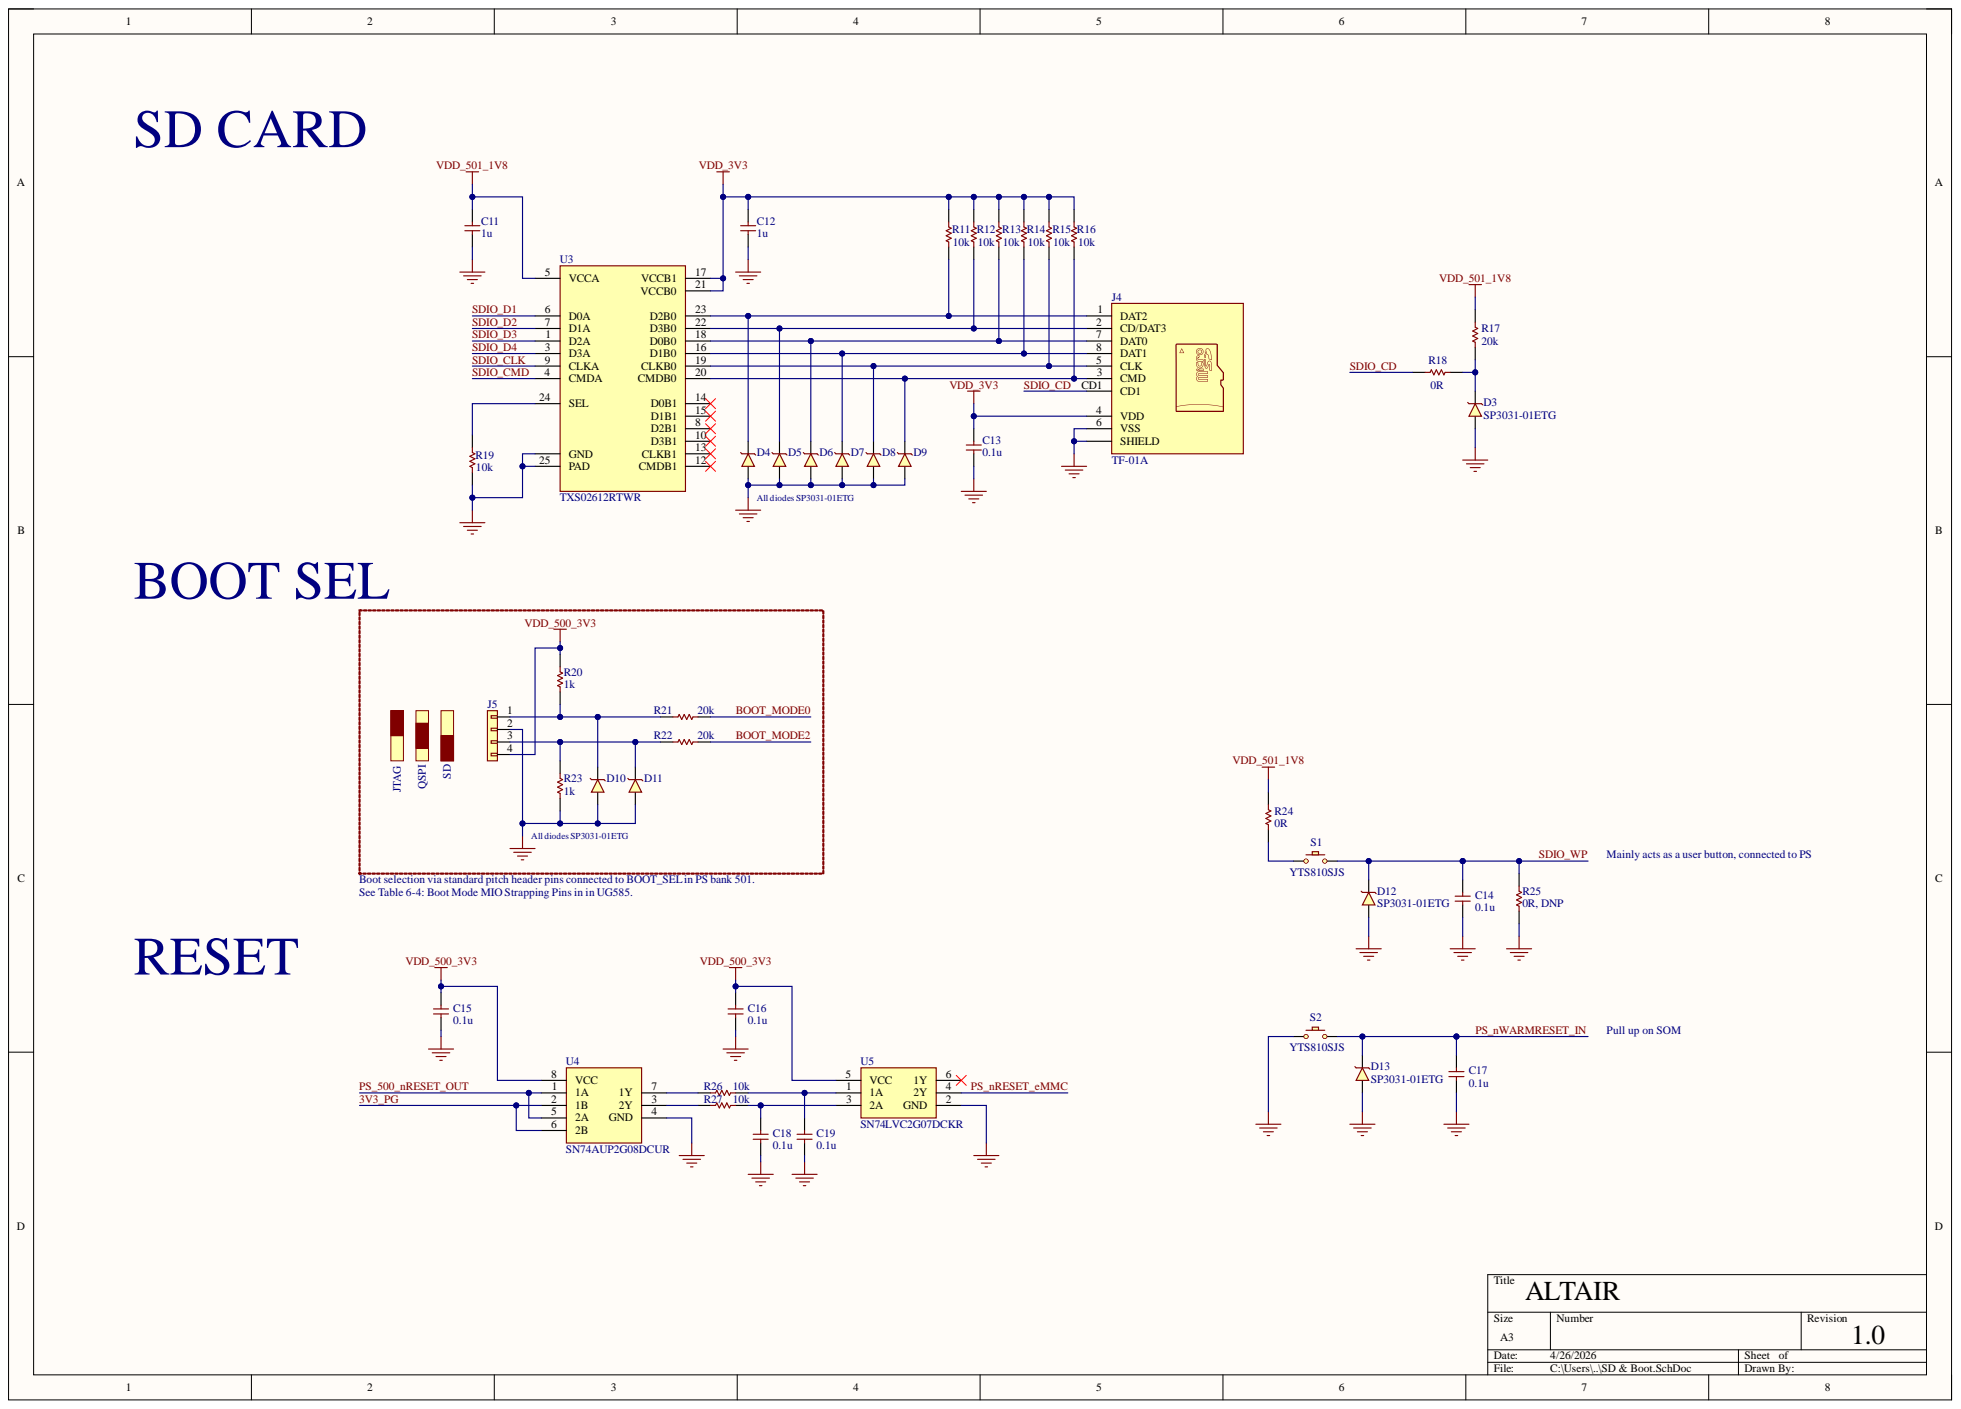
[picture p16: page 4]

Boot selection via standard pitch header pins connected to BOOT_SELin PS bank 501.
See Table 6-4: Boot Mode MIO Strapping Pins in in UG585.

Pull up on SOM

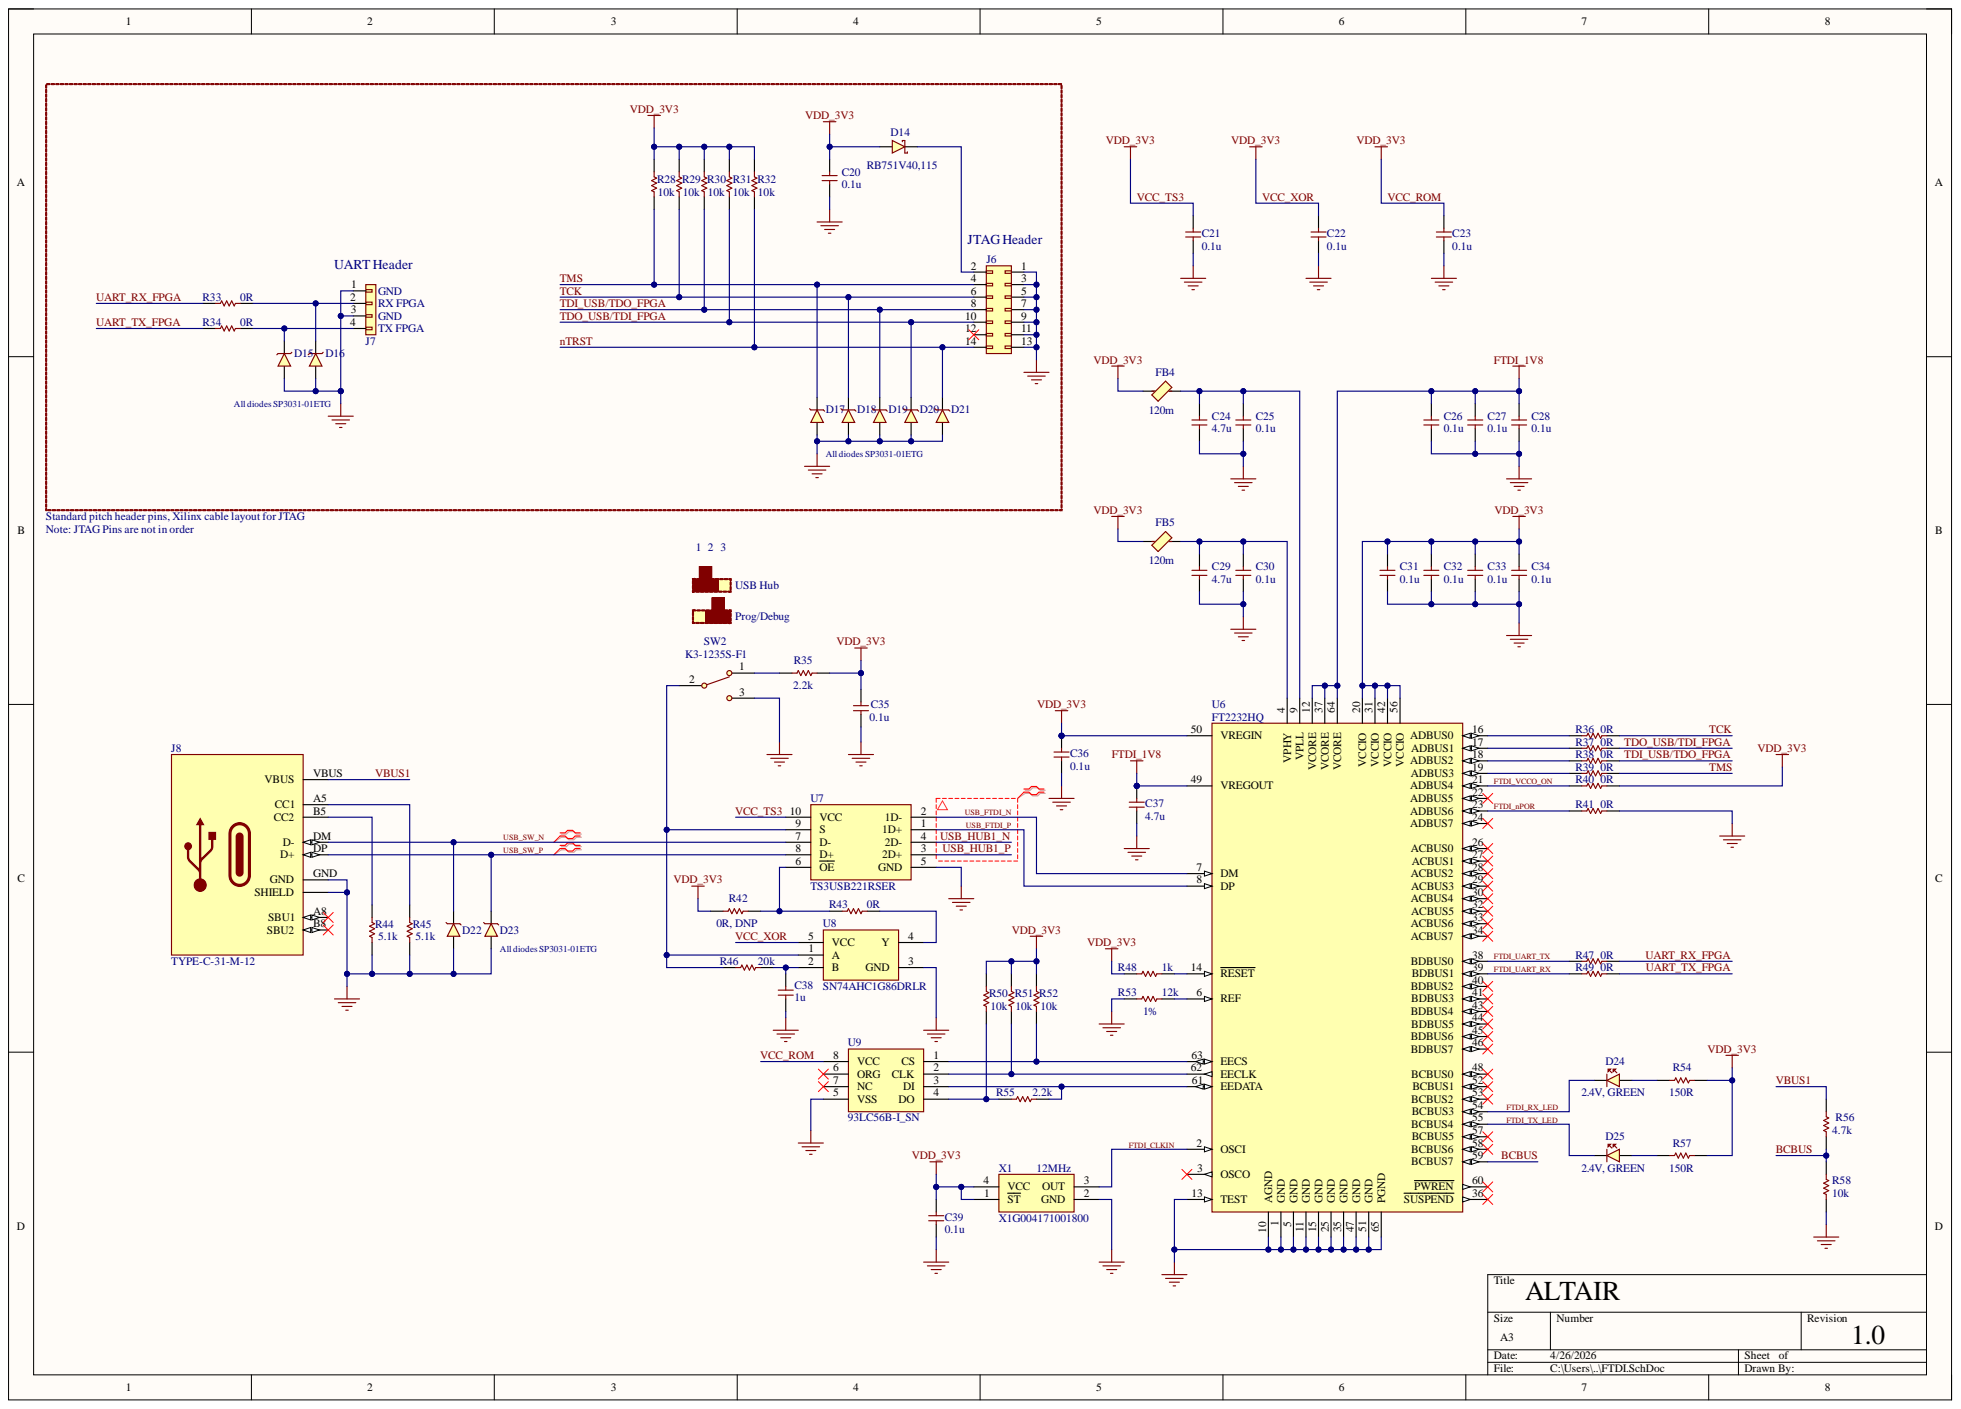
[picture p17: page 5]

Standard pitch header pins, Xilinx cable layout for JTAG
Note: JTAG Pins are not in order

DM 7
DP 8

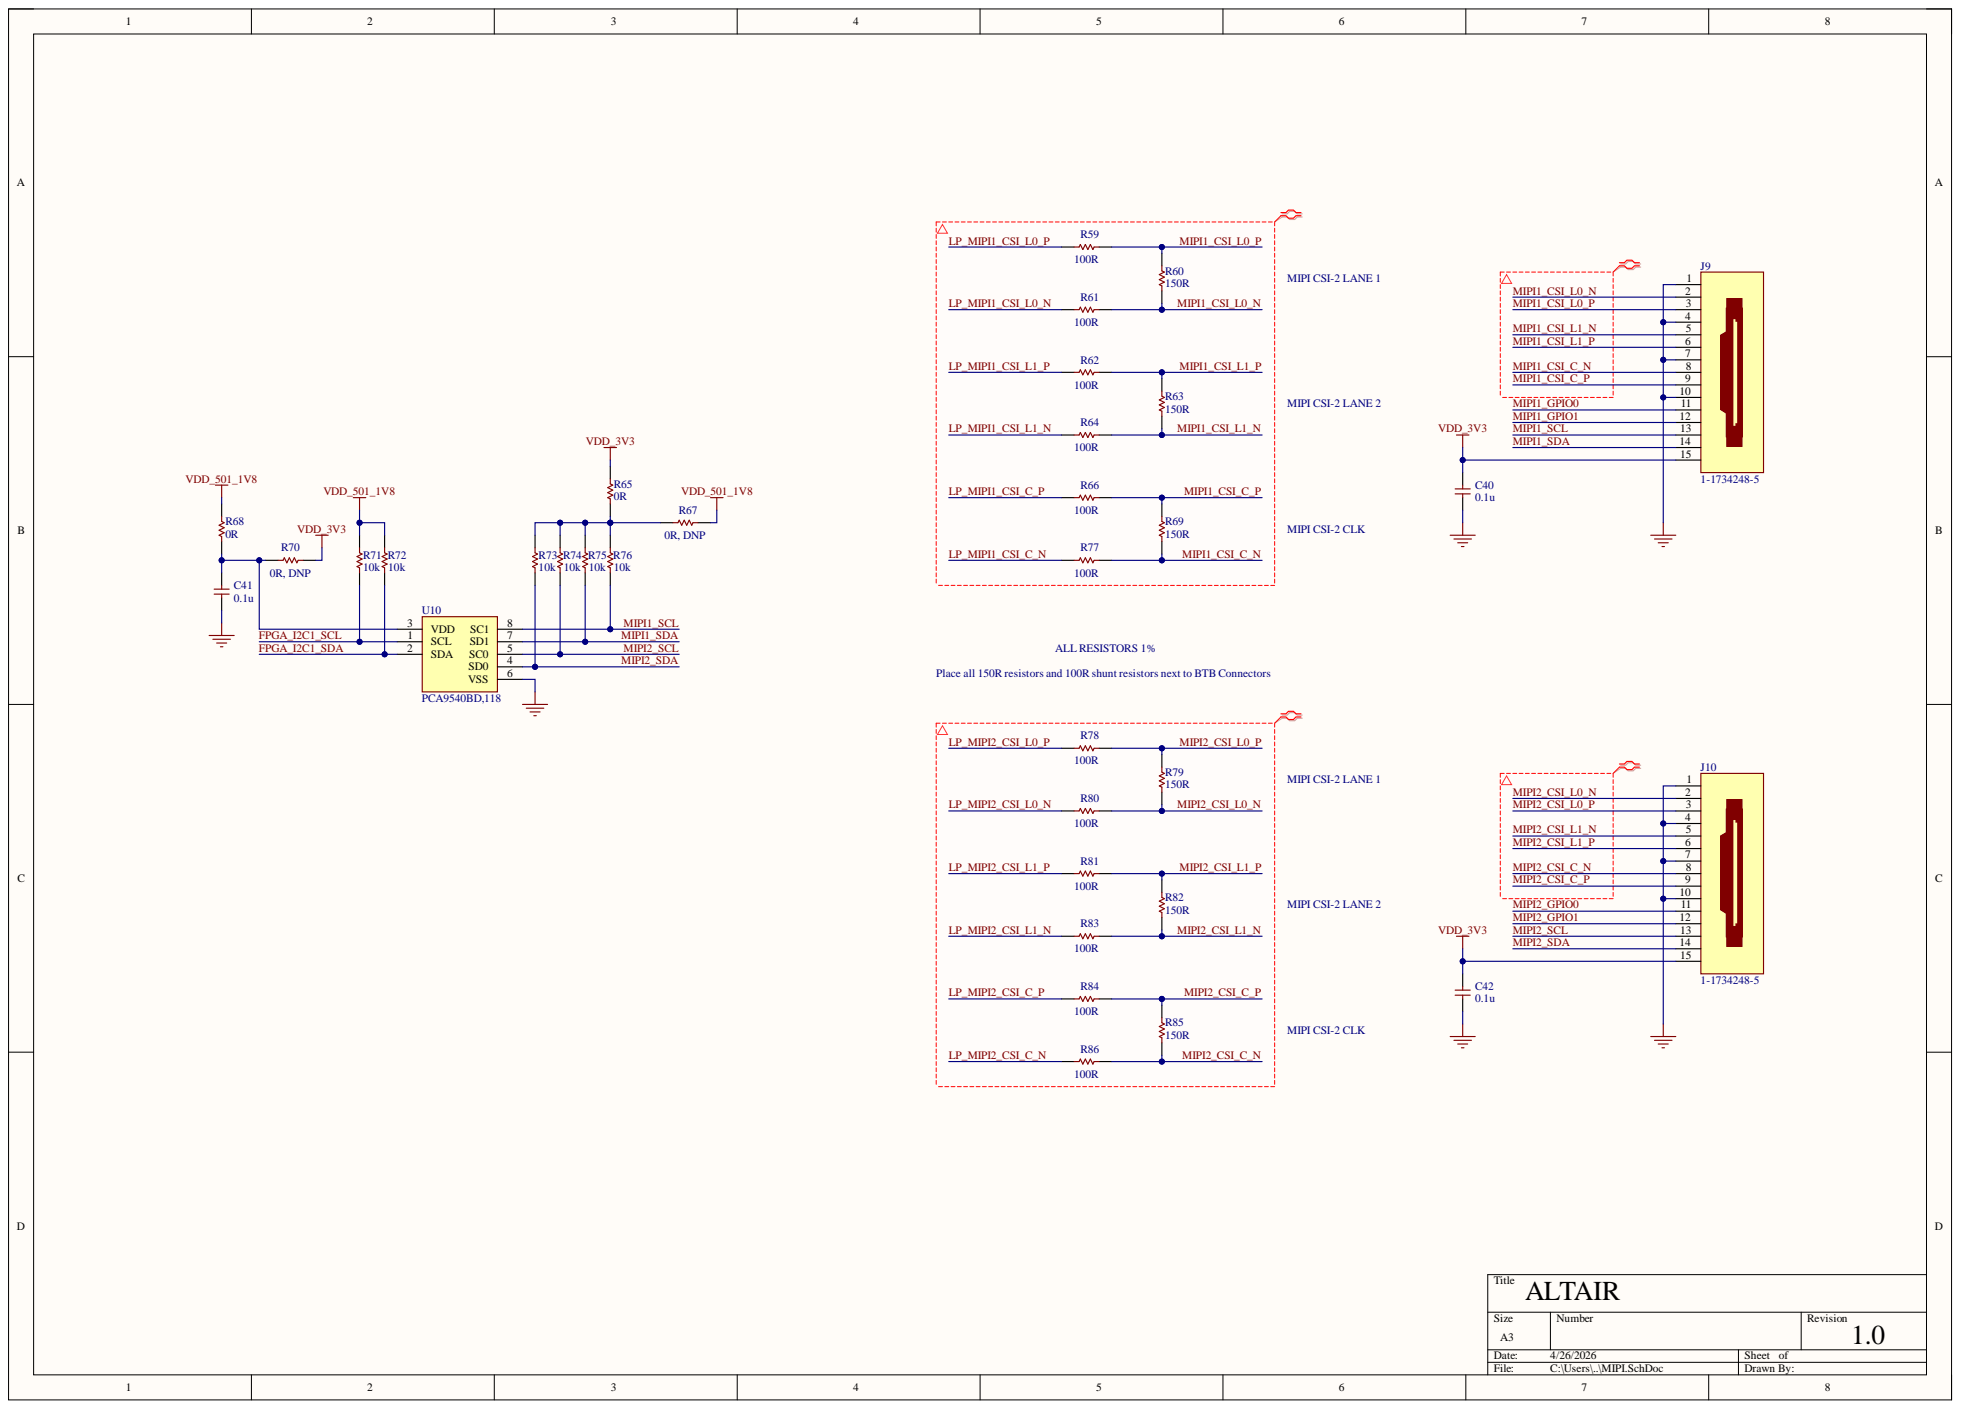
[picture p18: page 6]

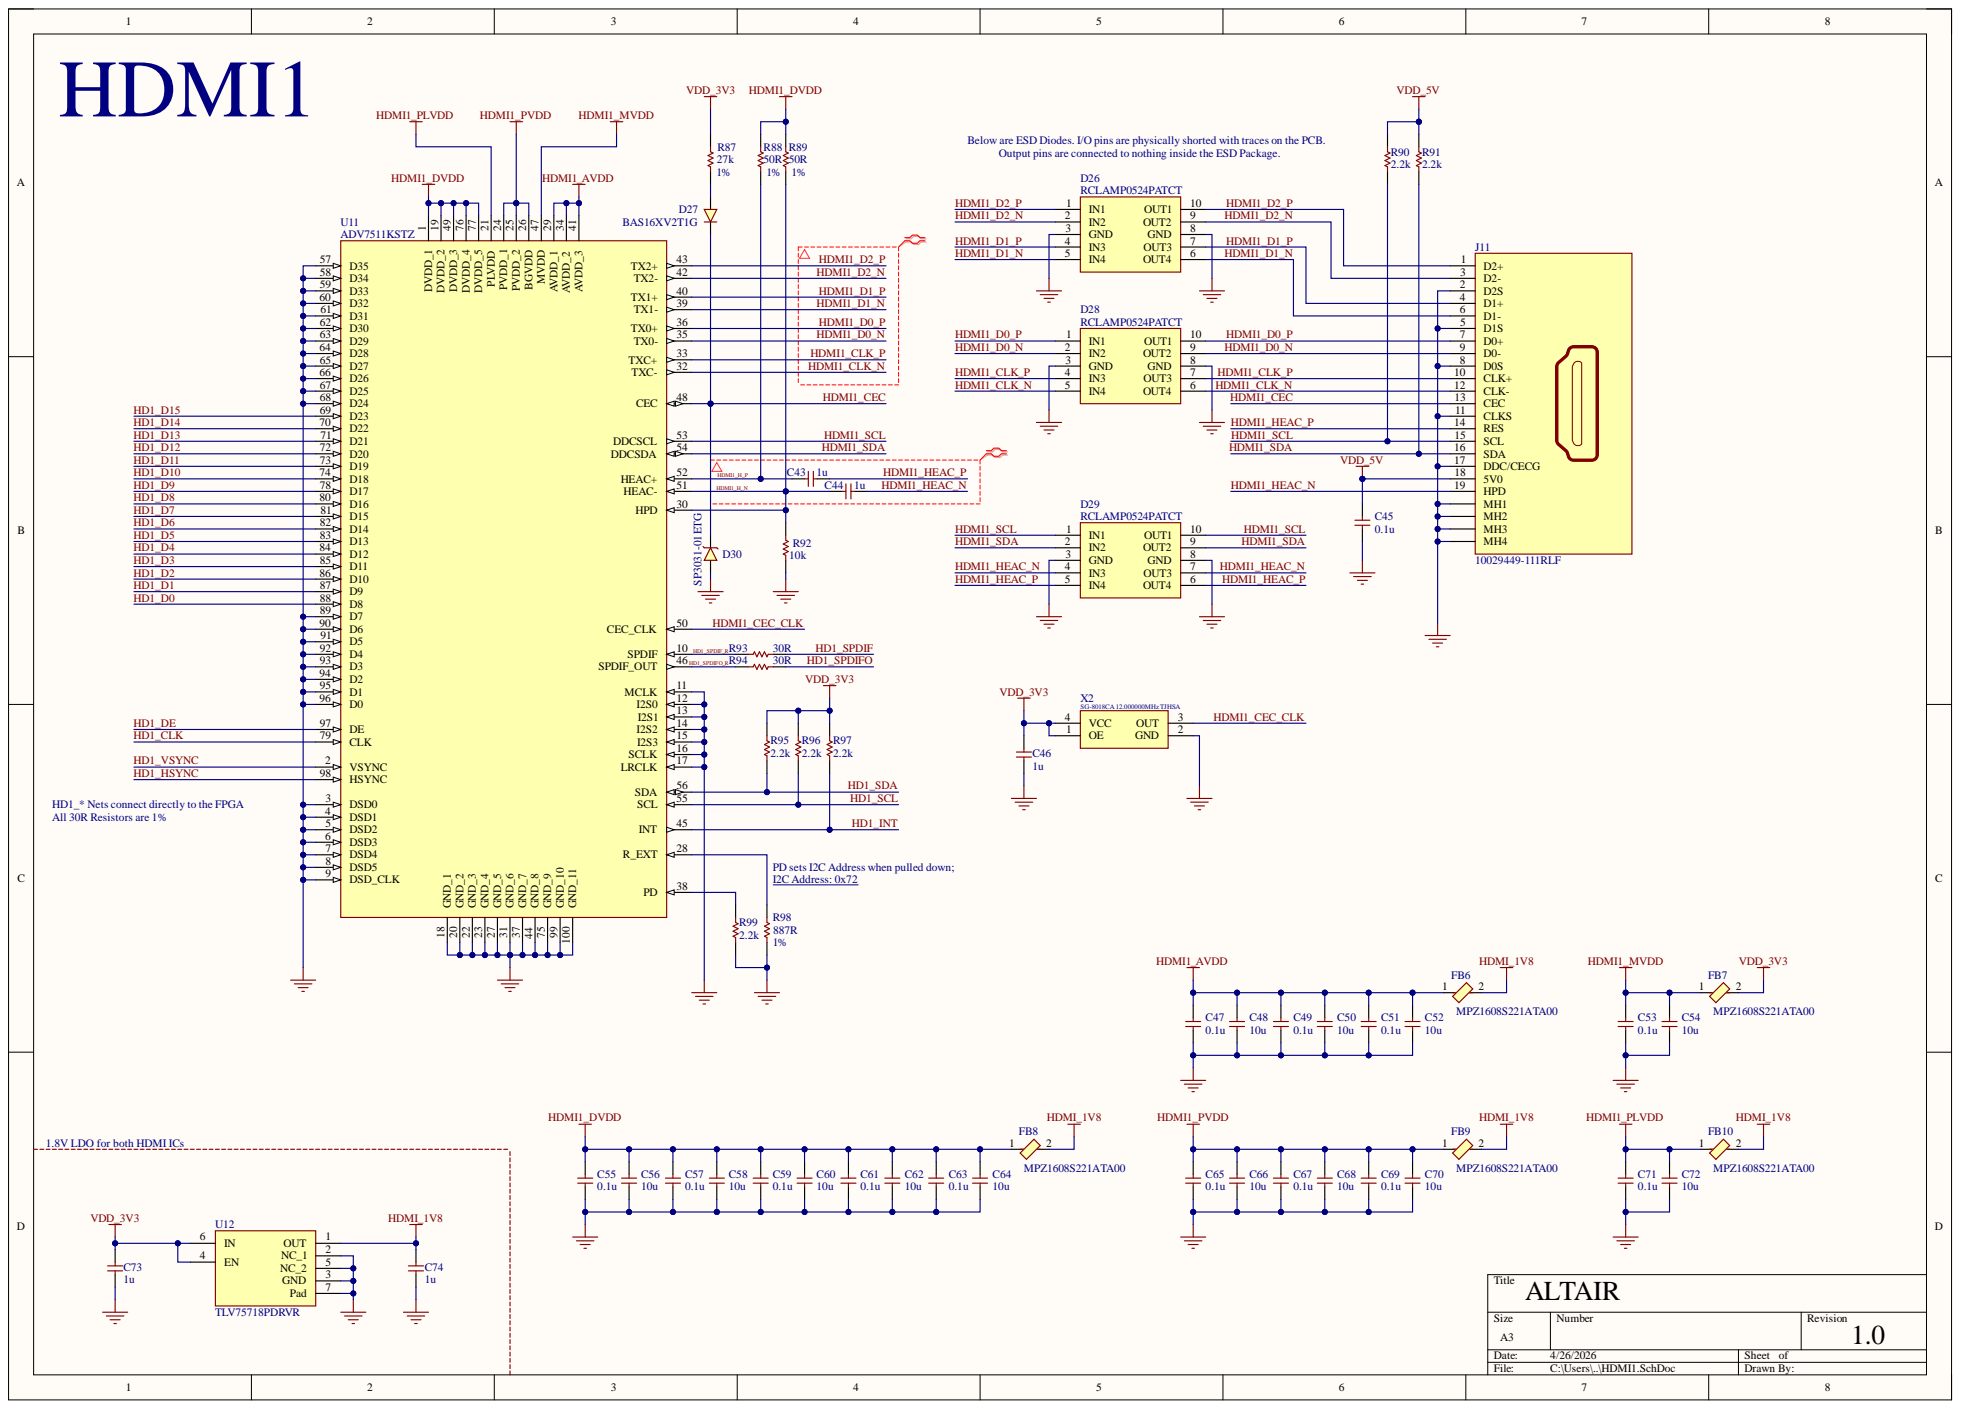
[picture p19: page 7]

Below are ESD Diodes. I/O pins are physically shorted with traces on the PCB.
Output pins are connected to nothing inside the ESD Package.

HDMI1_D1_P
HDMI1_D1_N

HD1_* Nets connect directly to the FPGA
All 30R Resistors are 1%

PD sets I2C Address when pulled down;
I2C Address: 0x72

1.8V LDO for both HDMI ICs

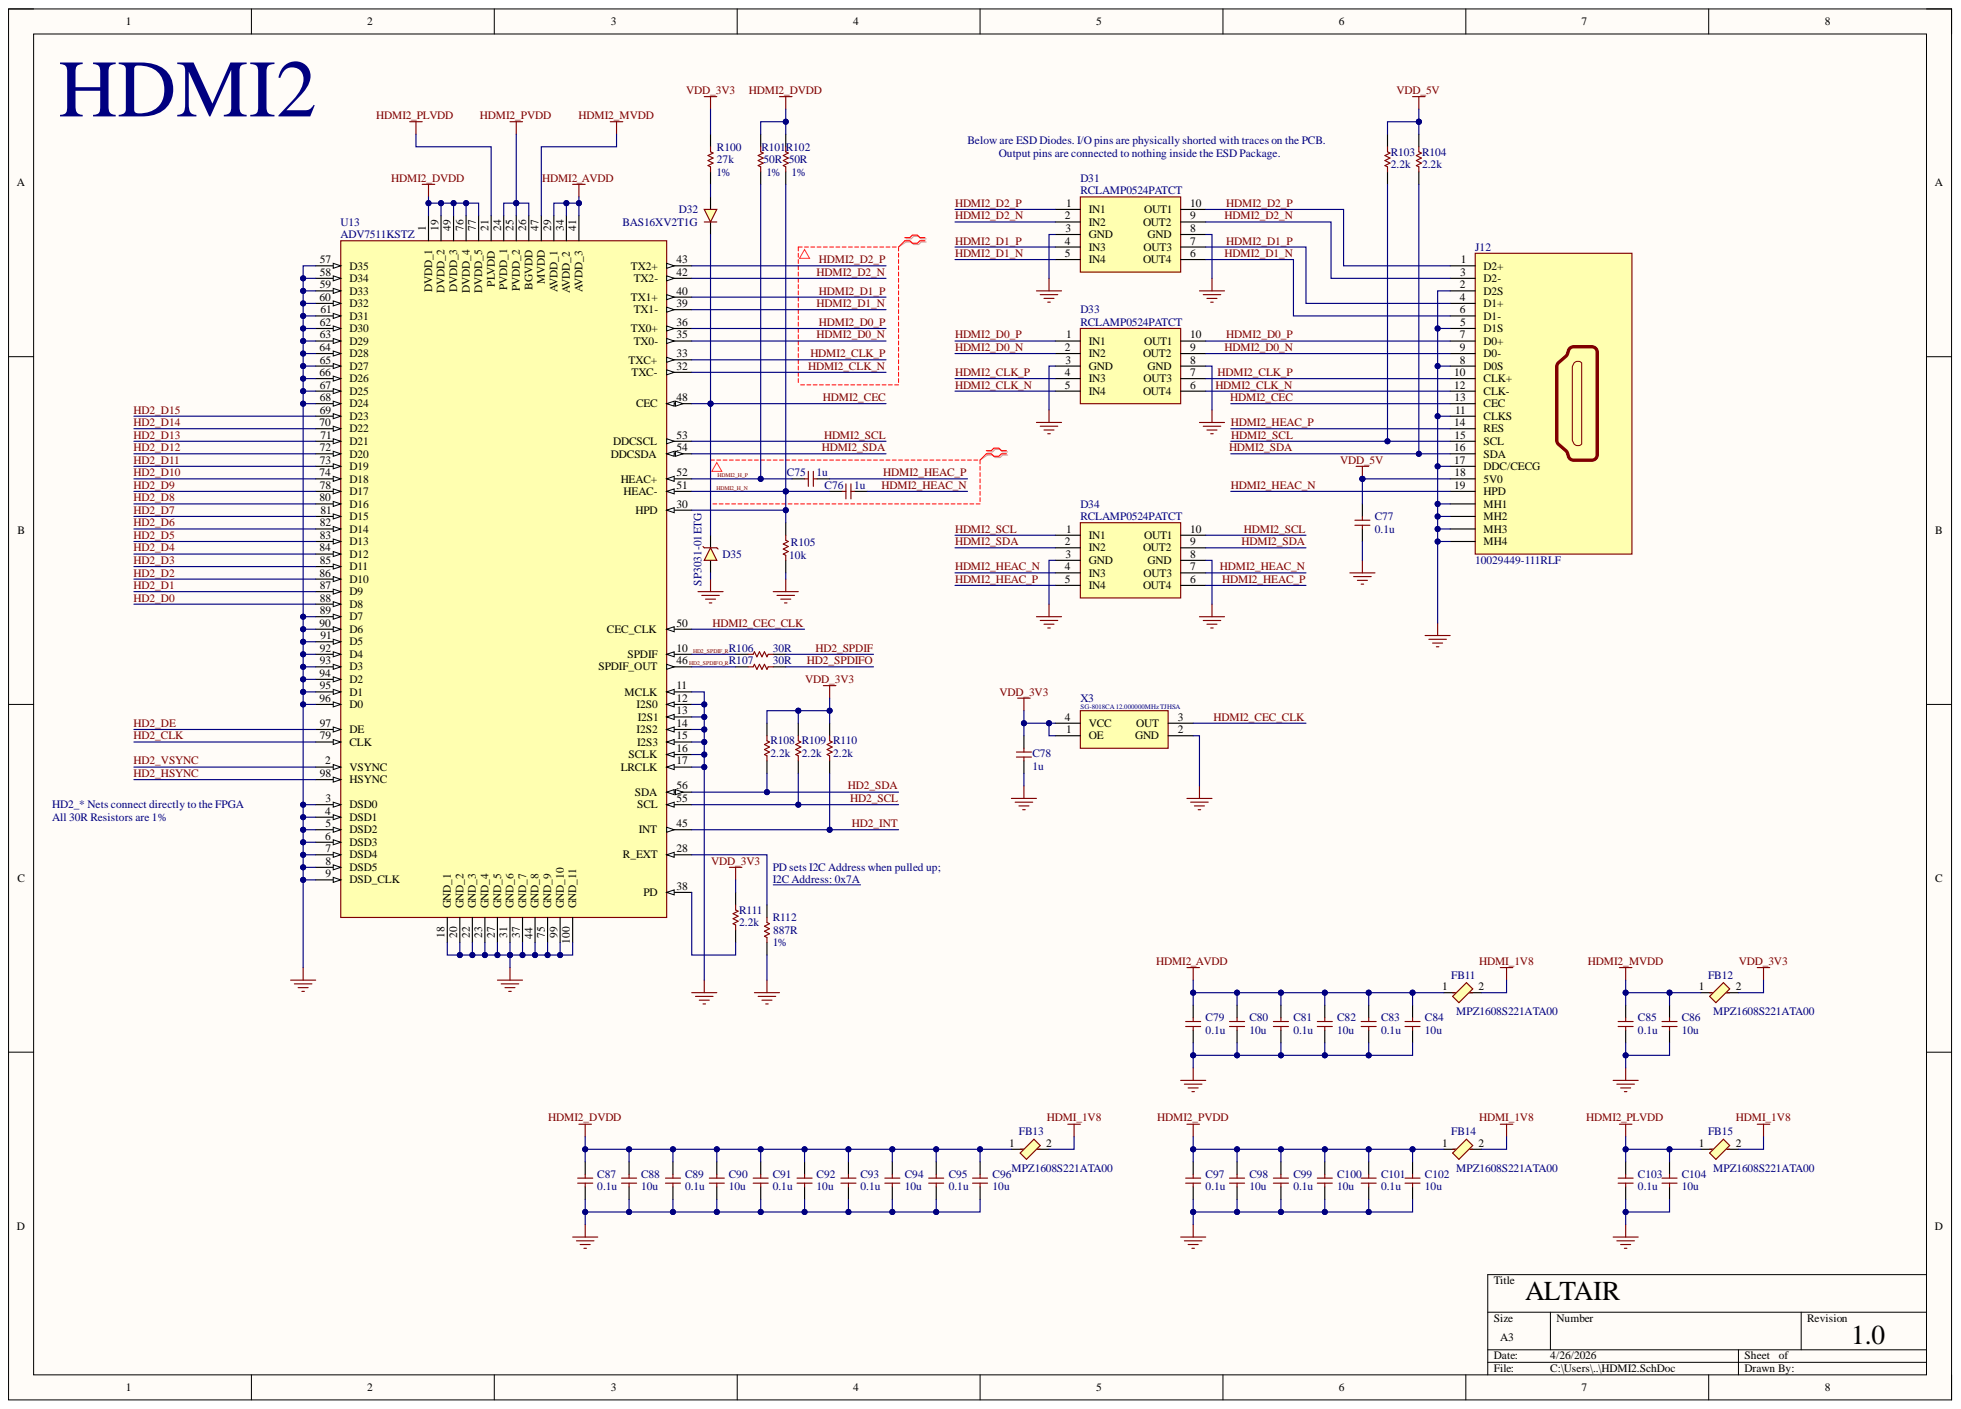
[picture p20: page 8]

Below are
Output pins are connected

9 | H D M I2_D2_N


All resistors are 1% 55R 0402 DNP
All capacitors are 0.1u 0201


USB_HUB2_P | | D+ DP

USB_HUB1_N USB_HUB1_P | | | GND


PMOD via standard pitch header pins connected to Bank 13.
All ESD Diodes SP3022-01ETG.

2 | HEADER_SDA SCL | A2 3


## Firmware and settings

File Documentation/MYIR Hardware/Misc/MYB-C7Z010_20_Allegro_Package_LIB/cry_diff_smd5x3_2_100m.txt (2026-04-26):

(DEVICE FILE: CRY_DIFF_SMD5X3_2_100M)

PACKAGE SMD5X3_2
CLASS IC
PINCOUNT 6

PINORDER CRY_DIFF_SMD5X3_2_100M GND NC OE 'OUT+' 'OUT-' VDD
FUNCTION G1 CRY_DIFF_SMD5X3_2_100M 3 2 1 4 5 6

PACKAGEPROP PART_NAME CRY_DIFF
PACKAGEPROP VALUE 100M

END
